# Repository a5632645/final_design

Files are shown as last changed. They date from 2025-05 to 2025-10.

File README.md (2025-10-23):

# final_design/毕业设计
This is my final design.  
这是我的本科毕业设计.  
> [!WARNING]
> don't try to rebuild hardware, it has too many incorrect design, that will just waste your time and money.  
> 请不要试着复刻硬件，有很多设计不合理的地方，复刻只会浪费你的时间和钱  

# digital waveguide synthesizer/数字波导合成器  
This is a MPE capability digital waveguide synthesizer.It has plucked, woodwind and bowed engine.Or you can use it as a MPE midi keyboard(only one octave).  
这是一个mpe兼容的数字波导合成器，有拨弦，木管和弓弦模型，也可以当成mpe键盘使用，尽管只有一个八度。  
# demo/演示
https://www.bilibili.com/video/BV1ghJGzJEi4/
# bug
硬件中含有较多问题  
the hardware has many bugs.

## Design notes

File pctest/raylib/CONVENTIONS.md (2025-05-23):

## C Coding Style Conventions

Here is a list with some of the code conventions used by raylib:

Code element | Convention | Example
--- | :---: | ---
Defines | ALL_CAPS | `#define PLATFORM_DESKTOP`
Macros | ALL_CAPS | `#define MIN(a,b) (((a)<(b))?(a):(b))`
Variables | lowerCase | `int screenWidth = 0;`, `float targetFrameTime = 0.016f;`
Local variables | lowerCase | `Vector2 playerPosition = { 0 };`
Global variables | lowerCase | `bool windowReady = false;`
Constants | lowerCase | `const int maxValue = 8;`
Pointers | MyType *pointer | `Texture2D *array = NULL;`
float values | always x.xf | `float gravity = 10.0f`
Operators | value1*value2 | `int product = value*6;`
Operators | value1/value2 | `int division = value/4;`
Operators | value1 + value2 | `int sum = value + 10;`
Operators | value1 - value2 | `int res = value - 5;`
Enum | TitleCase | `enum TextureFormat`
Enum members | ALL_CAPS | `PIXELFORMAT_UNCOMPRESSED_R8G8B8`
Struct | TitleCase | `struct Texture2D`, `struct Material`
Struct members | lowerCase | `texture.width`, `color.r`
Functions | TitleCase | `InitWindow()`, `LoadImageFromMemory()`
Functions params | lowerCase | `width`, `height`
Ternary Operator | (condition)? result1 : result2 | `printf("Value is 0: %s", (value == 0)? "yes" : "no");`

Some other conventions to follow:
 - **ALWAYS** initialize all defined variables.
 - **Do not use TABS**, use 4 spaces instead.
 - Avoid trailing spaces, please, avoid them
 - Control flow statements always are followed **by a space**:
```c
if (condition) value = 0;

while (!WindowShouldClose())
{

}

for (int i = 0; i < NUM_VALUES; i++) printf("%i", i);

// Be careful with the switch formatting!
switch (value)
{
    case 0:
    {

    } break;
    case 2: break;
    default: break;
}
```
 - All conditions checks are **always between parenthesis** but not boolean values:
```c
if ((value > 1) && (value < 50) && valueActive)
{

}
```
 - When dealing with braces or curly brackets, open-close them in aligned mode:
```c
void SomeFunction()
{
   // TODO: Do something here!
}
```

**If proposing new functions, please try to use a clear naming for function-name and functions-parameters, in case of doubt, open an issue for discussion.**

## Files and Directories Naming Conventions
 
  - Directories will be named using `snake_case`: `resources/models`, `resources/fonts`
  
  - Files will be named using `snake_case`: `main_title.png`, `cubicmap.png`, `sound.wav`
  
_NOTE: Avoid any space or special character in the files/dir naming!_
  
## Games/Examples Directories Organization Conventions
  
 - Data files should be organized by context and usage in the game, think about the loading requirements for data and put all the resources that need to be loaded at the same time together.
 - Use descriptive names for the files, it would be perfect if just reading the name of the file, it was possible to know what is that file and where fits in the game.
 - Here is an example, note that some resources require to be loaded all at once while other require to be loaded only at initialization (gui, font).
  
```
resources/audio/fx/long_jump.wav
resources/audio/music/main_theme.ogg
resources/screens/logo/logo.png
resources/screens/title/title.png
resources/screens/gameplay/background.png
resources/characters/player.png
resources/characters/enemy_slime.png
resources/common/font_arial.ttf
resources/common/gui.png
```

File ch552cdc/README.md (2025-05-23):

# 使用VsCode + SDCC +CMake 的51单片机项目模版

本仓库基于[sinojerk](https://github.com/sinojerk)/[mcs51-examples](https://github.com/sinojerk/mcs51-examples)做了符合个人习惯的些许修改

用做本人快速搭建SDCC-CMake-51单片机项目的模版

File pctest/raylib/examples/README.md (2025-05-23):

## Building the Examples

The examples assume you have already built the `raylib` library in `../src`.

### With GNU make

- `make` builds all examples
- `make [module]` builds all examples for a particular module (e.g `make core`)

### With Zig

The [Zig](https://ziglang.org/) toolchain can compile `C` and `C++` in addition to `Zig`.
You may find it easier to use than other toolchains, especially when it comes to cross-compiling.

- `zig build` to compile all examples
- `zig build [module]` to compile all examples for a module (e.g. `zig build core`)
- `zig build [example]` to compile _and run_ a particular example (e.g. `zig build core_basic_window`)

## EXAMPLES LIST

### category: core

Examples using raylib core platform functionality like window creation, inputs, drawing modes and system functionality.

| ## | example  | image  | difficulty<br>level | version<br>created | last version<br>updated | original<br>developer |
|----|---|---|:---:|:---:|:---:|:---|
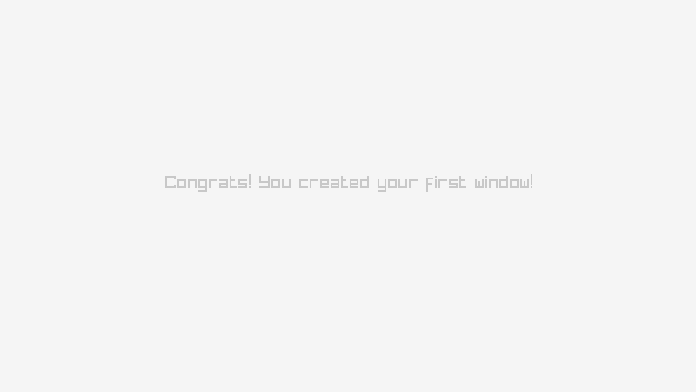
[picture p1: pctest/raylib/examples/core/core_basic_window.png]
core_basic_window
| 01 | [core_basic_window](core/core_basic_window.c) |  | ⭐️☆☆☆ | 1.0 | 1.0 | [Ray](https://github.com/raysan5) |
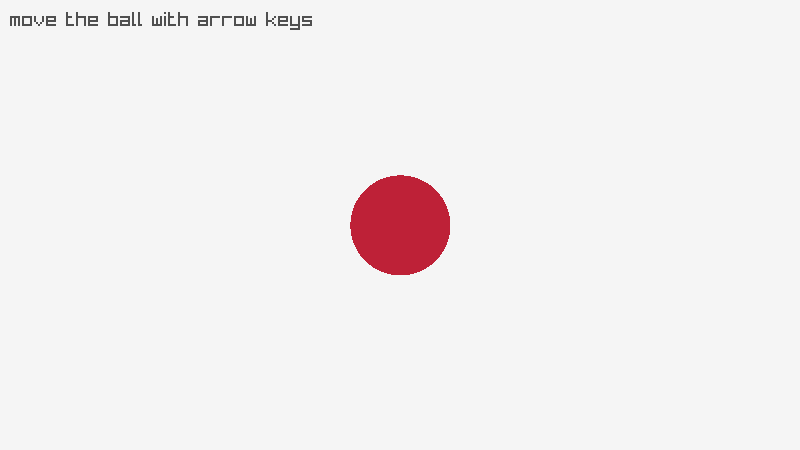
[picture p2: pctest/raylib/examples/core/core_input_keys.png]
core_input_keys
| 02 | [core_input_keys](core/core_input_keys.c) |  | ⭐️☆☆☆ | 1.0 | 1.0 | [Ray](https://github.com/raysan5) |
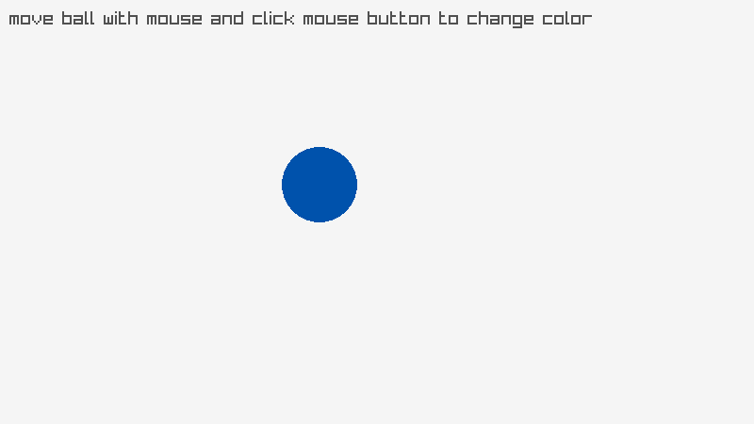
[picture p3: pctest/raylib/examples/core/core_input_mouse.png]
core_input_mouse
| 03 | [core_input_mouse](core/core_input_mouse.c) |  | ⭐️☆☆☆ | 1.0 | **4.0** | [Ray](https://github.com/raysan5) |
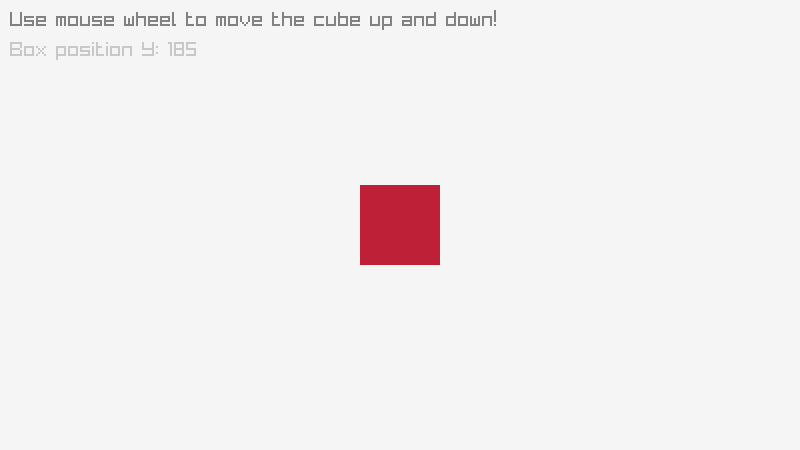
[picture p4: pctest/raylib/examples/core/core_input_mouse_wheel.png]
core_input_mouse_wheel
| 04 | [core_input_mouse_wheel](core/core_input_mouse_wheel.c) |  | ⭐️☆☆☆ | 1.1 | 1.3 | [Ray](https://github.com/raysan5) |
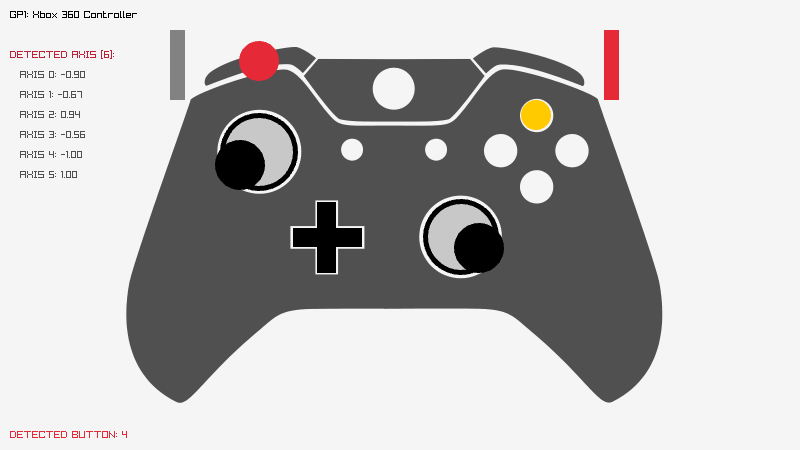
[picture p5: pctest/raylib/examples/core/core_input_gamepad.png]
core_input_gamepad
| 05 | [core_input_gamepad](core/core_input_gamepad.c) |  | ⭐️☆☆☆ | 1.1 | **4.2** | [Ray](https://github.com/raysan5) |
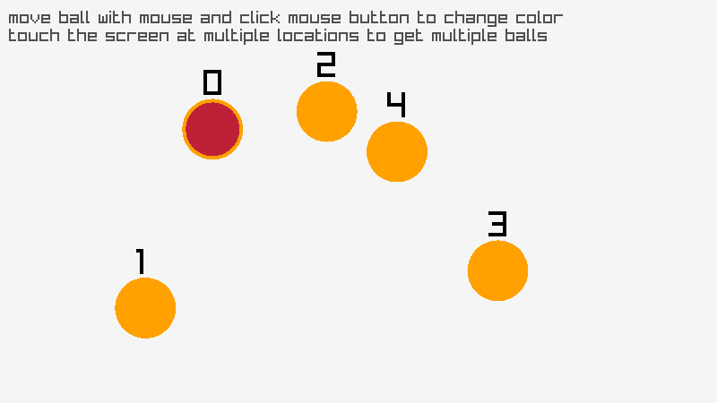
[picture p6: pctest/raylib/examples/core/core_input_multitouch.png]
core_input_multitouch
| 06 | [core_input_multitouch](core/core_input_multitouch.c) |  | ⭐️☆☆☆ | 2.1 | 2.5 | [Berni](https://github.com/Berni8k) |
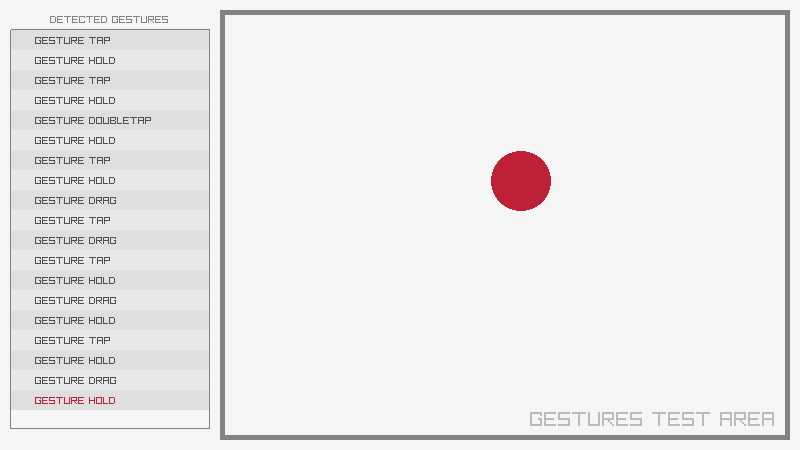
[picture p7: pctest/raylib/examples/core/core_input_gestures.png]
core_input_gestures
| 07 | [core_input_gestures](core/core_input_gestures.c) |  | ⭐️⭐️☆☆ | 1.4 | **4.2** | [Ray](https://github.com/raysan5) |
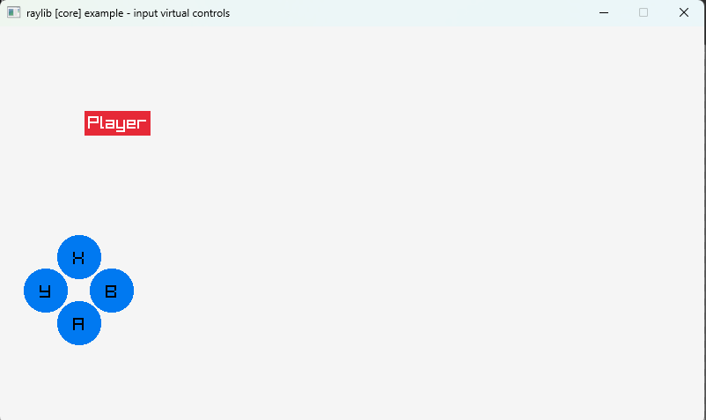
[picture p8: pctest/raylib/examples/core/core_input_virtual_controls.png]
core_input_virtual_controls
| 08 | [core_input_virtual_controls](core/core_input_virtual_controls.c) |  | ⭐️⭐️☆☆ | **5.0** | **5.0** | [oblerion](https://github.com/oblerion) |
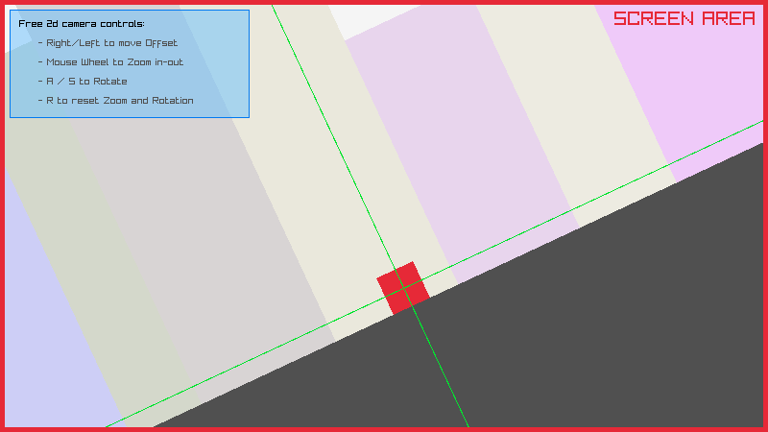
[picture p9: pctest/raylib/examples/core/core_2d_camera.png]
core_2d_camera
| 09 | [core_2d_camera](core/core_2d_camera.c) |  | ⭐️⭐️☆☆ | 1.5 | 3.0 | [Ray](https://github.com/raysan5) |
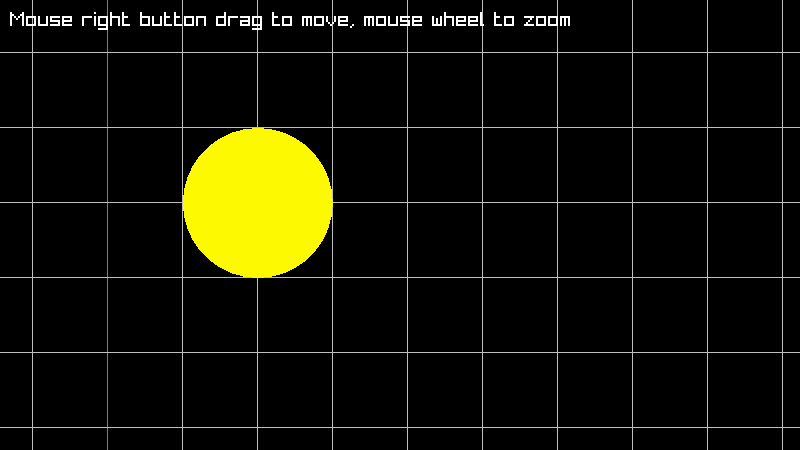
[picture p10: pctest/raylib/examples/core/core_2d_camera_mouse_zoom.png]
core_2d_camera_mouse_zoom
| 10 | [core_2d_camera_mouse_zoom](core/core_2d_camera_mouse_zoom.c) |  | ⭐️⭐️☆☆ | **4.2** | **4.2** | [Jeffery Myers](https://github.com/JeffM2501) |
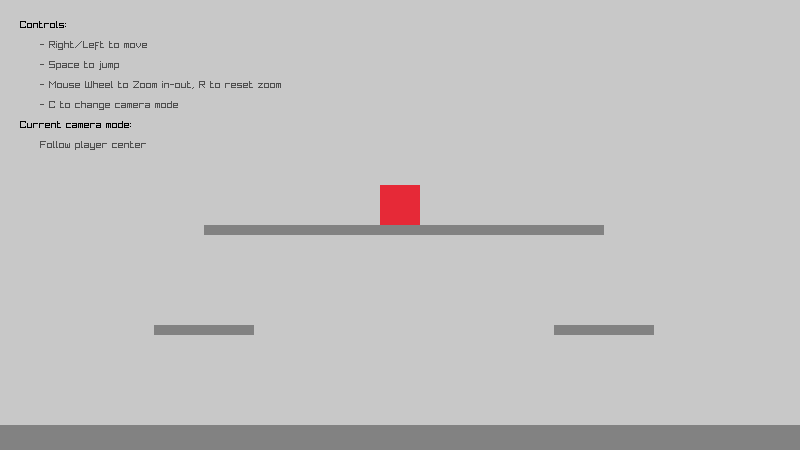
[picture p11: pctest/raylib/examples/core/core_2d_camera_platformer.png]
core_2d_camera_platformer
| 11 | [core_2d_camera_platformer](core/core_2d_camera_platformer.c) |  | ⭐️⭐️⭐️☆ | 2.5 | 3.0 | [avyy](https://github.com/avyy) |
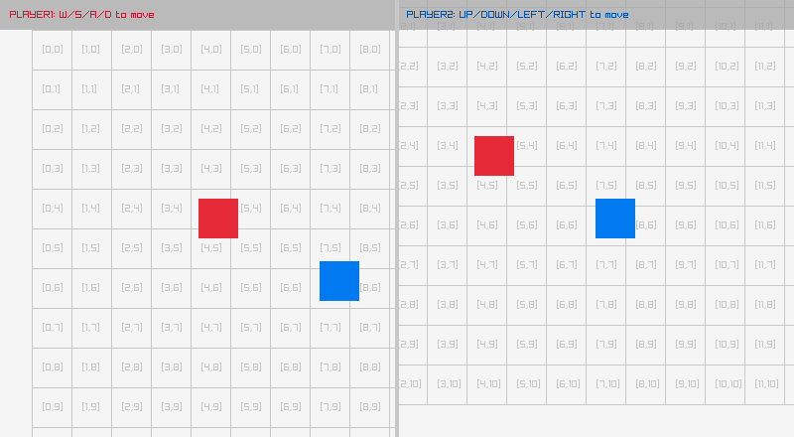
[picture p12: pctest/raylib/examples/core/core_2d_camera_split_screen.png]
core_2d_camera_split_screen
| 12 | [core_2d_camera_split_screen](core/core_2d_camera_split_screen.c) |  | ⭐️⭐️⭐️⭐️ | **4.5** | **4.5** | [Gabriel dos Santos Sanches](https://github.com/gabrielssanches) |
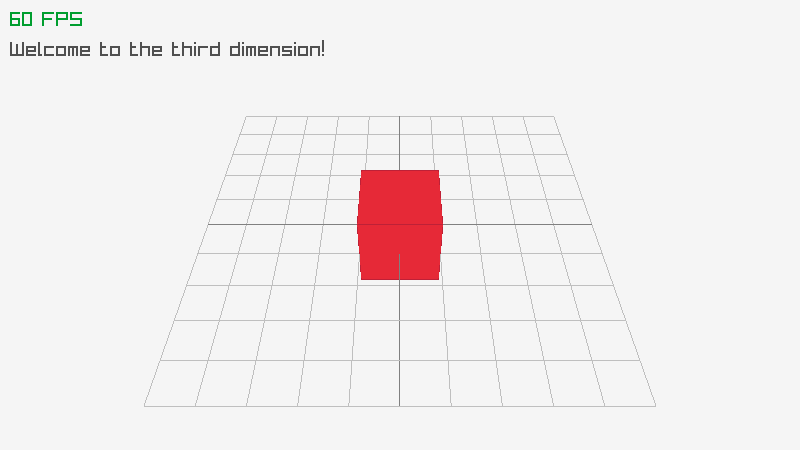
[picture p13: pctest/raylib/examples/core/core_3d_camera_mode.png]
core_3d_camera_mode
| 13 | [core_3d_camera_mode](core/core_3d_camera_mode.c) |  | ⭐️☆☆☆ | 1.0 | 1.0 | [Ray](https://github.com/raysan5) |
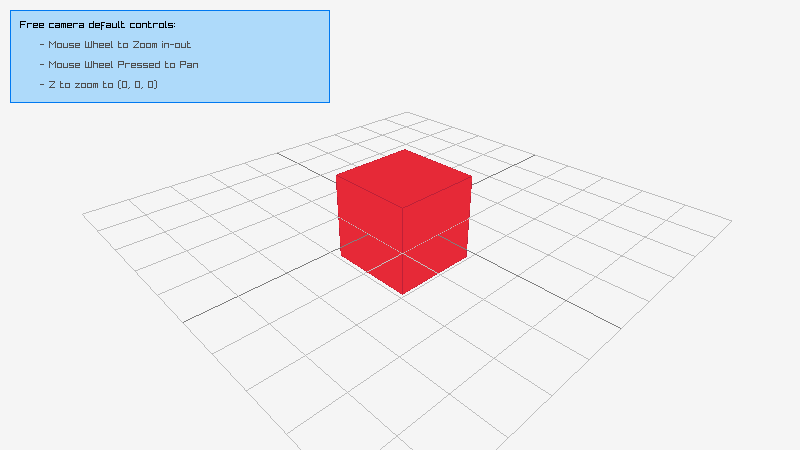
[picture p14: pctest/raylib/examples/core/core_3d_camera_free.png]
core_3d_camera_free
| 14 | [core_3d_camera_free](core/core_3d_camera_free.c) |  | ⭐️☆☆☆ | 1.3 | 1.3 | [Ray](https://github.com/raysan5) |
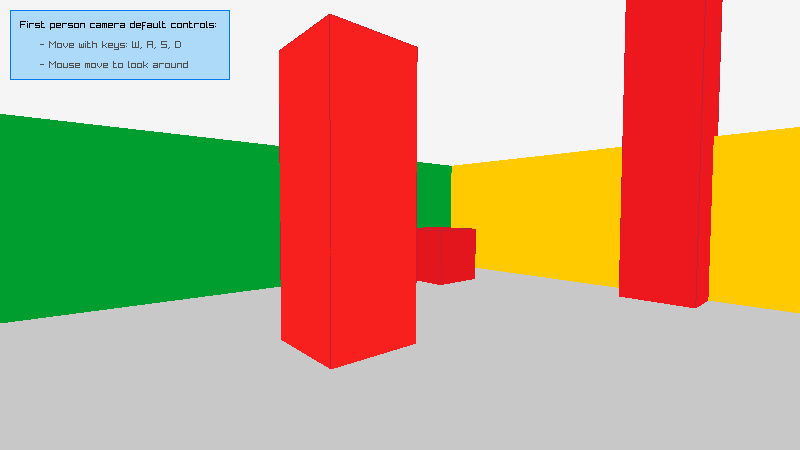
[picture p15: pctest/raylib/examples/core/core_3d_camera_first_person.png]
core_3d_camera_first_person
| 15 | [core_3d_camera_first_person](core/core_3d_camera_first_person.c) |  | ⭐️⭐️☆☆ | 1.3 | 1.3 | [Ray](https://github.com/raysan5) |
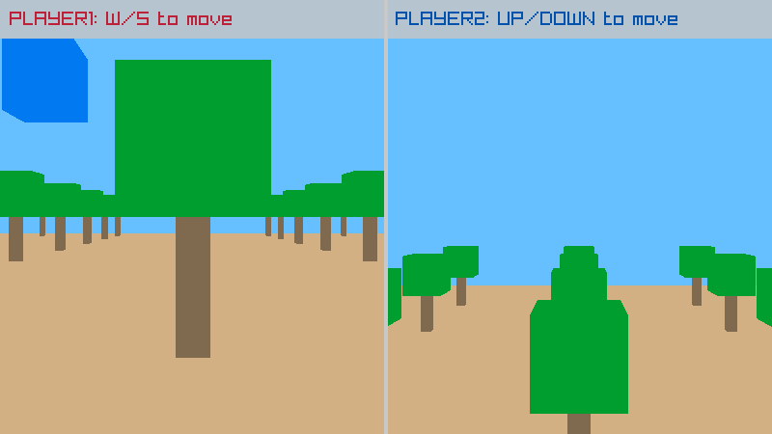
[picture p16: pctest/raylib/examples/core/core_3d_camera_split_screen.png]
core_3d_camera_split_screen
| 16 | [core_3d_camera:split_screen](core/core_3d_camera_split_screen.c) |  | ⭐️⭐️⭐️⭐️ | 3.7 | **4.0** | [Jeffery Myers](https://github.com/JeffM2501) |
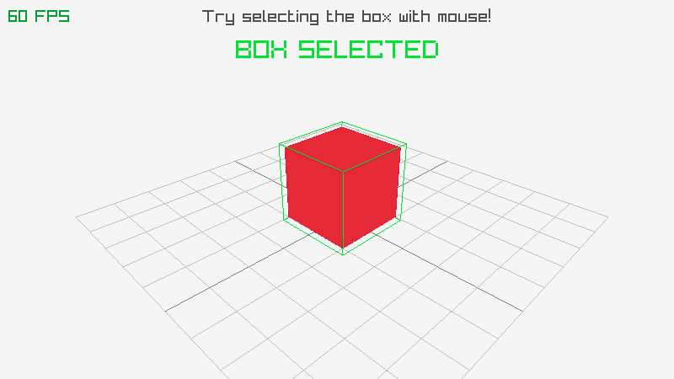
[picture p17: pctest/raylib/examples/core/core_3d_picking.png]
core_3d_picking
| 17 | [core_3d_picking](core/core_3d_picking.c) |  | ⭐️⭐️☆☆ | 1.3 | **4.0** | [Ray](https://github.com/raysan5) |
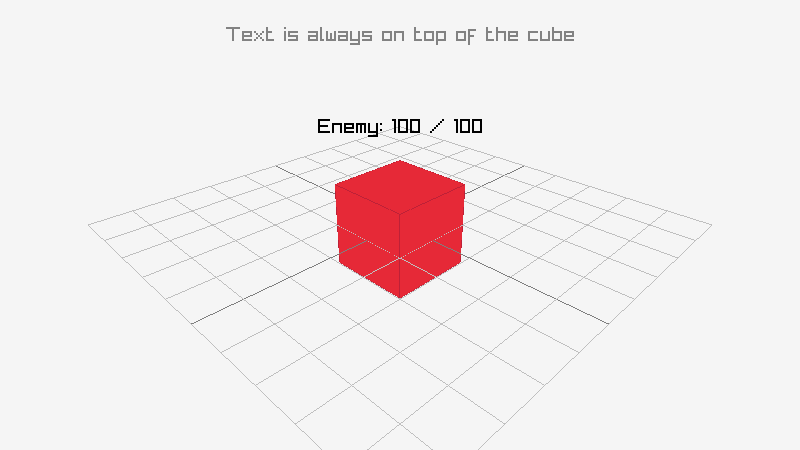
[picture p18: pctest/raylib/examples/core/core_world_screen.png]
core_world_screen
| 18 | [core_world_screen](core/core_world_screen.c) |  | ⭐️⭐️☆☆ | 1.3 | 1.4 | [Ray](https://github.com/raysan5) |
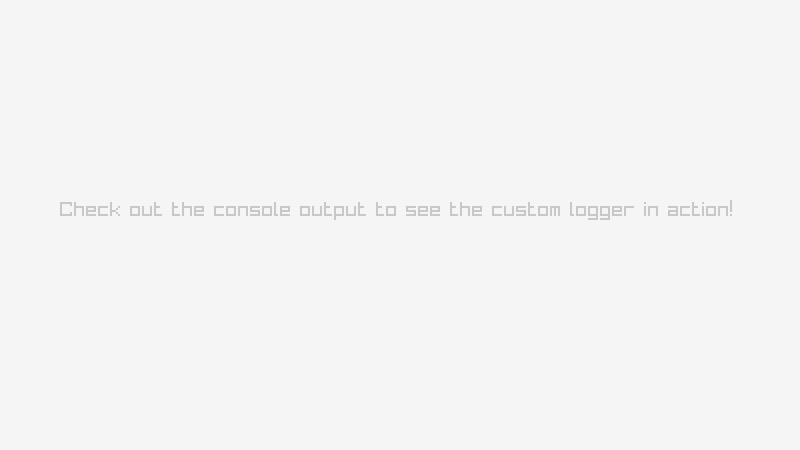
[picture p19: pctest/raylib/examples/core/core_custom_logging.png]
core_custom_logging
| 19 | [core_custom_logging](core/core_custom_logging.c) |  | ⭐️⭐️⭐️☆ | 2.5 | 2.5 | [Pablo Marcos Oltra](https://github.com/pamarcos) |
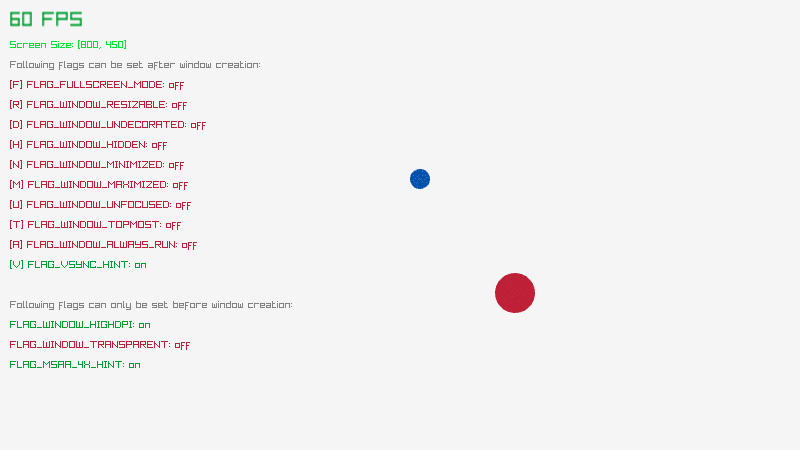
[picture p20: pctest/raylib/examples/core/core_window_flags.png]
core_window_flags
| 20 | [core_window_flags](core/core_window_flags.c) |  | ⭐️⭐️⭐️☆ | 3.5 | 3.5 | [Ray](https://github.com/raysan5) |
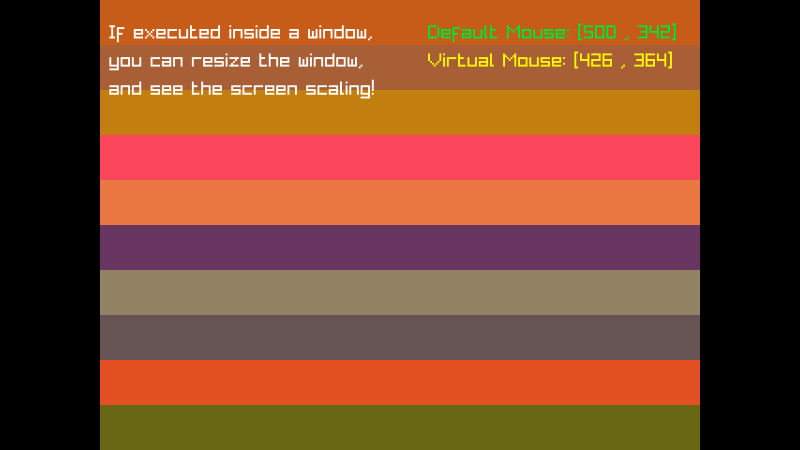
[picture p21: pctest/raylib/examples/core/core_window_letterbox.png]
core_window_letterbox
| 21 | [core_window_letterbox](core/core_window_letterbox.c) |  | ⭐️⭐️☆☆ | 2.5 | **4.0** | [Anata](https://github.com/anatagawa) |
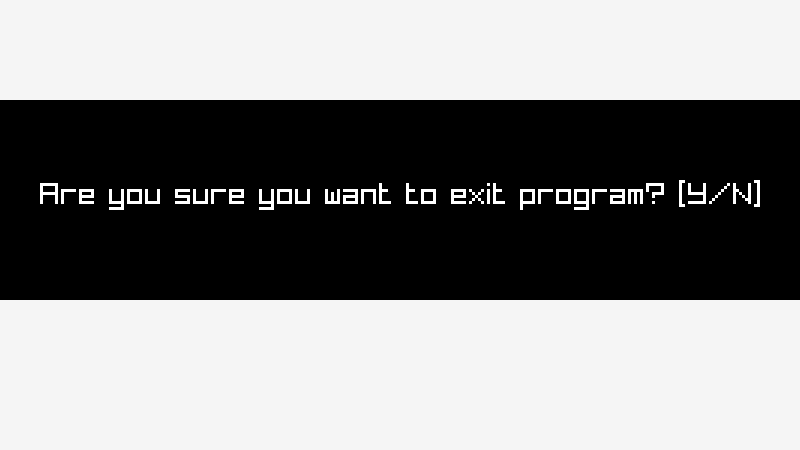
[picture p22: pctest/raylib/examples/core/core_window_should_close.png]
core_window_should_close
| 22 | [core_window_should_close](core/core_window_should_close.c) |  | ⭐️☆☆☆ | **4.2** | **4.2** | [Ray](https://github.com/raysan5) |
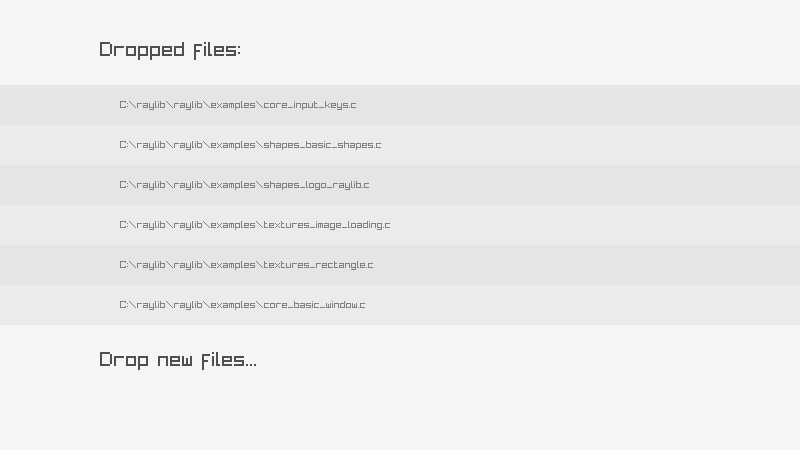
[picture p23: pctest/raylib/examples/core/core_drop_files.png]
core_drop_files
| 23 | [core_drop_files](core/core_drop_files.c) |  | ⭐️⭐️☆☆ | 1.3 | **4.2** | [Ray](https://github.com/raysan5) |
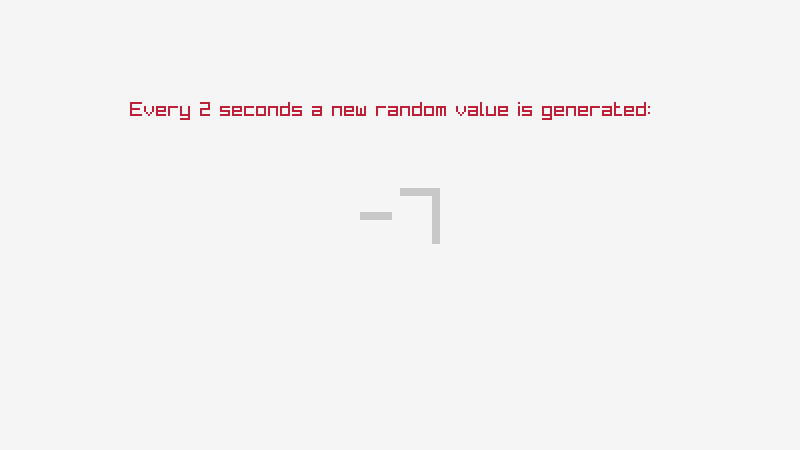
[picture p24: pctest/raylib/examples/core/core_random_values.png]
core_random_values
| 24 | [core_random_values](core/core_random_values.c) |  | ⭐️☆☆☆ | 1.1 | 1.1 | [Ray](https://github.com/raysan5) |
| 25 | [core_storage_values](core/core_storage_values.c) | core_storage_values | ⭐️⭐️☆☆ | 1.4 | **4.2** | [Ray](https://github.com/raysan5) |
| 26 | [core_vr_simulator](core/core_vr_simulator.c) | core_vr_simulator | ⭐️⭐️⭐️☆ | 2.5 | **4.0** | [Ray](https://github.com/raysan5) |
| 27 | [core_loading_thread](core/core_loading_thread.c) | core_loading_thread | ⭐️⭐️⭐️☆ | 2.5 | 3.0 | [Ray](https://github.com/raysan5) |
| 28 | [core_scissor_test](core/core_scissor_test.c) | core_scissor_test | ⭐️☆☆☆ | 2.5 | 3.0 | [Chris Dill](https://github.com/MysteriousSpace) |
| 29 | [core_basic_screen_manager](core/core_basic_screen_manager.c) | core_basic_screen_manager | ⭐️☆☆☆ | **4.0** | **4.0** | [Ray](https://github.com/raysan5) |
| 30 | [core_custom_frame_control](core/core_custom_frame_control.c) | core_custom_frame_control | ⭐️⭐️⭐️⭐️ | **4.0** | **4.0** | [Ray](https://github.com/raysan5) |
| 31 | [core_smooth_pixelperfect](core/core_smooth_pixelperfect.c) | core_smooth_pixelperfect | ⭐️⭐️⭐️☆ | 3.7 | **4.0** | [Giancamillo Alessandroni](https://github.com/NotManyIdeasDev) |
| 32 | [core_window_should_close](core/core_window_should_close.c) | core_window_should_close | ⭐️⭐️☆☆ | **4.2** | **4.2** | [Ray](https://github.com/raysan5) |
| 33 | [core_random_sequence](core/core_random_sequence.c) | core_random_sequence | ⭐️☆☆☆ | **5.0** | **5.0** | [REDl3east](https://github.com/REDl3east) |

### category: shapes

Examples using raylib shapes drawing functionality, provided by raylib [shapes](../src/shapes.c) module.

| ## | example  | image  | difficulty<br>level | version<br>created | last version<br>updated | original<br>developer |
|----|---|---|:---:|:---:|:---:|:---|
| 34 | [shapes_basic_shapes](shapes/shapes_basic_shapes.c) | shapes_basic_shapes | ⭐️☆☆☆ | 1.0 | **4.0** | [Ray](https://github.com/raysan5) |
| 35 | [shapes_bouncing_ball](shapes/shapes_bouncing_ball.c) | shapes_bouncing_ball | ⭐️☆☆☆ | 2.5 | 2.5 | [Ray](https://github.com/raysan5) |
| 36 | [shapes_colors_palette](shapes/shapes_colors_palette.c) | shapes_colors_palette | ⭐️⭐️☆☆ | 1.0 | 2.5 | [Ray](https://github.com/raysan5) |
| 37 | [shapes_logo_raylib](shapes/shapes_logo_raylib.c) | shapes_logo_raylib | ⭐️☆☆☆ | 1.0 | 1.0 | [Ray](https://github.com/raysan5) |
| 38 | [shapes_logo_raylib_anim](shapes/shapes_logo_raylib_anim.c) | shapes_logo_raylib_anim | ⭐️⭐️☆☆ | 2.5 | **4.0** | [Ray](https://github.com/raysan5) |
| 39 | [shapes_rectangle_scaling](shapes/shapes_rectangle_scaling.c) | shapes_rectangle_scaling | ⭐️⭐️☆☆ | 2.5 | 2.5 | [Vlad Adrian](https://github.com/demizdor) |
| 40 | [shapes_lines_bezier](shapes/shapes_lines_bezier.c) | shapes_lines_bezier | ⭐️☆☆☆ | 1.7 | 1.7 | [Ray](https://github.com/raysan5) |
| 41 | [shapes_collision_area](shapes/shapes_collision_area.c) | shapes_collision_area | ⭐️⭐️☆☆ | 2.5 | 2.5 | [Ray](https://github.com/raysan5) |
| 42 | [shapes_following_eyes](shapes/shapes_following_eyes.c) | shapes_following_eyes | ⭐️⭐️☆☆ | 2.5 | 2.5 | [Ray](https://github.com/raysan5) |
| 43 | [shapes_easings_ball_anim](shapes/shapes_easings_ball_anim.c) | shapes_easings_ball_anim | ⭐️⭐️☆☆ | 2.5 | 2.5 | [Ray](https://github.com/raysan5) |
| 44 | [shapes_easings_box_anim](shapes/shapes_easings_box_anim.c) | shapes_easings_box_anim | ⭐️⭐️☆☆ | 2.5 | 2.5 | [Ray](https://github.com/raysan5) |
| 45 | [shapes_easings_rectangle_array](shapes/shapes_easings_rectangle_array.c) | shapes_easings_rectangle_array | ⭐️⭐️⭐️☆ | 2.5 | 2.5 | [Ray](https://github.com/raysan5) |
| 46 | [shapes_draw_ring](shapes/shapes_draw_ring.c) | shapes_draw_ring | ⭐️⭐️⭐️☆ | 2.5 | 2.5 | [Vlad Adrian](https://github.com/demizdor) |
| 47 | [shapes_draw_circle_sector](shapes/shapes_draw_circle_sector.c) | shapes_draw_circle_sector | ⭐️⭐️⭐️☆ | 2.5 | 2.5 | [Vlad Adrian](https://github.com/demizdor) |
| 48 | [shapes_draw_rectangle_rounded](shapes/shapes_draw_rectangle_rounded.c) | shapes_draw_rectangle_rounded | ⭐️⭐️⭐️☆ | 2.5 | 2.5 | [Vlad Adrian](https://github.com/demizdor) |
| 49 | [shapes_top_down_lights](shapes/shapes_top_down_lights.c) | shapes_top_down_lights | ⭐️⭐️⭐️⭐️ | **4.2** | **4.2** | [Jeffery Myers](https://github.com/JeffM2501) |
| 50 | [shapes_rectangle_advanced](shapes/shapes_rectangle_advanced.c) | shapes_rectangle_advanced | ⭐️⭐️⭐️⭐️⭐️| **5.0** | **5.0** | [ExCyber](https://github.com/evertonse) |

### category: textures

Examples using raylib textures functionality, including image/textures loading/generation and drawing, provided by raylib [textures](../src/textures.c) module.

| ## | example  | image  | difficulty<br>level | version<br>created | last version<br>updated | original<br>developer |
|----|---|---|:---:|:---:|:---:|:---|
| 51 | [textures_logo_raylib](textures/textures_logo_raylib.c) | textures_logo_raylib | ⭐️☆☆☆ | 1.0 | 1.0 | [Ray](https://github.com/raysan5) |
| 52 | [textures_srcrec_dstrec](textures/textures_srcrec_dstrec.c) | textures_srcrec_dstrec | ⭐️⭐️⭐️☆ | 1.3 | 1.3 | [Ray](https://github.com/raysan5) |
| 53 | [textures_image_drawing](textures/textures_image_drawing.c) | textures_image_drawing | ⭐️⭐️☆☆ | 1.4 | 1.4 | [Ray](https://github.com/raysan5) |
| 54 | [textures_image_generation](textures/textures_image_generation.c) | textures_image_generation | ⭐️⭐️☆☆ | 1.8 | 1.8 | [Ray](https://github.com/raysan5) |
| 55 | [textures_image_loading](textures/textures_image_loading.c) | textures_image_loading | ⭐️☆☆☆ | 1.3 | 1.3 | [Ray](https://github.com/raysan5) |
| 56 | [textures_image_processing](textures/textures_image_processing.c) | textures_image_processing | ⭐️⭐️⭐️☆ | 1.4 | 3.5 | [Ray](https://github.com/raysan5) |
| 57 | [textures_image_text](textures/textures_image_text.c) | textures_image_text | ⭐️⭐️☆☆ | 1.8 | **4.0** | [Ray](https://github.com/raysan5) |
| 58 | [textures_to_image](textures/textures_to_image.c) | textures_to_image | ⭐️☆☆☆ | 1.3 | **4.0** | [Ray](https://github.com/raysan5) |
| 59 | [textures_raw_data](textures/textures_raw_data.c) | textures_raw_data | ⭐️⭐️⭐️☆ | 1.3 | 3.5 | [Ray](https://github.com/raysan5) |
| 60 | [textures_particles_blending](textures/textures_particles_blending.c) | textures_particles_blending | ⭐️☆☆☆ | 1.7 | 3.5 | [Ray](https://github.com/raysan5) |
| 61 | [textures_npatch_drawing](textures/textures_npatch_drawing.c) | textures_npatch_drawing | ⭐️⭐️⭐️☆ | 2.0 | 2.5 | [Jorge A. Gomes](https://github.com/overdev) |
| 62 | [textures_background_scrolling](textures/textures_background_scrolling.c) | textures_background_scrolling | ⭐️☆☆☆ | 2.0 | 2.5 | [Ray](https://github.com/raysan5) |
| 63 | [textures_sprite_anim](textures/textures_sprite_anim.c) | textures_sprite_anim | ⭐️⭐️☆☆ | 1.3 | 1.3 | [Ray](https://github.com/raysan5) |
| 64 | [textures_sprite_button](textures/textures_sprite_button.c) | textures_sprite_button | ⭐️⭐️☆☆ | 2.5 | 2.5 | [Ray](https://github.com/raysan5) |
| 65 | [textures_sprite_explosion](textures/textures_sprite_explosion.c) | textures_sprite_explosion | ⭐️⭐️☆☆ | 2.5 | 3.5 | [Ray](https://github.com/raysan5) |
| 66 | [textures_bunnymark](textures/textures_bunnymark.c) | textures_bunnymark | ⭐️⭐️⭐️☆ | 1.6 | 2.5 | [Ray](https://github.com/raysan5) |
| 67 | [textures_mouse_painting](textures/textures_mouse_painting.c) | textures_mouse_painting | ⭐️⭐️⭐️☆ | 3.0 | 3.0 | [Chris Dill](https://github.com/MysteriousSpace) |
| 68 | [textures_blend_modes](textures/textures_blend_modes.c) | textures_blend_modes | ⭐️☆☆☆ | 3.5 | 3.5 | [Karlo Licudine](https://github.com/accidentalrebel) |
| 69 | [textures_draw_tiled](textures/textures_draw_tiled.c) | textures_draw_tiled | ⭐️⭐️⭐️☆ | 3.0 | **4.2** | [Vlad Adrian](https://github.com/demizdor) |
| 70 | [textures_polygon](textures/textures_polygon.c) | textures_polygon | ⭐️☆☆☆ | 3.7 | 3.7 | [Chris Camacho](https://github.com/codifies) |
| 71 | [textures_fog_of_war](textures/textures_fog_of_war.c) | textures_fog_of_war | ⭐️⭐️⭐️☆ | **4.2** | **4.2** | [Ray](https://github.com/raysan5) |
| 72 | [textures_gif_player](textures/textures_gif_player.c) | textures_gif_player | ⭐️⭐️⭐️☆ | **4.2** | **4.2** | [Ray](https://github.com/raysan5) |

### category: text

Examples using raylib text functionality, including sprite fonts loading/generation and text drawing, provided by raylib [text](../src/text.c) module.

| ## | example  | image  | difficulty<br>level | version<br>created | last version<br>updated | original<br>developer |
|----|---|---|:---:|:---:|:---:|:---|
| 73 | [text_raylib_fonts](text/text_raylib_fonts.c) | text_raylib_fonts | ⭐️☆☆☆ | 1.7 | 3.7 | [Ray](https://github.com/raysan5) |
| 74 | [text_font_spritefont](text/text_font_spritefont.c) | text_font_spritefont | ⭐️☆☆☆ | 1.0 | 1.0 | [Ray](https://github.com/raysan5) |
| 75 | [text_font_filters](text/text_font_filters.c) | text_font_filters | ⭐️⭐️☆☆ | 1.3 | **4.2** | [Ray](https://github.com/raysan5) |
| 76 | [text_font_loading](text/text_font_loading.c) | text_font_loading | ⭐️☆☆☆ | 1.4 | 3.0 | [Ray](https://github.com/raysan5) |
| 77 | [text_font_sdf](text/text_font_sdf.c) | text_font_sdf | ⭐️⭐️⭐️☆ | 1.3 | **4.0** | [Ray](https://github.com/raysan5) |
| 78 | [text_format_text](text/text_format_text.c) | text_format_text | ⭐️☆☆☆ | 1.1 | 3.0 | [Ray](https://github.com/raysan5) |
| 79 | [text_input_box](text/text_input_box.c) | text_input_box | ⭐️⭐️☆☆ | 1.7 | 3.5 | [Ray](https://github.com/raysan5) |
| 80 | [text_writing_anim](text/text_writing_anim.c) | text_writing_anim | ⭐️⭐️☆☆ | 1.4 | 1.4 | [Ray](https://github.com/raysan5) |
| 81 | [text_rectangle_bounds](text/text_rectangle_bounds.c) | text_rectangle_bounds | ⭐️⭐️⭐️⭐️ | 2.5 | **4.0** | [Vlad Adrian](https://github.com/demizdor) |
| 82 | [text_unicode](text/text_unicode.c) | text_unicode | ⭐️⭐️⭐️⭐️ | 2.5 | **4.0** | [Vlad Adrian](https://github.com/demizdor) |
| 83 | [text_draw_3d](text/text_draw_3d.c) | text_draw_3d | ⭐️⭐️⭐️⭐️ | 3.5 | **4.0** | [Vlad Adrian](https://github.com/demizdor) |
| 84 | [text_codepoints_loading](text/text_codepoints_loading.c) | text_codepoints_loading | ⭐️⭐️⭐️☆ | **4.2** | **4.2** | [Ray](https://github.com/raysan5) |

### category: models

Examples using raylib models functionality, including models loading/generation and drawing, provided by raylib [models](../src/models.c) module.

| ## | example  | image  | difficulty<br>level | version<br>created | last version<br>updated | original<br>developer |
|----|---|---|:---:|:---:|:---:|:---|
| 85 | [models_animation](models/models_animation.c) | models_animation | ⭐️⭐️☆☆ | 2.5 | 3.5 | [culacant](https://github.com/culacant) |
| 86 | [models_billboard](models/models_billboard.c) | models_billboard | ⭐️⭐️⭐️☆ | 1.3 | 3.5 | [Ray](https://github.com/raysan5) |
| 87 | [models_box_collisions](models/models_box_collisions.c) | models_box_collisions | ⭐️☆☆☆ | 1.3 | 3.5 | [Ray](https://github.com/raysan5) |
| 88 | [models_cubicmap](models/models_cubicmap.c) | models_cubicmap | ⭐️⭐️☆☆ | 1.8 | 3.5 | [Ray](https://github.com/raysan5) |
| 89 | [models_first_person_maze](models/models_first_person_maze.c) | models_first_person_maze | ⭐️⭐️☆☆ | 2.5 | 3.5 | [Ray](https://github.com/raysan5) |
| 90 | [models_geometric_shapes](models/models_geometric_shapes.c) | models_geometric_shapes | ⭐️☆☆☆ | 1.0 | 3.5 | [Ray](https://github.com/raysan5) |
| 91 | [models_mesh_generation](models/models_mesh_generation.c) | models_mesh_generation | ⭐️⭐️☆☆ | 1.8 | **4.0** | [Ray](https://github.com/raysan5) |
| 92 | [models_mesh_picking](models/models_mesh_picking.c) | models_mesh_picking | ⭐️⭐️⭐️☆ | 1.7 | **4.0** | [Joel Davis](https://github.com/joeld42) |
| 93 | [models_loading](models/models_loading.c) | models_loading | ⭐️☆☆☆ | 2.5 | **4.0** | [Ray](https://github.com/raysan5) |
| 94 | [models_loading_gltf](models/models_loading_gltf.c) | models_loading_gltf | ⭐️☆☆☆ | 3.7 | **4.2** | [Ray](https://github.com/raysan5) |
| 95 | [models_loading_vox](models/models_loading_vox.c) | models_loading_vox | ⭐️☆☆☆ | **4.0** | **4.0** | [Johann Nadalutti](https://github.com/procfxgen) |
| 96 | [models_loading_m3d](models/models_loading_m3d.c) | models_loading_m3d | ⭐️☆☆☆ | **4.2** | **4.2** | [bzt](https://bztsrc.gitlab.io/model3d) |
| 97 | [models_orthographic_projection](models/models_orthographic_projection.c) | models_orthographic_projection | ⭐️☆☆☆ | 2.0 | 3.7 | [Max Danielsson](https://github.com/autious) |
| 98 | [models_point_rendering](models/models_point_rendering.c) | models_point_rendering | ⭐️⭐️☆☆ | 5.0 | 5.0 | [Reese Gallagher](https://github.com/satchelfrost) |
| 99 | [models_rlgl_solar_system](models/models_rlgl_solar_system.c) | models_rlgl_solar_system | ⭐️⭐️⭐️⭐️ | 2.5 | **4.0** | [Ray](https://github.com/raysan5) |
| 100 | [models_yaw_pitch_roll](models/models_yaw_pitch_roll.c) | models_yaw_pitch_roll | ⭐️⭐️☆☆ | 1.8 | **4.0** | [Berni](https://github.com/Berni8k) |
| 101 | [models_waving_cubes](models/models_waving_cubes.c) | models_waving_cubes | ⭐️⭐️⭐️☆ | 2.5 | 3.7 | [codecat](https://github.com/codecat) |
| 102 | [models_heightmap](models/models_heightmap.c) | models_heightmap | ⭐️☆☆☆ | 1.8 | 3.5 | [Ray](https://github.com/raysan5) |
| 103 | [models_skybox](models/models_skybox.c) | models_skybox | ⭐️⭐️☆☆ | 1.8 | **4.0** | [Ray](https://github.com/raysan5) |

### category: shaders

Examples using raylib shaders functionality, including shaders loading, parameters configuration and drawing using them (model shaders and postprocessing shaders). This functionality is directly provided by raylib [rlgl](../src/rlgl.c) module.

| ## | example  | image  | difficulty<br>level | version<br>created | last version<br>updated | original<br>developer |
|----|---|---|:---:|:---:|:---:|:---|
| 104 | [shaders_basic_lighting](shaders/shaders_basic_lighting.c) | shaders_basic_lighting | ⭐️⭐️⭐️⭐️ | 3.0 | **4.2** | [Chris Camacho](https://github.com/codifies) |
| 105 | [shaders_model_shader](shaders/shaders_model_shader.c) | shaders_model_shader | ⭐️⭐️☆☆ | 1.3 | 3.7 | [Ray](https://github.com/raysan5) |
| 106 | [shaders_shapes_textures](shaders/shaders_shapes_textures.c) | shaders_shapes_textures | ⭐️⭐️☆☆ | 1.7 | 3.7 | [Ray](https://github.com/raysan5) |
| 107 | [shaders_custom_uniform](shaders/shaders_custom_uniform.c) | shaders_custom_uniform | ⭐️⭐️☆☆ | 1.3 | **4.0** | [Ray](https://github.com/raysan5) |
| 108 | [shaders_postprocessing](shaders/shaders_postprocessing.c) | shaders_postprocessing | ⭐️⭐️⭐️☆ | 1.3 | **4.0** | [Ray](https://github.com/raysan5) |
| 109 | [shaders_palette_switch](shaders/shaders_palette_switch.c) | shaders_palette_switch | ⭐️⭐️⭐️☆ | 2.5 | 3.7 | [Marco Lizza](https://github.com/MarcoLizza) |
| 110 | [shaders_raymarching](shaders/shaders_raymarching.c) | shaders_raymarching | ⭐️⭐️⭐️⭐️ | 2.0 | **4.2** | [Ray](https://github.com/raysan5) |
| 111 | [shaders_texture_drawing](shaders/shaders_texture_drawing.c) | shaders_texture_drawing | ⭐️⭐️☆☆ | 2.0 | 3.7 | [Michał Ciesielski](https://github.com/) |
| 112 | [shaders_texture_outline](shaders/shaders_texture_outline.c) | shaders_texture_outline | ⭐️⭐️⭐️☆ | **4.0** | **4.0** | [Samuel Skiff](https://github.com/GoldenThumbs) |
| 113 | [shaders_texture_waves](shaders/shaders_texture_waves.c) | shaders_texture_waves | ⭐️⭐️☆☆ | 2.5 | 3.7 | [Anata](https://github.com/anatagawa) |
| 114 | [shaders_julia_set](shaders/shaders_julia_set.c) | shaders_julia_set | ⭐️⭐️⭐️☆ | 2.5 | **4.0** | [eggmund](https://github.com/eggmund) |
| 115 | [shaders_eratosthenes](shaders/shaders_eratosthenes.c) | shaders_eratosthenes | ⭐️⭐️⭐️☆ | 2.5 | **4.0** | [ProfJski](https://github.com/ProfJski) |
| 116 | [shaders_fog](shaders/shaders_fog.c) | shaders_fog | ⭐️⭐️⭐️☆ | 2.5 | 3.7 | [Chris Camacho](https://github.com/codifies) |
| 117 | [shaders_simple_mask](shaders/shaders_simple_mask.c) | shaders_simple_mask | ⭐️⭐️☆☆ | 2.5 | 3.7 | [Chris Camacho](https://github.com/codifies) |
| 118 | [shaders_hot_reloading](shaders/shaders_hot_reloading.c) | shaders_hot_reloading | ⭐️⭐️⭐️☆ | 3.0 | 3.5 | [Ray](https://github.com/raysan5) |
| 119 | [shaders_mesh_instancing](shaders/shaders_mesh_instancing.c) | shaders_mesh_instancing | ⭐️⭐️⭐️⭐️ | 3.7 | **4.2** | [seanpringle](https://github.com/seanpringle) |
| 120 | [shaders_multi_sample2d](shaders/shaders_multi_sample2d.c) | shaders_multi_sample2d | ⭐️⭐️☆☆ | 3.5 | 3.5 | [Ray](https://github.com/raysan5) |
| 121 | [shaders_spotlight](shaders/shaders_spotlight.c) | shaders_spotlight | ⭐️⭐️☆☆ | 2.5 | 3.7 | [Chris Camacho](https://github.com/codifies) |
| 122 | [shaders_deferred_render](shaders/shaders_deferred_render.c) | shaders_deferred_render | ⭐️⭐️⭐️⭐️ | 4.5 | 4.5 | [Justin Andreas Lacoste](https://github.com/27justin) |

### category: audio

Examples using raylib audio functionality, including sound/music loading and playing. This functionality is provided by raylib [raudio](../src/raudio.c) module. Note this module can be used standalone independently of raylib, check [raudio_standalone](others/raudio_standalone.c) example.

| ## | example  | image  | difficulty<br>level | version<br>created | last version<br>updated | original<br>developer |
|----|---|---|:---:|:---:|:---:|:---|
| 123 | [audio_module_playing](audio/audio_module_playing.c) | audio_module_playing | ⭐️☆☆☆ | 1.5 | 3.5 | [Ray](https://github.com/raysan5) |
| 124 | [audio_music_stream](audio/audio_music_stream.c) | audio_music_stream | ⭐️☆☆☆ | 1.3 | **4.2** | [Ray](https://github.com/raysan5) |
| 125 | [audio_raw_stream](audio/audio_raw_stream.c) | audio_raw_stream | ⭐️⭐️⭐️☆ | 1.6 | **4.2** | [Ray](https://github.com/raysan5) |
| 126 | [audio_sound_loading](audio/audio_sound_loading.c) | audio_sound_loading | ⭐️☆☆☆ | 1.1 | 3.5 | [Ray](https://github.com/raysan5) |

### category: others

Examples showing raylib misc functionality that does not fit in other categories, like standalone modules usage or examples integrating external libraries.

| ## | example  | image  | difficulty<br>level | version<br>created | last version<br>updated | original<br>developer |
|----|---|---|:---:|:---:|:---:|:---|
| 127 | [rlgl_standalone](others/rlgl_standalone.c) | rlgl_standalone | ⭐️⭐️⭐️⭐️ | 1.6 | **4.0** | [Ray](https://github.com/raysan5) |
| 128 | [rlgl_compute_shader](others/rlgl_compute_shader.c) | rlgl_compute_shader | ⭐️⭐️⭐️⭐️ | **4.0** | **4.0** | [Teddy Astie](https://github.com/tsnake41) |
| 129 | [easings_testbed](others/easings_testbed.c) | easings_testbed | ⭐️⭐️⭐️☆ | 3.0 | 3.0 | [Juan Miguel López](https://github.com/flashback-fx) |
| 130 | [raylib_opengl_interop](others/raylib_opengl_interop.c) | raylib_opengl_interop | ⭐️⭐️⭐️⭐️ | **4.0** | **4.0** | [Stephan Soller](https://github.com/arkanis) |
| 131 | [embedded_files_loading](others/embedded_files_loading.c) | embedded_files_loading | ⭐️⭐️☆☆ | 3.5 | 3.5 | [Kristian Holmgren](https://github.com/defutura) |

As always contributions are welcome, feel free to send new examples! Here is an [examples template](examples_template.c) to start with!

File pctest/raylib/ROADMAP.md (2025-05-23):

# raylib roadmap

Here is a wishlist with features and ideas to improve the library. Note that features listed here are usually long term improvements or just describe a route to follow for the library. There are also some additional places to look for raylib improvements and ideas:

 - [GitHub Issues](https://github.com/raysan5/raylib/issues) has several open issues for possible improvements or bugs to fix.
 - [raylib source code](https://github.com/raysan5/raylib/tree/master/src) has multiple *TODO* comments around code with pending things to review or improve.
 - raylib wishlists discussions are open to everyone to ask for improvements, feel free to check and comment:
    - [raylib wishlist 2021](https://github.com/raysan5/raylib/discussions/1502)
    - [raylib wishlist 2022](https://github.com/raysan5/raylib/discussions/2272)
    - [raylib 5.0 wishlist](https://github.com/raysan5/raylib/discussions/2952)

_Current version of raylib is complete and functional but there is always room for improvements._

**raylib 5.x**
 - [ ] `rcore`: Support additional platforms: iOS, Xbox Series S|X
 - [ ] `rcore_web`: Avoid GLFW dependency, functionality can be directly implemented using emscripten SDK
 - [ ] `rlgl`: Review GLSL shaders naming conventions for consistency
 - [ ] `textures`: Improve compressed textures support, loading and saving
 - [ ] `rmodels`: Improve 3d objects loading, specially animations (obj, gltf)
 - [ ] `raudio`: Implement miniaudio high-level provided features
 - [ ] `examples`: Review all examples, add more and better code explanations
 - [ ] Software renderer backend? Maybe using `Image` provided API

**raylib 4.x**
 - [x] Split core module into separate platforms?
 - [x] Redesign gestures system, improve touch inputs management
 - [x] Redesign camera module (more flexible) ([#1143](https://github.com/raysan5/raylib/issues/1143), https://github.com/raysan5/raylib/discussions/2507)
 - [x] Better documentation and improved examples, reviewed webpage with examples complexity level
 - [x] Focus on HTML5 ([raylib 5k gamejam](https://itch.io/jam/raylib-5k-gamejam)) and embedded platforms (RPI and similar SOCs)
 - [x] Additional support libraries: [raygui](https://github.com/raysan5/raygui), [rres](https://github.com/raysan5/rres)

**raylib 4.0**
 - [x] Improved consistency and coherency in raylib API
 - [x] Continuous Deployment using GitHub Actions
 - [x] rlgl improvements for standalone usage (avoid raylib coupling)
 - Basic CPU/GPU stats system (memory, draws, time...) ([#1295](https://github.com/raysan5/raylib/issues/1295)) - _DISCARDED_
 - Software rendering backend (avoiding OpenGL) ([#1370](https://github.com/raysan5/raylib/issues/1370)) - _DISCARDED_
 - Network module (UDP): `rnet` ([#753](https://github.com/raysan5/raylib/issues/753)) - _DISCARDED_ - Use [nbnet](https://github.com/nathhB/nbnet).

 **raylib 3.0**
 - [x] Custom memory allocators support
 - [x] Global variables moved to global context
 - [x] Optimize data structures for pass-by-value
 - [x] Trace log messages redesign ([#1065](https://github.com/raysan5/raylib/issues/1065))
 - [x] Continuous Integration using GitHub Actions

**raylib 2.5**
 - [x] Support Animated models
 - [x] Support glTF models file format
 - [x] Unicode support on text drawing

**raylib 2.0**
 - [x] Removed external dependencies (GLFW3 and OpenAL)
 - [x] Support TCC compiler (32bit and 64bit)

**raylib 1.8**
 - [x] Improved Materials system with PBR support
 - [x] Procedural image generation functions (spot, gradient, noise...)
 - [x] Procedural mesh generation functions (cube, sphere...)
 - [x] Custom Android APK build pipeline (default Makefile)

**raylib 1.7**
 - [x] Support configuration flags
 - [x] Improved build system for Android
 - [x] Gamepad support on HTML5

**raylib 1.6**
 - [x] Lua scripting support (raylib Lua wrapper)
 - [x] Redesigned audio module
 - [x] Support FLAC file format

**raylib 1.5**
 - [x] Support Oculus Rift CV1 and VR stereo rendering (simulator)
 - [x] Redesign Shaders/Textures system -> New Materials system
 - [x] Support lighting: Omni, Directional and Spotlights
 - [x] Redesign physics module (physac)
 - [x] Chiptunes audio modules support

**raylib 1.4**
 - [x] TTF fonts support (using stb_truetype)
 - [x] Raycast system for 3D picking (including collisions detection)
 - [x] Floyd-Steinberg dithering on 16bit image format conversion
 - [x] Basic image manipulation functions (crop, resize, draw...)
 - [x] Storage load/save data functionality
 - [x] Add Physics module (physac)
 - [x] Remove GLEW dependency -> Replaced by GLAD
 - [x] Redesign Raspberry PI inputs system
 - [x] Redesign gestures module to be multiplatform
 - [x] Module raymath as header-only and functions inline
 - [x] Add Easings module (easings.h)

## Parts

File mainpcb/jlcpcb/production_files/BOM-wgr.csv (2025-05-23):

Comment | Designator | Footprint | LCSC | Quantity
MountingHole_M3 | H2 | MountingHole_3.2mm_M3 |  | 1
6 | SW6 | KEY-SMD_2P-L6.0-W6.0-P6.00 |  | 1
PARAM | SW9 | SW-TH_EC11XXXXXXXX |  | 1
MountingHole_M3 | H4 | MountingHole_3.2mm_M3 |  | 1
1 | SW1 | KEY-SMD_2P-L6.0-W6.0-P6.00 |  | 1
2 | SW2 | KEY-SMD_2P-L6.0-W6.0-P6.00 |  | 1
3 | SW3 | KEY-SMD_2P-L6.0-W6.0-P6.00 |  | 1
VALUE | SW10 | SW-TH_EC11XXXXXXXX |  | 1
5 | SW5 | KEY-SMD_2P-L6.0-W6.0-P6.00 |  | 1
MountingHole_M3 | H3 | MountingHole_3.2mm_M3 |  | 1
4 | SW4 | KEY-SMD_2P-L6.0-W6.0-P6.00 |  | 1
MountingHole_M3 | H1 | MountingHole_3.2mm_M3 |  | 1
22K | R13 | R_0603_1608Metric |  | 1
MPR121 | J7 | SM04BSRSSTB |  | 1
100N | C17 | C_0805_2012Metric |  | 1
470 | R12 | R_0805_2012Metric |  | 1
4.7K | R20 | R_0805_2012Metric |  | 1
470 | R11 | R_0805_2012Metric |  | 1
2.2U | C18 | C_0805_2012Metric |  | 1
100N | C16 | C_0805_2012Metric |  | 1
470 | R2 | R_0805_2012Metric |  | 1
470 | R1 | R_0805_2012Metric |  | 1
4.7K | R21 | R_0805_2012Metric |  | 1
1U | C9 | C_0805_2012Metric |  | 1
2.7寸240*96 0.5MM*32P UC1638 三串背光 背面插座 | LCD1 | Hirose_FH12-32S-0.5SH_1x32-1MP_P0.50mm_Horizontal |  | 1
2.2N | C6 | C_0805_2012Metric |  | 1
22U | C19 | C_1206_3216Metric |  | 1
470 | RN1 | R_Array_Convex_4x0603 |  | 1
1U | C10 | C_0805_2012Metric |  | 1
Si2302CDS | Q1 | SOT-23 |  | 1
1U | C11 | C_0805_2012Metric |  | 1
100N | C15 | C_0805_2012Metric |  | 1
~ | PJ1 | AUDIO-IN-SMD_PJ-327A_C22355751 |  | 1
2.2N | C7 | C_0805_2012Metric |  | 1
4.7k | R23 | R_0805_2012Metric |  | 1
10K | RN2 | R_Array_Convex_4x0603 |  | 1
100N | C14 | C_0805_2012Metric |  | 1
6.8U | L1 | L_APV_APH0420 |  | 1
CH552G | J4 | SM07B-SRSS-TB |  | 1
1K | R15 | R_0805_2012Metric |  | 1
100N | C4 | C_0805_2012Metric |  | 1
22U | C20 | C_1206_3216Metric |  | 1
1U | C8 | C_0805_2012Metric |  | 1
4.7K | R18 | R_0805_2012Metric |  | 1
2.2U | C3 | C_0805_2012Metric |  | 1
SS34 | D1 | D_SMA |  | 1
1U | C12 | C_0805_2012Metric |  | 1
1U | C13 | C_0805_2012Metric |  | 1
2.2U | C2 | C_0805_2012Metric |  | 1
100N | C1 | C_0805_2012Metric |  | 1
PCM5102A | U1 | TSSOP-20_4.4x6.5mm_P0.65mm |  | 1
560K | R14 | R_0603_1608Metric |  | 1
100N | C5 | C_0805_2012Metric |  | 1
4.7K | R19 | R_0805_2012Metric |  | 1
SX1308 | U2 | SOT-23-6_L2.9-W1.6-P0.95-LS2.8-BL |  | 1
Conn_01x05 | J2 | Harwin_M20-89005xx_1x05_P2.54mm_Horizontal |  | 1
Conn_01x05 | J3 | Harwin_M20-89005xx_1x05_P2.54mm_Horizontal |  | 1
STM32H750VBT6 | IC1 | QFP50P1600X1600X160-100N |  | 1
USB_C_Receptacle_USB2.0_16P | J1 | USB_C_Receptacle_G-Switch_GT-USB-7010ASV |  | 1
100nF | C23 | C_0603_1608Metric |  | 1
100nF | C27 | C_0603_1608Metric |  | 1
octButton | J9 | SM04BSRSSTB |  | 1
ME6210A33M3G | U3 | SOT-23 |  | 1
100nF | C39 | C_0603_1608Metric |  | 1
1uF | C38 | C_0805_2012Metric |  | 1
10uF | C37 | C_0805_2012Metric |  | 1
10uF | C36 | C_0805_2012Metric |  | 1
SMD3225-4 | X1 | Crystal_SMD_3225-4Pin_3.2x2.5mm |  | 1
22pF | C34 | C_0603_1608Metric |  | 1
22pF | C33 | C_0603_1608Metric |  | 1
10k | R22 | R_0603_1608Metric_Pad0.98x0.95mm |  | 1
100nF | C30 | C_0603_1608Metric |  | 1
5.1k | R24 | R_0603_1608Metric_Pad0.98x0.95mm |  | 1
10uF | C31 | C_0603_1608Metric |  | 1
100nF | C24 | C_0603_1608Metric |  | 1
W25Q16JVSS | U5 | SOIC-8_5.3x5.3mm_P1.27mm |  | 1
100nF | C29 | C_0603_1608Metric |  | 1
100nF | C28 | C_0603_1608Metric |  | 1
100nF | C26 | C_0603_1608Metric |  | 1
SW_Push | SW7 | SW-SMD_4P-L4.5-W4.5-P3.00-LS7.0_TS-1009S-03826 |  | 1
100nF | C25 | C_0603_1608Metric |  | 1
100nF | C32 | C_0603_1608Metric |  | 1
SW_Push | SW8 | SW-SMD_4P-L4.5-W4.5-P3.00-LS7.0_TS-1009S-03826 |  | 1
100nF | C35 | C_0603_1608Metric |  | 1
100nF | C22 | C_0603_1608Metric |  | 1
MPR121-2 | J8 | SM04BSRSSTB |  | 1
5.1k | R25 | R_0603_1608Metric_Pad0.98x0.95mm |  | 1
100nF | C21 | C_0603_1608Metric |  | 1
600R | L2 | L_0603_1608Metric |  | 1
500mA | F1 | Fuse_0603_1608Metric |  | 1
470 | R3 | R_0805_2012Metric |  | 1
100N | C40 | C_0603_1608Metric |  | 1
100N | C41 | C_0603_1608Metric |  | 1
TXS0108EPW | U4 | TSSOP-20_4.4x6.5mm_P0.65mm |  | 1
4.7K | R29 | R_0805_2012Metric |  | 1
4.7K | R28 | R_0805_2012Metric |  | 1
4.7k | R27 | R_0805_2012Metric |  | 1
4.7K | R26 | R_0805_2012Metric |  | 1
10k | R16 | R_0603_1608Metric |  | 1
Si2302CDS | Q2 | SOT-23 |  | 1
Debug | LED2 | LED_0805_2012Metric |  | 1
Power | LED1 | LED_0805_2012Metric |  | 1
CH552G-2 | J5 | SM07B-SRSS-TB |  | 1

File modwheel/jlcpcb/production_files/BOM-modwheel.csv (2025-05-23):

Comment | Designator | Footprint | LCSC | Quantity
Conn_01x04 | J5 | SM04BSRSSTB |  | 1
MPR121QR2 | U1 | UQFN-20_3x3mm_P0.4mm |  | 1
MountingHole_M3 | H1 | MountingHole_3.2mm_M3 |  | 1
OCT+ | SW1 | KEY-SMD_2P-L6.0-W6.0-P6.00 |  | 1
MountingHole_M3 | H3 | MountingHole_3.2mm_M3 |  | 1
MountingHole_M3 | H4 | MountingHole_3.2mm_M3 |  | 1
PitchBend | J2 | TouchSlider-6_50x10mm |  | 1
ModWheel | J1 | TouchSlider-6_50x10mm |  | 1
OCT- | SW2 | KEY-SMD_2P-L6.0-W6.0-P6.00 |  | 1
MountingHole_M3 | H2 | MountingHole_3.2mm_M3 |  | 1
R_Small | R2 | R_0603_1608Metric |  | 1
Conn_01x04 | J3 | SM04BSRSSTB |  | 1
R_Small | R1 | R_0603_1608Metric |  | 1
100nF | C1 | C_0603_1608Metric |  | 1
Conn_01x04 | J4 | SM04BSRSSTB |  | 1
100nF | C2 | C_0603_1608Metric |  | 1
10k | R4 | R_0603_1608Metric |  | 1
10k | R3 | R_0603_1608Metric |  | 1
10k | R6 | R_0603_1608Metric |  | 1
10k | R5 | R_0603_1608Metric |  | 1

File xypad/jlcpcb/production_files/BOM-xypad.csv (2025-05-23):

Comment | Designator | Footprint | LCSC | Quantity
~ | U2 | touchpad6x6 |  | 1
MountingHole_M3 | H4 | MountingHole_3.2mm_M3 |  | 1
MountingHole_M3 | H3 | MountingHole_3.2mm_M3 |  | 1
MountingHole_M3 | H2 | MountingHole_3.2mm_M3 |  | 1
MountingHole_M3 | H1 | MountingHole_3.2mm_M3 |  | 1
75K | R3 | R_0805_2012Metric |  | 1
SM04B-SRSS-TB | J2 | SM04BSRSSTB |  | 1
MPR121QR2 | U1 | UQFN-20_3x3mm_P0.4mm |  | 1
100N | C2 | C_0805_2012Metric |  | 1
100N | C1 | C_0805_2012Metric |  | 1

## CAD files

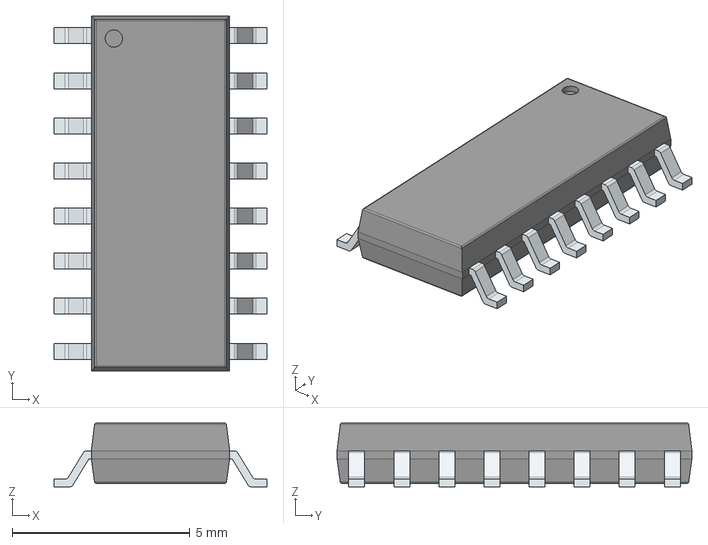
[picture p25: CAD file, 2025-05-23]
keyboard/3D/CH552G.stp
6.00 x 10.0 x 1.80 mm
PinsArrayLR

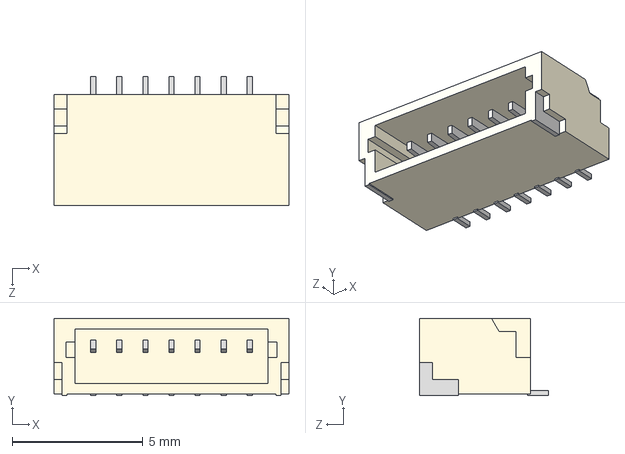
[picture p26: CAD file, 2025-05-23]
mainpcb/3d/SM07B-SRSS-TB_LF__SN_.stp
9.00 x 2.96 x 4.95 mm

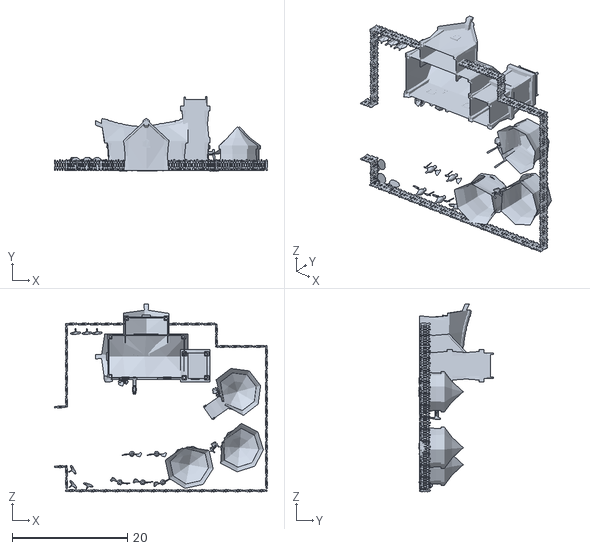
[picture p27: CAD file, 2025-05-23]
pctest/raylib/examples/shaders/resources/models/barracks.obj
36.9 x 12.9 x 32.5

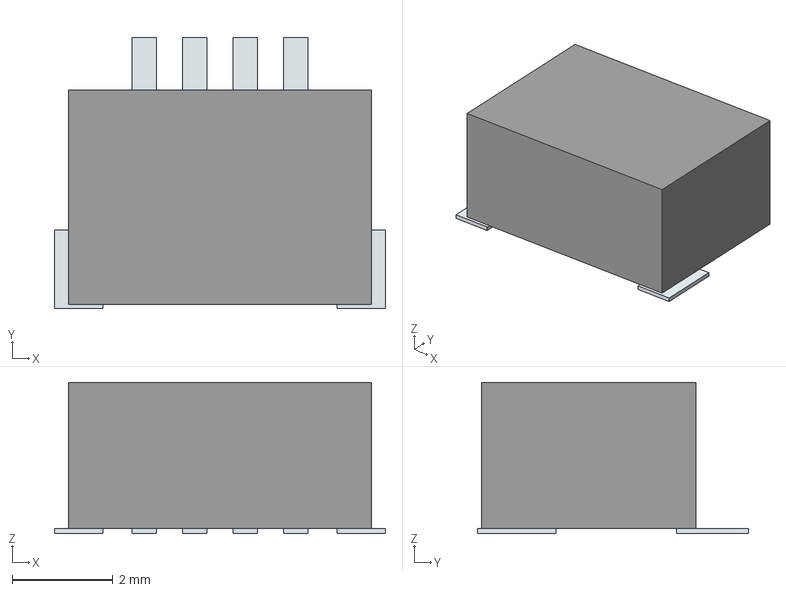
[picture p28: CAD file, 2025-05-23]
xypad/3d/SM04B-SRSS-TB.stp
6.56 x 5.37 x 3.00 mm
Pins

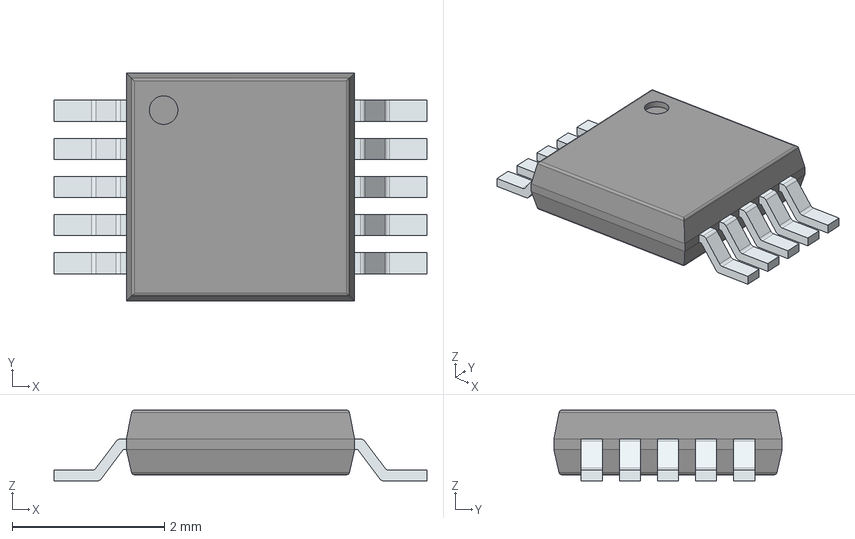
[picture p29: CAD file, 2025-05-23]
keyboard/3D/IC-RC1000MSOP10.stp
4.90 x 3.00 x 0.93 mm
PinsArrayLR

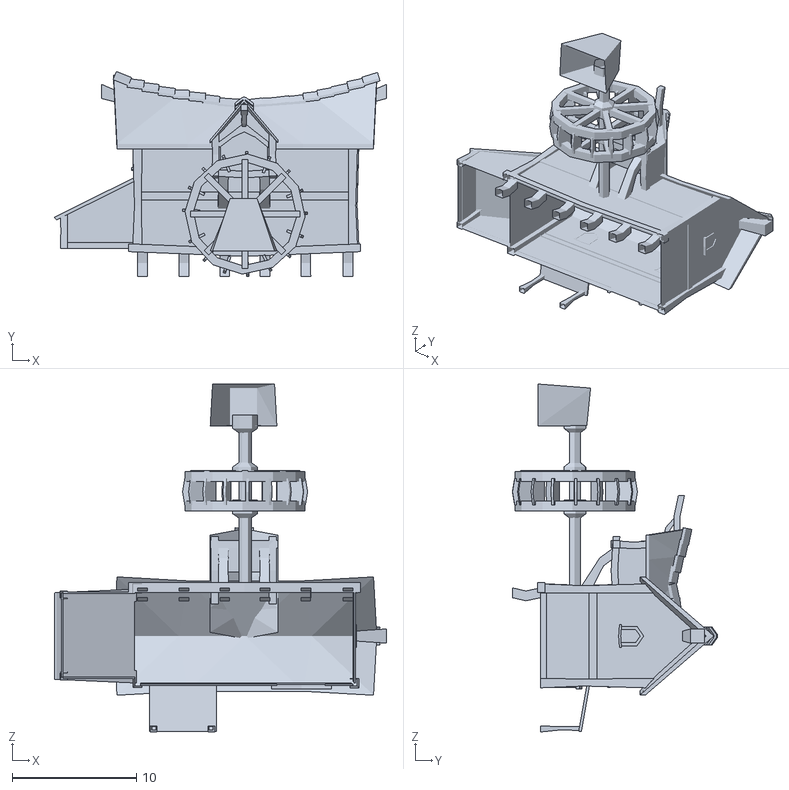
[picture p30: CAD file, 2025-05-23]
pctest/raylib/examples/shaders/resources/models/watermill.obj
26.7 x 16.5 x 28.0

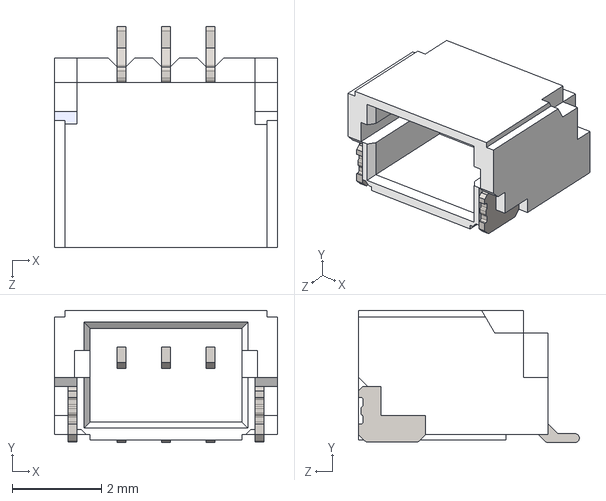
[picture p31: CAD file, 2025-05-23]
keyboard/3D/SM03B-SRSS-TB_LF__SN_.stp
5.00 x 2.96 x 4.95 mm

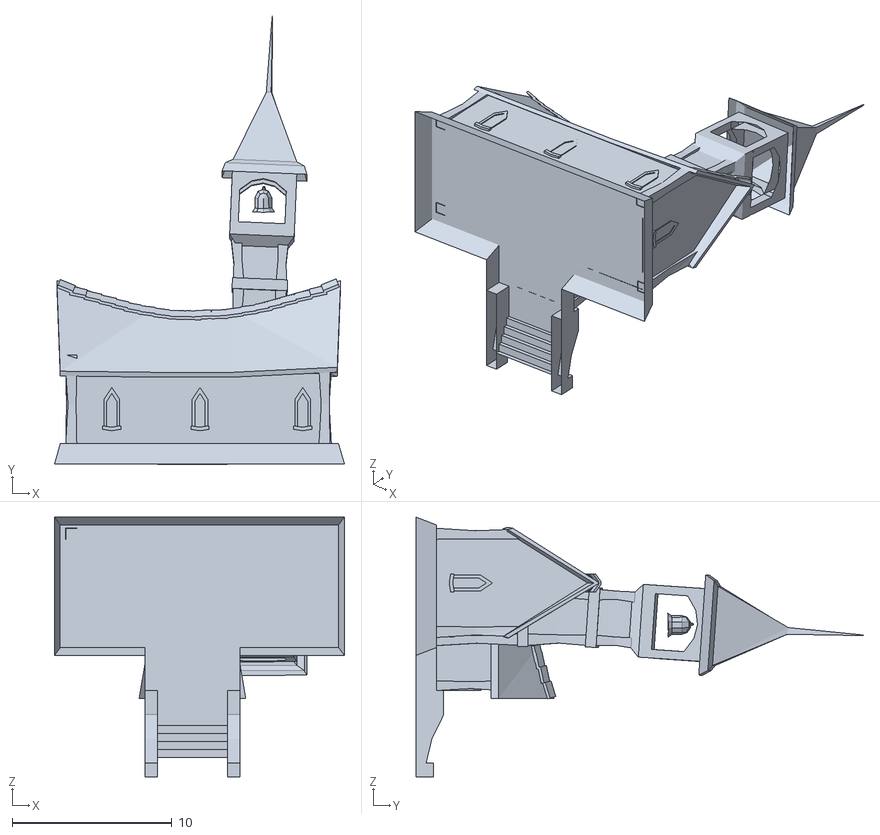
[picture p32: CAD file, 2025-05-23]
pctest/raylib/examples/shaders/resources/models/church.obj
18.1 x 28.0 x 16.3

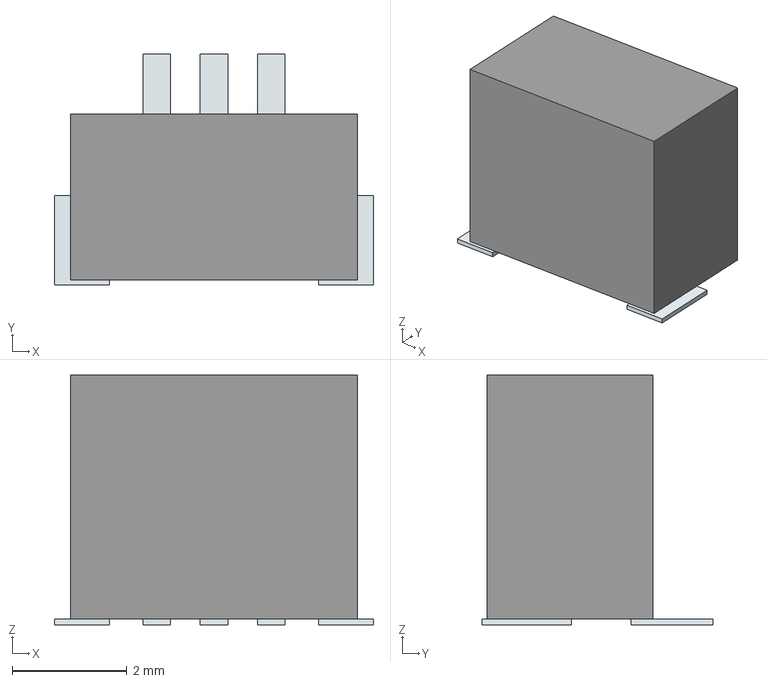
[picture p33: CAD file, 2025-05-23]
keyboard/3D/BM03B-SRSS-TB.stp
5.56 x 4.02 x 4.35 mm
Pins

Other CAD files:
pctest/raylib/examples/models/resources/models/gltf/robot.blend
pctest/raylib/examples/models/resources/models/iqm/guy.blend

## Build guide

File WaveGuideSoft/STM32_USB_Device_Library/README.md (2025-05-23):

# Middleware USB Device MCU Component



## Overview

**STM32Cube** is an STMicroelectronics original initiative to ease developers' life by reducing efforts, time and cost.

**STM32Cube** covers the overall STM32 products portfolio. It includes a comprehensive embedded software platform delivered for each STM32 series.
   * The CMSIS modules (core and device) corresponding to the ARM(tm) core implemented in this STM32 product.
   * The STM32 HAL-LL drivers, an abstraction layer offering a set of APIs ensuring maximized portability across the STM32 portfolio.
   * The BSP drivers of each evaluation, demonstration or nucleo board provided for this STM32 series.
   * A consistent set of middleware libraries such as RTOS, USB, FatFS, graphics, touch sensing library...
   * A full set of software projects (basic examples, applications, and demonstrations) for each board provided for this STM32 series.

Two models of publication are proposed for the STM32Cube embedded software:
   * The monolithic **MCU Package**: all STM32Cube software modules of one STM32 series are present (Drivers, Middleware, Projects, Utilities) in the repository (usual name **STM32Cubexx**, xx corresponding to the STM32 series).
   * The **MCU component**: each STM32Cube software module being part of the STM32Cube MCU Package, is delivered as an individual repository, allowing the user to select and get only the required software functions.

## Description

This **stm32_mw_usb_device** MCU component repository is one element **common to all** STM32Cube MCU embedded software packages, providing the **USB Device MCU Middleware** part.

It represents ST offer to ensure the support of USB Devices on STM32 MCUs.
It includes two main modules:
 * **Core** module for the USB device standard peripheral control APIs. It includes the files ensuring USB 2.0 standard code implementation for an USB device.
These files’ APIs will be called within every USB device application regardless of the desired functionality.
 * **Class** module for the commonly supported classes APIs. it includes the files including different USB device classes. All STM32 USB classes are implemented according to the USB 2.0 and every class’s specifications. These files’ APIs will be called within USB device applications according to the desired functionality.

## Release note

Details about the content of this release are available in the release note [here](https://htmlpreview.github.io/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).

## Troubleshooting

Please refer to the [CONTRIBUTING.md](CONTRIBUTING.md) guide.

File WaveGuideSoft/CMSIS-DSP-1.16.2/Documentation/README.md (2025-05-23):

# CMSIS-DSP Documentation

CMSIS-DSP Documentation in HTML format is published online at [https://arm-software.github.io/CMSIS-DSP](https://arm-software.github.io/CMSIS-DSP).

The version drop-down menu there allows to switch between the documentation provided with offical releases and the latest draft documentation for the main branch.

The documentation source is maintained in `Documentation/Doxygen/` folder as a mixture of markdown and doxygen formats. Component source files, templates and examples may also contribute information that gets integrated into the final documentation.

Generating the HTML-formatted documentation from the source is done with `gen_doc.sh` script:

```sh
CMSIS-DSP $ ./Documentation/Doxygen/gen_doc.sh
```

The script expects specific version of [doxygen](https://www.doxygen.nl/) to be installed locally. After successful execution the resulting documentation package is then available in `./Documentation/html/`.

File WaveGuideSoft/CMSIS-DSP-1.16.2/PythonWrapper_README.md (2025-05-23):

# README

This is a Python wrapper for the Arm open source [CMSIS-DSP](https://github.com/ARM-software/CMSIS-DSP) and it is compatible with `NumPy`.

The CMSIS-DSP is available on our [GitHub](https://github.com/ARM-software/CMSIS-DSP) or as a [CMSIS Pack](https://github.com/ARM-software/CMSIS-DSP/releases).

The idea is to follow as closely as possible the C [CMSIS-DSP](https://github.com/ARM-software/CMSIS-DSP) API to ease the migration to the final implementation on a board.

The signal processing chain can thus be tested and developed in a Python environment and then easily converted to a C implementation running on a Cortex-M or Cortex-A board.

A tutorial is also available but with less details than this README:
https://developer.arm.com/documentation/102463/latest/

An history of the changes to this wrapper is available at the end of the README.

# How to build and install

## Tested configurations

The building of this package has been tested on Windows with the Python install from python.org and Microsoft Visual Studio 2022 and on Ubuntu 22.04.

It has also been tested with `cygwin`. In that case, `python-devel` must be installed too. On Mac, it was tested with standard XCode installation.

To run the examples, `scipy` and `matplotlib` must also be installed.

Other configurations should work but the `setup.py` file would have to be improved. 

Python 3 must be used.

## Installing and Building

### Installing

It is advised to do it in a Python virtual environment. Then, in the virtual environment you can just do:

    pip install cmsisdsp

You must have a recent `pip` (to automatically install the dependencies like `NumPy`) and you should have a compiler which can be found by Python when building the package.

DSP examples are available in the [CMSIS-DSP PythonWrapper examples](https://github.com/ARM-software/CMSIS-DSP/tree/main/PythonWrapper/examples) folder.

You can also install and run it from [Google colab](https://colab.research.google.com/):

This [link](https://colab.research.google.com/github/ARM-software/CMSIS-DSP/blob/main/PythonWrapper/examples/cmsisdsp_tests.ipynb) will open a Jupyter notebook in [Google colab](https://colab.research.google.com/) for testing. This notebook is from the [examples](https://github.com/ARM-software/CMSIS-DSP/tree/main/PythonWrapper/examples) in the CMSIS-DSP GitHub repository.

### Building

It it is not working (because it is not possible for us to test all configurations), you can then try to build and install the wrapper manually.

It is advised to do this it into a virtualenv

Since the [CMSIS-DSP](https://github.com/ARM-software/CMSIS-DSP) wrapper is using `NumPy`, you must first install it in the virtual environment. 

    > pip install numpy

Once `NumPy` is installed, you can build the [CMSIS-DSP](https://github.com/ARM-software/CMSIS-DSP) python wrapper. Go to folder `CMSIS/DSP`.

Now, you can install the cmsisdsp package in editable mode:

    > pip install -e .

Before using this command, you need to rebuild the CMSIS-DSP library which is no more built by the `setup.py` script.

There is a `CMakeLists.txt` in the `PythonWrapper` folder for this. The `build` folders in `PythonWrapper` are giving some examples of the options to use with the `cmake` command to generate the `Makefile` and build the library.

This library is then used by the `setup.py` script to build the Python extension.

## Running the examples

Install some packages to be able to run the examples

    > pip install numpy
    > pip install scipy
    > pip install matplotlib

Depending on the example, you may have to install more packages.

The examples are in the  [CMSIS-DSP PythonWrapper examples](https://github.com/ARM-software/CMSIS-DSP/tree/main/PythonWrapper/examples) folder.

You can test the scripts `testdsp.py` and `example.py` and try to run them from this virtual environment. `example.py` is requiring a data file to be downloaded from the web. See below in this document for the link.

Note that due to the great number of possible configurations (OS, Compiler, Python), we can't give any support if you have problems compiling the `PythonWrapper` on your specific configuration. But, generally people manage to do it and solve all the problems.

# Usage

The idea is to follow as closely as possible the [CMSIS-DSP](https://github.com/ARM-software/CMSIS-DSP) API to ease the migration to the final implementation on a board.

First you need to import the module

    > import cmsisdsp as dsp

If you use numpy:

    > import numpy as np

If you use scipy signal processing functions:

    > from scipy import signal

## Functions with no instance arguments

You can use a [CMSIS-DSP](https://github.com/ARM-software/CMSIS-DSP) function with numpy arrays:

    > r = dsp.arm_add_f32(np.array([1.,2,3]),np.array([4.,5,7]))

The function can also be called more simply with

    > r = dsp.arm_add_f32([1.,2,3],[4.,5,7])

The result of a [CMSIS-DSP](https://github.com/ARM-software/CMSIS-DSP) function will always be a numpy array whatever the arguments were (numpy array or list).

## Functions with instance arguments 

When the [CMSIS-DSP](https://github.com/ARM-software/CMSIS-DSP) function is requiring an instance data structure, it is just a bit more complex to use it:

First you need to create this instance:

    > firf32 = dsp.arm_fir_instance_f32()

Then, you need to call an init function:

    > dsp.arm_fir_init_f32(firf32,3,[1.,2,3],[0,0,0,0,0,0,0])

The third argument in this function is the state. Since all arguments (except the instance ones) are read-only in this Python API, this state will never be changed ! It is just used to communicate the length of the state array which must be allocated by the init function. This argument is required because it is present in the [CMSIS-DSP](https://github.com/ARM-software/CMSIS-DSP) API and in the final C implementation you'll need to allocate a state array with the right dimension.

Since the goal is to be as close as possible to the C API, the API is forcing the use of this argument.

The only change compared to the C API is that the size variables (like blockSize for filter) are computed automatically from the other arguments. This choice was made to make it a bit easier the use of numpy array with the API.

Now, you can check that the instance was initialized correctly.

    > print(firf32.numTaps())

Then, you can filter with CMSIS-DSP:

    > print(dsp.arm_fir_f32(firf32,[1,2,3,4,5]))

The size of this signal should be `blockSize`. `blockSize` was inferred from the size of the state array : `numTaps + blockSize - 1` according to [CMSIS-DSP.](https://github.com/ARM-software/CMSIS-DSP) So here the signal must have 5 samples.

If you want to filter more than 5 samples, then you can just call the function again. The state variable inside firf32 will ensure that it works like in the [CMSIS-DSP](https://github.com/ARM-software/CMSIS-DSP) C code. 

    > print(dsp.arm_fir_f32(firf32,[6,7,8,9,10]))

If you want to compare with scipy it is easy but warning : coefficients for the filter are in opposite order in scipy :

    > filtered_x = signal.lfilter([3,2,1.], 1.0, [1,2,3,4,5,6,7,8,9,10])
    > print(filtered_x)

The principles are the same for all other APIs.

## FFT 

Here is an example for using FFT from the Python interface:

Let's define a signal you will use for the FFT.

    > nb = 16
    > signal = np.cos(2 * np.pi * np.arange(nb) / nb)

The [CMSIS-DSP](https://github.com/ARM-software/CMSIS-DSP) cfft is requiring complex signals with a specific layout in memory.

To remain as close as possible to the C API, we are not using complex numbers in the wrapper. So a complex signal must be converted into a real one. The function imToReal1D is defined in testdsp.py 

    > signalR = imToReal1D(signal)

Then, you create the FFT instance with:

    > cfftf32=dsp.arm_cfft_instance_f32()

You initialize the instance with the init function provided by the wrapper:

    > status=dsp.arm_cfft_init_f32(cfftf32, nb)
    > print(status)

You compute the FFT of the signal with:

    > resultR = dsp.arm_cfft_f32(cfftf32,signalR,0,1)

You convert back to a complex format to compare with scipy:

    > resultI = realToIm1D(resultR)
    > print(resultI)

## Matrix 

For matrix, the instance variables are masked by the Python API. We decided that for matrix only there was no use for having the [CMSIS-DSP](https://github.com/ARM-software/CMSIS-DSP) instance visibles since they contain the same information as the numpy array (samples and dimension).

So to use a [CMSIS-DSP](https://github.com/ARM-software/CMSIS-DSP) matrix function, it is very simple:

    > a=np.array([[1.,2,3,4],[5,6,7,8],[9,10,11,12]])
    > b=np.array([[1.,2,3],[5.1,6,7],[9.1,10,11],[5,8,4]])

`NumPy` result as reference:

    > print(np.dot(a , b))

[CMSIS-DSP](https://github.com/ARM-software/CMSIS-DSP) result:

    > v=dsp.arm_mat_mult_f32(a,b)
    > print(v)

In a real C code, a pointer to a data structure for the result `v` would have to be passed as argument of the function.

## example.py

This example depends on a data file which can be downloaded here:

https://archive.physionet.org/pn3/ecgiddb/Person_87/rec_2.dat

This signal was created for a master thesis:

Lugovaya T.S. Biometric human identification based on electrocardiogram. [Master's thesis] Faculty of Computing Technologies and Informatics, Electrotechnical University "LETI", Saint-Petersburg, Russian Federation; June 2005. 

and it is part of the PhysioNet database

Goldberger AL, Amaral LAN, Glass L, Hausdorff JM, Ivanov PCh, Mark RG, Mietus JE, Moody GB, Peng C-K, Stanley HE. PhysioBank, PhysioToolkit, and PhysioNet: Components of a New Research Resource for Complex Physiologic Signals. Circulation 101(23):e215-e220 [Circulation Electronic Pages; http://circ.ahajournals.org/cgi/content/full/101/23/e215]; 2000 (June 13). 

## Submodules

The Python wrapper is containing three submodules : `fixedpoint` , `mfcc` and `datatype`

`fixedpoint` is proving some tools to help generating the fixedpoint values expected
by [CMSIS-DSP](https://github.com/ARM-software/CMSIS-DSP).

`mfcc` is generating some tools to generate the MEL filters, DCT and window coefficients
expected by the [CMSIS-DSP](https://github.com/ARM-software/CMSIS-DSP) MFCC implementation.

MEL filters are represented as 3 arrays to encode a sparse array.

`datatype` is an API on top of `fixedpoint` to provide more reuse when converting between data formats.

# Change history

## Version 1.9.9:
* Supports Python 3.12
* Works with Numpy 2.0
* Corrections on Cholesky

## Version 1.9.8:
* Compute graph API has been removed
* Dependency on numpy 1.22 has been lifted, tested through numpy 1.26
* Inconsistencies in distance and window modules have been fixed.

## Version 1.9.7:

* Upgrade for compatibility with google colab 
* Change to compute graph API for structured datatype
* Corrected distance issues when using wrapper on aarch64

## Version 1.9.6:

* Corrections to the RFFTs APIs
* More flexibility in the compute graph to specify the additional arguments of the scheduler and nodes
* Possibility to set the FIFO scaling factor at FIFO level (in asynchronous mode)

## Version 1.9.5:

Same as 1.9.4 but will work in Google Colab.

## Version 1.9.4:

* Dynamic Time Warping API
* Window functions for FFT
* New asynchronous mode for the compute graph
(see [compute graph documentation](https://github.com/ARM-software/CMSIS-DSP/tree/main/ComputeGraph) for more details.

## Version 1.9.3:

* Corrected real FFTs in the wrapper
* Corrected arm_fir_decimate and arm_fir_interpolate
* Possibility to customize the FIFO class on a connection for the Python wrapper

## Version 1.9.2:

* New customization options for the compute graph:
  * CAPI
  * CMSISDSP
  * postCustomCName

## Version 1.9.1:

* Small fix to the compute graph generator. The `#ifdef` at beginning of the custom header should be different for different scheduler names
* Improve `addLiteralArg` and `addVariableArg` in compute graph to use variable number of arguments

## Version 1.9.0:

* New scheduling mode, in the compute graph generator, giving priority to sinks in the scheduling. The idea is to try to decrease the latency between sinks and sources.
* More customization options (Macros to be defined) in the C++ code generated by the compute graph generator

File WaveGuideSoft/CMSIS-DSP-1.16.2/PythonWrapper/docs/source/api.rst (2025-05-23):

API
===

.. highlight:: python

The idea is to follow as closely as possible the CMSIS-DSP API to ease the migration to the final implementation on a board.

First you need to import the module::

    import cmsisdsp as dsp

If you use numpy::

    import numpy as np

If you use scipy signal processing functions::

    from scipy import signal

Standard APIs
*************

.. code-block:: C
    
     void arm_add_f32(
            const float32_t * pSrcA,
            const float32_t * pSrcB,
            float32_t * pDst,
            uint32_t blockSize);

.. py:function:: dsp.arm_add_f32(pSrcA,pSrcB)

   Return a list of random ingredients as strings.

   :param pSrcA: array.
   :type pSrcA: NumPy array
   :param pSrcB: array.
   :type pSrcB: NumPy array
   :return: array.
   :rtype: NumPy array

Example::

      import cmsisdsp as dsp

      r = dsp.arm_add_f32([1.,2,3],[4.,5,7])

You can use a CMSIS-DSP function with numpy arrays: ::

   r = dsp.arm_add_f32(np.array([1.,2,3]),np.array([4.,5,7]))

The result of a CMSIS-DSP function will always be a numpy array whatever the arguments were (numpy array or list).

Functions with instance arguments 
*********************************

When the CMSIS-DSP function is requiring an instance data structure, it is just a bit more complex to use it:

First you need to create this instance::

      import cmsisdsp as dsp

      firf32 = dsp.arm_fir_instance_f32()

.. code-block:: C

   void arm_fir_init_f32(
               arm_fir_instance_f32 * S,
               uint16_t numTaps,
         const float32_t * pCoeffs,
               float32_t * pState,
               uint32_t blockSize);

.. py:function:: dsp.arm_fir_init_f32(S,numTaps,pCoeffs,pState)

   Return a list of random ingredients as strings.

   :param S: f32 instance.
   :type S: int
   :param pCoeffs: array.
   :type pCoeffs: NumPy array
   :param pState: array.
   :type pState: NumPy array
   :return: array.
   :rtype: NumPy array

Example of use::

   dsp.arm_fir_init_f32(firf32,3,[1.,2,3],[0,0,0,0,0,0,0])

The third argument in this function is the state. Since all arguments (except the instance ones) are read-only in this Python API, this state will never be changed ! It is just used to communicate the length of the state array which must be allocated by the init function. This argument is required because it is present in the CMSIS-DSP API and in the final C implementation you'll need to allocate a state array with the right dimension.

Since the goal is to be as close as possible to the C API, the API is forcing the use of this argument.

The only change compared to the C API is that the size variables (like blockSize for filter) are computed automatically from the other arguments. This choice was made to make it a bit easier the use of numpy array with the API.

Now, you can check that the instance was initialized correctly::

.. code-block:: python

   print(firf32.numTaps())

The filter can then be called:

.. code-block:: C

   void arm_fir_f32(
               const arm_fir_instance_f32 * S,
               const float32_t * pSrc,
                     float32_t * pDst,
                     uint32_t blockSize);

.. py:function:: dsp.arm_fir_f32(S,pSrc)

   Return a list of random ingredients as strings.

   :param S: f32 instance.
   :type S: int
   :param pSrc: array of input samples.
   :type pSrc: NumPy array
   :return: array.
   :rtype: NumPy array

Then, you can filter with CMSIS-DSP::

   print(dsp.arm_fir_f32(firf32,[1,2,3,4,5]))

The size of this signal should be blockSize. blockSize was inferred from the size of the state array : numTaps + blockSize - 1 according to CMSIS-DSP. So here the signal must have 5 samples.

If you want to filter more than 5 samples, then you can just call the function again. The state variable inside firf32 will ensure that it works like in the CMSIS-DSP C code::

    print(dsp.arm_fir_f32(firf32,[6,7,8,9,10]))

If you want to compare with scipy it is easy but warning : coefficients for the filter are in opposite order in scipy ::

    filtered_x = signal.lfilter([3,2,1.], 1.0, [1,2,3,4,5,6,7,8,9,10])
    print(filtered_x)

FFT
***

The CMSIS-DSP cfft is requiring complex signals with a specific layout in memory.

To remain as close as possible to the C API, we are not using complex numbers in the wrapper. So a complex signal must be converted into a real one. A function like the bewlo one can be used::

   def imToReal1D(a):
       ar=np.zeros(np.array(a.shape) * 2)
       ar[0::2]=a.real
       ar[1::2]=a.imag
       return(ar)

In the same way, the return array from the CMSIS-DSP FFT will not be containing complex Python scalars. It must be converted back with a function like::

   def realToIm1D(ar):
       return(ar[0::2] + 1j * ar[1::2])

Then, the utilisation of the API si very similar to what was done for the FIR example:

Then, you create the FFT instance with::

    cfftf32=dsp.arm_cfft_instance_f32()

You initialize the instance with the init function ::

    status=dsp.arm_cfft_init_f32(cfftf32, nb)
    print(status)

You convert the complex signal to the format expected by the wrapper::

    signalR = imToReal1D(signal)

You compute the FFT of the signal with::

    resultR = dsp.arm_cfft_f32(cfftf32,signalR,0,1)

You convert back to a complex format to compare with scipy::

    resultI = realToIm1D(resultR)
    print(resultI)

Matrix
******

For matrix, the instance variables are masked by the Python API. We decided that for matrix only there was no use for having the CMSIS-DSP instance visibles since they contain the same information as the numpy array (samples and dimension).

So to use a CMSIS-DSP matrix function, it is very simple::

    a=np.array([[1.,2,3,4],[5,6,7,8],[9,10,11,12]])
    b=np.array([[1.,2,3],[5.1,6,7],[9.1,10,11],[5,8,4]])

Numpy result as reference::

    print(np.dot(a , b))

CMSIS-DSP result::

    v=dsp.arm_mat_mult_f32(a,b)
    print(v)

In a real C code, a pointer to a data structure for the result v would have to be passed as argument of the function.

The C API is:

.. code-block:: C

   arm_status arm_mat_mult_f32(
                const arm_matrix_instance_f32 * pSrcA,
                const arm_matrix_instance_f32 * pSrcB,
                      arm_matrix_instance_f32 * pDst);

The Python API is:

.. py:function:: dsp.arm_mat_mult_f32(pSrcA,pSrcB)

   Return the matrix product pSrcA * pSrcB

   :param pSrcA: array of input samples.
   :type pSrcA: NumPy array
   :param pSrcB: array of input samples.
   :type pSrcB: NumPy array
   :return: the matrix product.
   :rtype: NumPy array

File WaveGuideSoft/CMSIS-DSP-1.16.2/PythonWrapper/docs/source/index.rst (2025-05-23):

.. cmsisdsp documentation master file, created by
   sphinx-quickstart on Mon Feb 14 11:09:26 2022.
   You can adapt this file completely to your liking, but it should at least
   contain the root `toctree` directive.

Welcome to CMSIS-DSP PythonWrapper's documentation!
===================================================

**cmsisdsp** is a Python wrapper for the Arm `CMSIS-DSP API <https://github.com/ARM-software/CMSIS_5/tree/develop/CMSIS/DSP>`_. With **cmsisdsp** you can run the `CMSIS-DSP API <https://github.com/ARM-software/CMSIS_5/tree/develop/CMSIS/DSP>`_ functions in Python. The functions are compatible with NumPy.

The APIs of the functions in package **cmsisdsp** are as close as possible to the C versions to make it easier to migrate the Python implementation of your code to an equivalent C one running on the embedded target.

In addition to the Python interface to the C functions, there are additional submodules.

* :doc:`fixedpoint.py <fixedpoint>` is providing some tools to help generating the fixedpoint values expected
  by CMSIS-DSP.
* :doc:`mfcc.py <mfcc>` is generating some tools to generate the MEL filters, DCT and window coefficients
  expected by the CMSIS-DSP MFCC implementation.

Table of contents
*****************
.. toctree::

   Python API to C functions <api>
   datatype.py <datatype>
   fixedpoint.py <fixedpoint>
   mfcc.py <mfcc>

.. note::

   This project is under development.

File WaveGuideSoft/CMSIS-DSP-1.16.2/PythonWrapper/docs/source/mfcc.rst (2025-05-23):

MFCC
====

.. highlight:: python

.. autofunction:: cmsisdsp.mfcc.frequencyToMelSpace
.. autofunction:: cmsisdsp.mfcc.melSpaceToFrequency

MEL filters are represented as 3 arrays to encode a sparse matrix.

.. autofunction:: cmsisdsp.mfcc.melFilterMatrix

The API is returning a tuple::
  
  (filterLength,filterPos,PackedCoefficients)

The first argument is the list of MEL filter lengths.

The second argument is the position of the first coefficient of the filter in the list of coefficients,

The last argument is the concatenated list of all filter coefficients.

.. autofunction:: cmsisdsp.mfcc.dctMatrix

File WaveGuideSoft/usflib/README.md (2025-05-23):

# μSF - Micro String Format






μSF is a lean C++ string format library (mainly) for embedded platforms.
Its main purpose is to be a small, safe and fast alternative to (s)(n)printf functions adding some additional features.
The library is in its very early stages of development and its interface can (inevitably will) change at any time based on my own usage experience and any feedback / comments I get.

## Motivation
Damn... yet another formatting library???
Well, basically I have no sympathy for the (s)(n)printf functions, even less for the cumbersome IOStream's interface.
I really love the [**\{fmt\}**](http://fmtlib.net) library but it has an hefty price tag when working with targets with only a few kB of flash and RAM available.
This happens mostly because {fmt} has a lot of features (rarely needed in an embedded target) and also because it falls back to printf in some cases (hopefully this is still true in the latest version).

So, based on my love for the {fmt}'s format string syntax (itself similar to the one of [str.format](https://docs.python.org/3.8/library/string.html) in Python), I decided to roll my own version with a nice balance in mind between code size, execution speed and available features that made sense to my main target platforms, small embedded micro-controllers, mostly ARM Cortex-M0/3/4.

I also did it for the challenge of making it and it turned out to be more demanding than I has expecting at first...

## Features
- Safe alternative to (s)(n)printf and IOStream functions.
- Doesn't allocate any dynamic memory.
- Ease of use: single header file library [usf.hpp](https://raw.githubusercontent.com/hparracho/usflib/master/include/usf/usf.hpp) without any external dependencies.
- Small code size: both in terms of source code (around 2500 loc) and produced binary size.
- Reliable: it has an extensive set of [unit tests](https://github.com/hparracho/usflib/tree/master/unit_tests) (*work in progress*).
- Support for positional arguments.
- Support for user-defined custom types.
- Portable and consistent across platforms and compilers.
- Clean warning-free codebase even with [aggressive](https://github.com/hparracho/usflib/blob/master/unit_tests/CMakeLists.txt#L10) warning levels.
- Support for  C\+\+11/14/17 standards:
  - GCC 4.8.1 or greater
  - Clang 3.4.0 or greater
  - Should work with MSVC\+\+ 14.0 or greater (*untested yet*)

#### Roadmap - upcoming features
- Complete unit tests.
- IAR and Arm Compiler 5/6 support.
- Dynamic width and precision support.
- Add a std::string replacement with inplace storage.
- Add more functions to usf::StringSpan and usf::StringView classes. 
- Besides formatting, also printing capability with custom output handler, e.g.: Console, UARTs, LCDs, etc...
- Wide character strings support (the foundations are done but it was never used or tested).
- Better floating point conversion routines (the current ones suck!). Looking at the possibility of adapting [ryu](https://github.com/ulfjack/ryu)'s algorithm.

## Benchmarks
(*wip*)

## Usage
To get started with **usflib** all you need to do is download the [**latest version**](https://raw.githubusercontent.com/hparracho/usflib/master/include/usf/usf.hpp) which is just a single header file and add it to your source files (or add this repository as a git submodule).

Assuming you can use the single header file directly: ```#include "usf.hpp"``` - place it either in the same folder of your source files or add its location to the include paths of your build system. 

#### A minimal example
```c++
#include "usf.hpp"
/*...*/
char str[64]{};
usf::format_to(str, 64, "Hello, {}!", "world");      // str == "Hello, world!"
usf::format_to(str, 64, "dec:{0} hex:{0:x}", 16);    // str == "dec:16 hex:10"
usf::format_to(str, 64, "{0}{1}{0}", "abra", "cad"); // str == "abracadabra"
```

## API Reference
All functions and types provided by the μSF library reside in namespace ```usf``` and macros have prefix ```USF_```.
The library API provides a few simple format functions and a minimal string view / string span like classes that offer an alternative to the standard ones.

The string view / string span types are template classes that accepts the type of character via a template parameter, having (for now) a *char* type specialization.
```c++
template <typename CharT>
class BasicStringView{ /*...*/ };
using StringView = BasicStringView<char>;

template <typename CharT>
class BasicStringSpan{ /*...*/ };
using StringSpan = BasicStringSpan<char>;
```
Similarly, the format functions are template functions, allowing the use of different character types. Two sets are defined, a ```basic_format_to``` being the template version and another called ```format_to``` being the *char* type specialization.

The following format functions use the same [format string syntax](#syntax) of {fmt}, which is itself similar to that of Pythons's [str.format](https://docs.python.org/3.8/library/string.html) (although not every option is implemented).

The output format is specified in the *str_fmt* string/string view. It can contain literal text and replacement fields surrounded by braces ```{}```. The fields are replaced with formatted arguments in the resulting string.

The objects to be formated are represented by the *args* argument list.

1. Formats the *args* arguments, writes the result to the iterator (pointer) *str* and returns an iterator (pointer) past the end of the output range.
The function fails if the resulting output string size is greater than *str_count* size.
```c++
template <typename CharT, typename... Args>
CharT* usf::basic_format_to(CharT* str, const std::ptrdiff_t str_count,
                            usf::BasicStringView<CharT> str_fmt, Args&&... args);

template <typename... Args>
char* usf::format_to(char* str, const std::ptrdiff_t str_count,
                     usf::StringView str_fmt, Args&&... args);
```
2. Formats the *args* arguments, writes the result to the string holded by the string span *str* (don't change the span range) and returns a new string span with the range adjusted to the output string size.
The function fails if the resulting output string size is greater than *str*'s span range.
```c++
template <typename CharT, typename... Args>
usf::BasicStringSpan<CharT> usf::basic_format_to(usf::BasicStringSpan<CharT> str,
                                                 usf::BasicStringView<CharT> str_fmt, Args&&... args);

template <typename... Args>
usf::StringSpan usf::format_to(usf::StringSpan str, usf::StringView str_fmt, Args&&... args);
```
## Syntax
(*wip*)

## License
(*wip*)

## Acknowledgments
(*wip*)

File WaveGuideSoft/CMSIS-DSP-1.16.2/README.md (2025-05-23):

# CMSIS-DSP

 

## About

CMSIS-DSP is an optimized compute library for embedded systems (DSP is in the name for legacy reasons).

It provides optimized compute kernels for Cortex-M and for Cortex-A.

Different variants are available according to the core and most of the functions are using a vectorized version when the Helium or Neon extension is available.

This repository contains the CMSIS-DSP library and several other projects:

* Test framework for bare metal Cortex-M or Cortex-A
* Examples for bare metal Cortex-M
* ComputeGraph
* PythonWrapper

You don't need any of the other projects to build and use CMSIS-DSP library. Building the other projects may require installation of other libraries (CMSIS), other tools (Arm Virtual Hardware) or CMSIS build tools.

### License Terms

CMSIS-DSP is licensed under [Apache License 2.0](LICENSE).

### CMSIS-DSP Kernels

Kernels provided by CMSIS-DSP (list not exhaustive):

* Basic mathematics (real, complex, quaternion, linear algebra, fast math functions)
* DSP (filtering)
* Transforms (FFT, MFCC, DCT)
* Statistics 
* Classical ML (Support Vector Machine, Distance functions for clustering ...)

Kernels are provided with several datatypes : f64, f32, f16, q31, q15, q7.

### Python wrapper

A [PythonWrapper](https://pypi.org/project/cmsisdsp/) is also available and can be installed with:

`pip install cmsisdsp`

With this wrapper you can design your algorithm in Python using an API as close as possible to the C API. The wrapper is compatible with NumPy. The wrapper is supporting fixed point arithmetic. This wrapper works in google colab.

The goal is to make it easier to move from a design to a final implementation in C.

## Support / Contact

For any questions or to reach the CMSIS-DSP  team, please create a new issue in https://github.com/ARM-software/CMSIS-DSP/issues

## Table of  content

* [Building for speed](#building-for-speed)
  * [Options to use](#options-to-use)
  * [Options to avoid](#options-to-avoid)
* [Half float support](#half-float-support)
* [How to build](#how-to-build)
  * [How to build with MDK or Open CMSIS-Pack](#how-to-build-with-mdk-or-open-cmsis-pack)
  * [How to build with Make](#how-to-build-with-make)
  * [How to build with cmake](#how-to-build-with-cmake)
  * [How to build with any other build system](#how-to-build-with-any-other-build-system)
  * [How to build for aarch64](#how-to-build-for-aarch64)
* [Code size](#code-size)
* [Folders and files](#folders-and-files)
  * [Folders](#folders)
  * [Files](#files)

## Building for speed

CMSIS-DSP is used when you need performance. As consequence CMSIS-DSP should be compiled with the options giving the best performance:

### Options to use

* `-Ofast` must be used for best performances.
* When using Helium it is strongly advised to use `-Ofast`
* `GCC` is currently not giving good performances when targeting Helium. You should use the Arm compiler

When float are used, then the fpu should be selected to ensure that the compiler is not using a software float emulation.

When building with Helium support, it will be automatically detected by CMSIS-DSP. For Neon, it is not the case and you must enable the option `-DARM_MATH_NEON` for the C compilation. With `cmake` this option is controlled with `-DNEON=ON`.

* `-DLOOPUNROLL=ON` can also be used when compiling with cmake
* It corresponds to the C options `-DARM_MATH_LOOPUNROLL`

Compilers are doing unrolling. So this option may not be needed but it is highly dependent on the compiler. With some compilers, this option is needed to get better performances.

Speed of memory is important. If you can map the data and the constant tables used by CMSIS-DSP in `DTCM` memory then it is better. If you have a cache, enable it.

### Options to avoid

* `-fno-builtin`
* `-ffreestanding` because it enables previous options

The library is doing some type [punning](https://en.wikipedia.org/wiki/Type_punning) to process word 32 from memory as a pair of `q15` or a quadruple of `q7`.  Those type manipulations are done through `memcpy` functions. Most compilers should be able to optimize out those function calls when the length to copy is small (4 bytes).

This optimization will **not** occur when `-fno-builtin` is used and it will have a **very bad** impact on the performances.

Some compiler may also require the use of option `-munaligned-access` to specify that unaligned accesses are used.

## Half float support

`f16` data type (half float) has been added to the library. It is useful only if your Cortex has some half float hardware acceleration (for instance with Helium extension). If you don't need `f16`, you should disable it since it may cause compilation problems. Just define `-DDISABLEFLOAT16` when building.

## How to build

You can build CMSIS-DSP with the open CMSIS-Pack, or cmake, or Makefile and it is also easy to build if you use any other build tool.

### How to build with MDK or Open CMSIS-Pack

The standard way to build is by using the CMSIS pack technology. CMSIS-DSP is available as a pack.

This pack technology is supported by some IDE like [Keil MDK](https://www.keil.com/download/product/) or [Keil studio](https://www.keil.arm.com/).

You can also use those packs using the [Open CMSIS-Pack](https://www.open-cmsis-pack.org/) technology and from command line on any platform.

You should first install the tools from https://github.com/Open-CMSIS-Pack/devtools/tree/main/tools

You can get the CMSIS-Toolbox which is containing the package installer, cmsis build and cmsis project manager. Here is some documentation:

* Documentation about [CMSIS Build](https://open-cmsis-pack.github.io/devtools/buildmgr/latest/index.html)
* Documentation about [CMSIS Pack](https://open-cmsis-pack.github.io/Open-CMSIS-Pack-Spec/main/html/index.html)
* Documentation about [CMSIS Project manager](https://github.com/Open-CMSIS-Pack/devtools/blob/main/tools/projmgr/docs/Manual/Overview.md)

Once you have installed the tools, you'll need to download the pack index using the `cpackget` tool.

Then, you'll need to convert a solution file into `.cprj`. For instance, for the CMSIS-DSP Examples, you can go to: 

`Examples/cmsis_build` 

and then type 

`csolution convert -s examples.csolution_ac6.yml`

This command processes the `examples.csolution_ac6.yml` describing how to build the examples for several platforms. It will generate lots of `.cprj` files that can be built with `cbuild`.

If you want to build the `FFT` example for the `Corstone-300` virtual hardware platform, you could just do:

`cbuild "fftbin.Release+VHT-Corstone-300.cprj"`

### How to build with Make

There is an example `Makefile` in `Source`.

In each source folder (like `BasicMathFunctions`), you'll see files with no `_datatype` suffix (like `BasicMathFunctions.c` and `BasicMathFunctionsF16.c`).

Those files are all you need in your makefile. They are including all other C files from the source folders.

Then, for the includes you'll need to add the paths: `Include`, `PrivateInclude` and, since there is a dependency to CMSIS Core, `Core/Include` from `CMSIS_5/CMSIS`.

If you are building for `Cortex-A` and want to use Neon, you'll also need to include `ComputeLibrary/Include` and the source file in `ComputeLibrary/Source`.

### How to build with cmake

Create a `CMakeLists.txt` and inside add a project.

Add CMSIS-DSP as a subdirectory. The variable `CMSISDSP` is the path to the CMSIS-DSP repository in below example.

```cmake
cmake_minimum_required (VERSION 3.14)

# Define the project
project (testcmsisdsp VERSION 0.1)

add_subdirectory(${CMSISDSP}/Source bin_dsp)
```

CMSIS-DSP is dependent on the CMSIS Core includes. So, you should define `CMSISCORE` on the cmake command line. The path used by CMSIS-DSP will be `${CMSISCORE}/Include`.

You should also set the compilation options to use to build the library.

If you build for Helium, you should use any of the option `MVEF`, `MVEI` or `HELIUM`.

If you build for Neon, use `NEON` and/or `NEONEXPERIMENTAL`.

#### Launching the build

Once cmake has generated the makefiles, you can use a GNU Make to build.

    make VERBOSE=1

### How to build with any other build system

You need the following folders:

* Source
* Include
* PrivateInclude
* ComputeLibrary (only if you target Neon)

In `Source` subfolders, you may either build all of the source file with a datatype suffix (like `_f32.c`), or just compile the files without a datatype suffix. For instance for `BasicMathFunctions`, you can build all the C files except `BasicMathFunctions.c` and `BasicMathFunctionsF16.c`, or you can just build those two files (they are including all of the other C files of the folder).

`f16` files are not mandatory. You can build with `-DDISABLEFLOAT16`

### How to build for aarch64

The intrinsics defined in `Core_A/Include` are not available on recent Cortex-A processors.

But you can still build for those Cortex-A cores and benefit from the Neon intrinsics.

You need to build with `-D__GNUC_PYTHON__` on the compiler command line. This flag was introduced for building the Python wrapper and is disabling the use of CMSIS Core includes.

When this flag is enabled, CMSIS-DSP is defining a few macros used in the library for compiler portability:

```C
#define  __ALIGNED(x) __attribute__((aligned(x)))
#define __STATIC_FORCEINLINE static inline __attribute__((always_inline)) 
#define __STATIC_INLINE static inline
```

If the compiler you are using is requiring different definitions, you can add them to `arm_math_types.h` in the `Include` folder of the library. MSVC and XCode are already supported and in those case, you don't need to define `-D__GNUC_PYTHON__`

Then, you need to define `-DARM_MATH_NEON`

For cmake the equivalent options are:

* `-DHOST=ON`
* `-DNEON=ON`

cmake is automatically including the `ComputeLibrary` folder. If you are using a different build, you need to include this folder too to build with Neon support.

## Code size

Previous versions of the library were using compilation directives to control the code size. It was too complex and not available in case CMSIS-DSP is only delivered as a static library.

Now, the library relies again on the linker to do the code size optimization. But, this implies some constraints on the code you write and new functions had to be introduced.

If you know the size of your FFT in advance, use initializations functions like `arm_cfft_init_64_f32` instead of using the generic initialization functions `arm_cfft_init_f32`. Using the generic function will prevent the linker from being able to deduce which functions and tables must be kept for the FFT and everything will be included.

There are similar functions for RFFT, MFCC ...

If the flag `ARM_DSP_CONFIG_TABLES` is still set, you'll now get a compilation error to remind you that this flag no more have any effect on code size and that you may have to rework the initializations.

## Folders and files

The only folders required to build and use CMSIS-DSP Library are:

* Source
* Include
* PrivateInclude
* ComputeLibrary (only when using Neon)

Other folders are part of different projects, tests or examples.

### Folders

* cmsisdsp
  * Required to build the CMSIS-DSP PythonWrapper for the Python repository
  * It contains all Python packages
* ComputeLibrary:
  * Some kernels required when building CMSIS-DSP with Neon acceleration
* Examples:
  * Examples of use of CMSIS-DSP on bare metal Cortex-M
  * Require the use of CMSIS Build tools
* Include:
  * Include files for CMSIS-DSP
* PrivateInclude:
  * Some include needed to build CMSIS-DSP
* PythonWrapper:
  * C code for the CMSIS-DSP PythonWrapper
  * Examples for the PythonWrapper
* Scripts:
  * Debugging scripts
  * Script to generate some coefficient tables used by CMSIS-DSP
* Source:
  * CMSIS-DSP source
* Testing:
  * CMSIS-DSP Test framework for bare metal Cortex-M and Cortex-A
  * Require the use of CMSIS build tools

### Files

Some files are needed to generate the PythonWrapper:

* PythonWrapper_README.md
* LICENSE
* MANIFEST.in
* pyproject.toml
* setup.py

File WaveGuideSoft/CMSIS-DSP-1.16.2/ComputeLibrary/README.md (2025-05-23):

README
======

This folder is containing two files imported from the ComputeLibrary:

    NEMath.h and arm_cl_tables.c 

In the original compute library, there are instead two other files:

    NEMath.h and NEMath.inl

NEMath.inl is included from NEMath.h whereas in this CMSIS DSP implementation, there is no NEMath.inl and its content is copied into NEMath.h

The tables contained in NEMath.inl have been moved to arm_cl_tables.c and finally the files are in C for the CMSIS DSP library and in C++ in the original Compute Library.

Otherwise, the features and implementations are the same : a few optimized Neon functions.

New aarch64 code have been contributed by the community.

The license covering those files is different : It is a MIT license.
Other parts of the CMSIS-DSP are covered with an Apache-2.0 license.

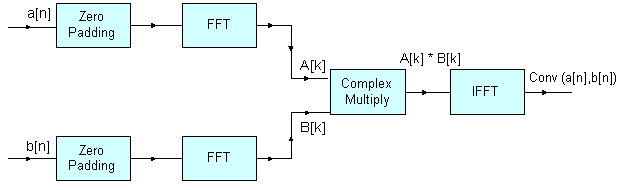
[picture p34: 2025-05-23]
WaveGuideSoft/CMSIS-DSP-1.16.2/Documentation/Doxygen/src/images/Convolution.gif

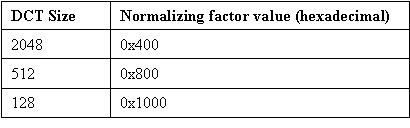
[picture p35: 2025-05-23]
WaveGuideSoft/CMSIS-DSP-1.16.2/Documentation/Doxygen/src/images/dct4NormalizingQ15Table.gif

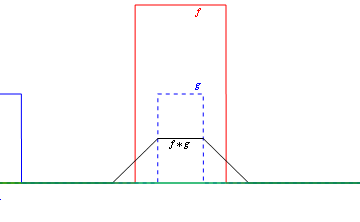
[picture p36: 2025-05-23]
WaveGuideSoft/CMSIS-DSP-1.16.2/Documentation/Doxygen/src/images/Convolution_Animation.gif

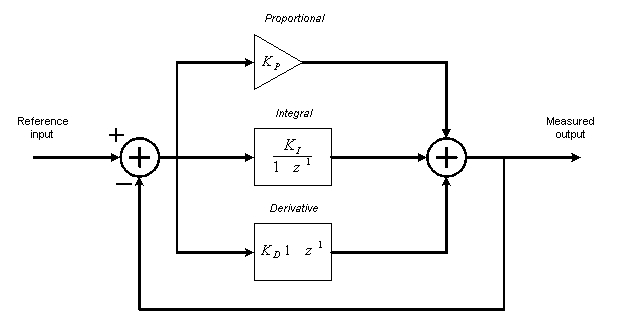
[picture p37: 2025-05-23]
WaveGuideSoft/CMSIS-DSP-1.16.2/Documentation/Doxygen/src/images/PID.gif

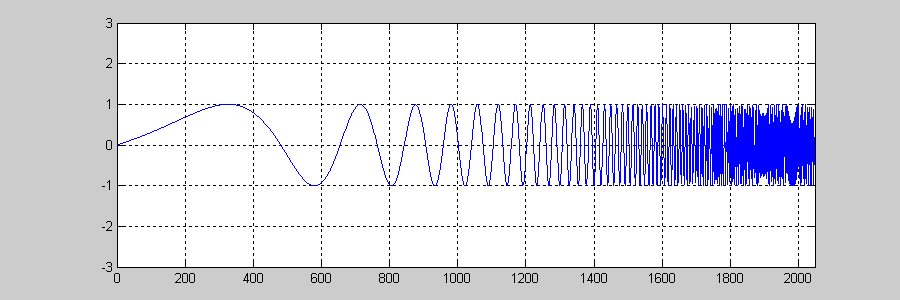
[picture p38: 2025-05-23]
WaveGuideSoft/CMSIS-DSP-1.16.2/Documentation/Doxygen/src/images/GEQ_inputchirp.gif

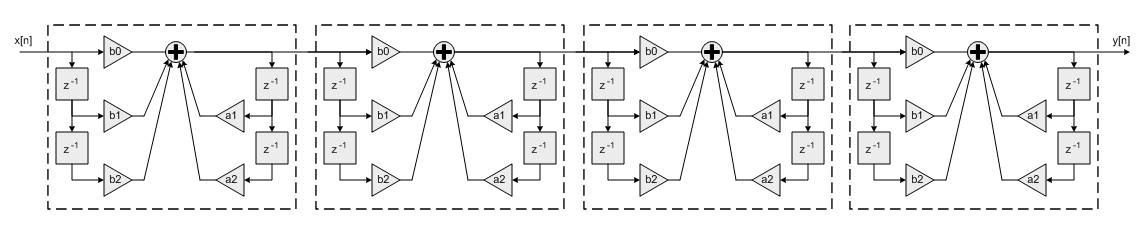
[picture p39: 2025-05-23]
WaveGuideSoft/CMSIS-DSP-1.16.2/Documentation/Doxygen/src/images/BiquadCascade.gif

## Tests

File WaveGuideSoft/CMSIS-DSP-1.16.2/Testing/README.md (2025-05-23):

# TEST FRAMEWORK

This framework is for our own internal use. We decided to release it but, at least in short term, we won't give any help or support about it.

## Summary

Here is a quick summary of how to get started with the framework the first time the repository is cloned. 

First, you must use the same tag than the one for your CMSIS Pack. Otherwise, the cloned source may contain tests for functions which are not yet available in the official pack.

You can also look at the artifact for the commit : it is containing a CMSIS Pack for this commit.

You need `Python 3` and the following Python packages:

```
pip install pyparsing
pip install Colorama
```

Once you have cloned the right version and installed the Python packages, you need to generate some files.

**Generation of all C files needed to build the tests.** 

The commands must be run from Testing folder:

`createDefaultFolder.sh`

`python preprocess.py -f desc.txt`

`python preprocess.py -f desc_f16.txt -o Output_f16.pickle`

`python processTests.py -e`

`python processTests.py -e -f Output_f16.pickle`

**Now the test suite you want to run can be selected:**

`python processTests.py -e BasicTestsF32`

Each time you want to change the test suite to run, you need to execute this function. No need to redo all the previous steps to generate all the missing files.

Note that if the test suite is part of the half float tests, then you'll need to do instead:

`python processTests.py -f Output_f16.pickle -e BasicTestsF16`

**Building the test framework:**

In `Testing\cmsis_build` you can find some scripts:

* `buildsolution.sh` is converting the solution file, using `csolution`,  to generate the `.cprj` files for each target
* `build.sh` is building all the targets using `cbuild` tool

The CMSIS build tools must be installed and configured. You may need to run the CMSIS build tools setup script before the previous steps:

`source /cmsistools/etc/setup`

and you may need to add the path to the `csolution` tool:

`export PATH=$PATH:/cmsistools/bin/linux64`

(If you are on Windows, use the `bin/windows64` folder)

You may need to initialize the pack repository and install the needed packs:

`cpackget init`

`cpackget add -f test_packlist.txt`

The `test_packlist.txt` is in the `Testing\cmsis_build` folder.

**You can then run the executable on Virtual Hardware.** 

For instance, to run the test on the virtual hardware for Corstone 300, if you have the Arm MDK installed on Windows :

`C:\Keil_v5\ARM\VHT\VHT_Corstone_SSE-300_Ethos-U55.exe -f configs\ARM_VHT_Corstone_300_config.txt Objects\test.Release+VHT-Corstone-300.axf > results.txt`

**Parsing the results:**

If you are still in the `cmsis_build` folder:

`python ../processResult.py -f ../Output.pickle -e -r results.txt`

## REQUIREMENTS

Requirements for the test framework. 

### Test descriptions

#### R1 : The tests shall be described in a file
We need a source of truth which is describing all the tests and can be used
to generate code, format output etc ...

#### R2 : The test description should support a hierarchy
We have lots of tests. We need to be able to organize them in a
hierarchical way

#### R3 : A test shall be uniquely identified
We need a way to identify in an unique way each test to ensure traceability and enable to create
history of test results and benchmark.

#### R4 : The unique identifier shall not change when tests are added or removed.
It is important to keep traceability.

#### R5 : The test description shall list the test patterns and input patterns required by the tests

#### R6 : It shall be possible to parametrize the tests

For benchmarking, we may need to vary some dimensions of the tests (like input length).
The tests may depend on several parameters (width, height etc ...)
We need to be able to specify how those parameters are varied.

#### R7 : It shall be possible to specify a subset of parameters (which could be empty) to compute regression.
For instance, if our test is dependent on a vector size, we may want to compute a linear regression
to know how the performances are dependent on the vector size.

But, our test may also depend on another parameter B which is not interesting us in the regression. In that case, the regression formula should not take into account B. And we would have several regression formula for each value of the parameter B.

The parameters of the tests would be Vector Size and B but the Summary parameter only Vector Size.

#### R8 : The concept of a test suite shall be supported.
A test suite is a set of tests packaged with some data.

### Test execution

For following requirements, we define a device under tests (DUT) as the place where the function to test is executed. But the test itself (to check that the execution has been successful could be running on the DUT or on a host like a PC).

#### R9 : The memory should be cleaned between 2 tests
A test should start (as far as possible) in a clean state. There should not be interferences between the tests.

#### R10 : The test may be run on the DUT or on the host

#### R11 : Output of tested functions could be dumped or not

#### R12 : The tested function should not know where are the patterns and how to get them 

#### R13 : Control of the tests could run on the DUT but could also be run on a host

#### R14 : Summary of test execution shall support several formats
(CSV, HTML, Text etc ...)

#### R15 : One should not assume the test environment on the DUT has access to IOs.

## DESIGN PRINCIPLES

The design is a consequence of all the requirements.

### Test description

A test description file is defined with a specific syntax to support R1 to R8.

#### Hierachical structure

    group Root {
        class = Root
        group DSP Test {
            class = DSPTest
            folder = DSP
            suite Basic Tests {
               class = BasicTests
               folder = BasicMaths

The tests are organized in a hierarchy. For each node of the hierarchy, a C++ class is specified.
The script processTest.py is generating C++ codee for the group.
For the test suite, the script is generating a partial implementation since a test suite is containing tests and you need to add the test themselves.

The patterns, output of tests, parameters are also following a hierarchical structure. But they do not need
to be organized in exactly the same way. So, the folder property of a node is optional.

A folder can be reused for different nodes. For instance, you may have a suite for testing and one for benchmarking and both may use the same pattern folder.

A test suite is more complex than a group since it contains the description of the tests and related information.

#### Test suite

The simplest suite is just containing functions:

    suite Basic Tests {
           class = BasicTests
           folder = BasicMaths
     
           Functions {
             Test arm_add_f32:test_add_f32
           }
    }

A function is described with some text and followed by the name of the function in the C++ class.
The text is used when reporting the results of the tests.

The same function can be used for different tests in the suite. The tests will be different due to different input data or parameters.

A test is requiring input patterns, reference patterns and outputs (to be compared to the reference).
Since the test must not know where is the data and how to get it, this information is provided in the test description file.

So, the test suite would be:

    suite Basic Tests {
           class = BasicTests
           folder = BasicMaths
     
           Pattern INPUT1_F32_ID : Input1_f32.txt 
           Pattern INPUT2_F32_ID : Input2_f32.txt 
           Pattern REF_ADD_F32_ID : Reference1_f32.txt
           Output  OUT_SAMPLES_F32_ID : Output
     
           Functions {
             Test arm_add_f32:test_add_f32
           }
    }

A pattern or output description is an ID (to be used in the code) followed by a filename.

The file is in the folder defined with the folder properties of the group / suites.

The root folder for pattern files and output files is different.

#### Benchmarks

A benchmark will often have to be run with different lengths for the input.
So we need a way to communicate arguments to a function.

We make the assumption that those arguments are integers.
In the benchmark results, we may want to generate a CSV (or any other format) with different columns for those arguments.

And we may want to compute a regression formula using only a subset of those arguments.

So, we have the possibility in the suite section to add a parameter section to describe all of this.

    suite Complex Tests {
            class = ComplexTests
            folder = ComplexMaths
     
            ParamList {
                A,B,C
                Summary A,B
                Names "Param A", "Param B"
                Formula "A*B"
            }
     
            Pattern INPUT1_F32_ID : Input1_f32.txt 

In above example we declare that the functions of the suite are using 3 parameters named A,B and C.
We declare that a regression formula will use only A and B. So for each C value, we will get a different
regression formula.

We list the names to use when formatting the output of benchmarks.
We define a regression formula using R syntax. (We do not write "cycles ~ A*B" but only "A*B")

Once parameters have been described, we need a way to feed parameter values to a test.

There are 2 ways. First way is a parameter file. Problem of a parameter file when it has to be included in the test (C array) is that it may be big. So, we also have a parameter generator. It is less flexible but enough for lot of cases.

Those parameters values, when specified with a file, are described with:

            Output  OUT_SAMPLES_F32_ID : Output
            Params PARAM1_ID : Params1.txt

They follow the outputs section and use similar syntax.

When the parameter is specified with a generator then the syntax is :

    Params PARAM3_ID = {
                A = [1,3,5]
                B = [1,3,5]
                C = [1,3,5]
            }

This generator will compute the cartesian product of the 3 lists.

To use parameters with a function the syntax is:

    Functions {
               Test A:testA -> PARAM3_ID
            } -> PARAM1_ID

PARAM1_ID is the default applied to all functions.
In this example we decide to use PARAM3_ID for the testA function.

#### File formats
Pattern files have the following format:

    W
    128
    // 1.150898
    0x3f93509c
    ...

First line if the word size (W,H or B)
Second line is the number of samples
Then for each samples we have an human representation of the value:
// 1.150898

and an hexadecimal representation
0x3f93509c

Output files are only containing the hexadecimal values.

Parameters files have the following format:

    81
    1
    1
    1
    1
    1
    3
    ...

First line is the number of samples. Then the samples.

First line must be a multiple of the number of parameters. In our above example we have 3 parameters A,B,C.
So, the number of possible run must be a multiple of 3 since we need to specify values for all parameters.

#### disabled

Any node (Group, Suite or Function) can be disabled by using disabled { ...}.

A disabled group/suite/test is not executed (and its code not generated for group/suite).
Using disabled for tests is allowing to disable a test without changing the test ID of following tests.

### Memory manager
Memory manager is coming from requirement R9
Its API is defined by virtual class Memory. An implementation ArrayMemory is provided which is using a buffer.
The details of the APIs are in Test.h

A memory manager can provide new buffer, free all the already allocated buffers and give a generation number which is incremented each time all buffer are released.

#### Runner 
According to R13 , the test may be controlled on the DUT or from an external host.
It is implemented with a Runner class. The only implementation provided is IORunner,

A Runner is just an implementation of the visitor pattern. A runner is applied to the tree of tests.
In case of the IO runner, an IO mechanism and a memory manager must be provided.

The runner is running a test and for benchmark measuring the cycles.
Cycles measurement can be based on internal counter or external trace.
Generally, there is a calibration at beginning of the Runner to estimate the overhead of
cycle measurements. This overhead is then removed when doing the measurement.

#### IO
According to R12 and R15, tests do not know how to access patterns. It is a responsiblity implemented with the IO, Pattern and PatternMgr.

IO is about loading patterns and dumping output. It is not about IO in general.
We provide 2 IO implementations : Semihosting and FPGA.

FPGA is when you need to run the tests in a constrained environment where you only have stdout. The inputs of tests are in C array. The script processTest.py will generate those C arrays.

Patterns is the interface to patterns and output from the test point of view.
They will return NULL when a pattern is still referencing a generation of memory older than the current one.

PatternMgr is the link between IO and Memory and knows how to load a pattern and save it into memory.

#### Dump feature
According to R10 and R11, one must be able to disable tests done on the DUT and dump the output so that the test itself can be done on the host.
When instantiating a runner, you can specify the running mode with an enum. For instance Testing::kTestAndDump.
There are 3 modes, Test only, Dump only, Test and dump. 

In dump only mode, tests using pattern will fail but the tests will be considered as passed (because we are only interested in the output).

But it means that no test using patterns shoudl be used in the middle of the test or some part of it may not be executed. Those tests must be kept at the end.

#### processResult
For R14, we have a python script which will process the result of tests and format it into several possible formats like text, CSV, Mathematica dataset. 

## HOW TO RUN IT

### Needed packages

    pip install pyparsing 
    pip install Colorama

If you want to compute summary statistics with regression:

    pip install statsmodels
    pip install numpy
    pip install panda

If you want to run the script which is launching all the tests on all possible configurations then
you'll need yaml:

    pip install pyyaml

### Generate the test patterns in Patterns folder

We have archived lot of test patterns on github. So this step is needed only if you write new test patterns.

    cd Testing
    python PatternGeneration\BasicMaths.py

### Generate the cpp,h and txt files from the desc.txt file

First time the project is cloned from github, you'll need to create some missing folders as done
in the script `createDefaultFolder.sh`

Those folders are used to contain the files generated by the scripts.

Once those folders have been created. You can use following commands to create the generated C files.

    cd ..
    
    python preprocess.py -f desc.txt 

This will create a file `Output.pickle` which is containing a Python object representing
the parsed data structure. It is done because parsing a big test description file is quite slow.

So, it is needed to be done only once or if you modify the test description file.

Then, the tests can be processed to configure the test environment with

    python processTests.py -f Output.pickle

or just

    python processTests.py

You can also use the -e option (for embedded). It will include all the patterns (for the selected tests) into a C array. It is the **preferred** method if you want to run on a board. In below examples, we will
always use -e option.

    python processTests.py -e

You can pass a C++ class to specifiy that you want to generate tests only for a specific group or suite.

    python processTests.py -e BasicTests

You can add a test ID to specify that you wan to run only a specific test in the suite:

    python processTests.py -e BasicTests 4

#### Important:

The very first time you configure the test framework, you'll need to generate C files for all the tests

The reason is that the build is not aware of the filtering and will include some source files even if they are not needed for a given test suite. So those files should at least be present to allow the compilation to proceed. They need to be generated at least once.

To generate all of them the first time, you can do (from `Testing` folder):

`python preprocess.py -f desc.txt`

`python preprocess.py -f desc_f16.txt -o Output_f16.pickle`

`python processTests.py -e`

`python processTests.py -e -f Output_f16.pickle`

### Building and Running

You can use the [CMSIS build tools](https://github.com/Open-CMSIS-Pack/devtools) to build.

In `Testing\cmsis_build` you can find some scripts:

* `buildsolution.sh` is converting the solution file, using `csolution`,  to generate the `.cprj` files for each target
* `build.sh` is building all the targets using `cbuild` tool

You can then run the executable on Virtual Hardware. For instance, to run the test on the virtual hardware for Corstone 300, if you have the Arm MDK installed on Windows :

`C:\Keil_v5\ARM\FVP\MPS2_Cortex-M\FVP_MPS2_Cortex-M55_MDK.exe ^
   -f configs/ARM_VHT_MPS2_M55_config.txt ^
   Objects\test.Release+FVP_M55.axf > results.txt`

### Parse the results

The results generated in previous step can be processed with a Python script.

The `-f` option should be used to tell the script where to find the `Output.pickle` file if the script is not run from the `Testing` folder.

    python processResult.py -f Output.pickle -e -r result.txt

-e option is needed if the mode -e was used with processTests because the output has a different
format with or without -e option.

Some cycles are displayed with the test status (passed or failed). **Don't trust** those cycles for a benchmark.

At this point they are only an indication. The timing code will have to be tested and validated.

### Generate summary statistics

The parsing of the results may have generated some statistics in FullBenchmark folder.

The script summaryBench can parse those results and compute regression formula.

    python summaryBench.py -r build\result.txt

The file result.txt must be placed inside the build folder for this script to work.
Indeed, this script is using the path to result.txt to also find the file currentConfig.csv which has
been created by the cmake command.

The Output.pickle file is used by default. It can be changed with -f option.

The output of this script may look like:

    "ID","CATEGORY","Param C","Regression","MAX"
    1,"DSP:ComplexMaths",1,"225.3749999999999 + A * 0.7083333333333606 + B * 0.7083333333333641 + A*B * 1.3749999999999876",260

Each test is uniquely identified with the CATEGORY and test ID (ID in the suite).
The MAX column is the max of cycles computed for all values of A and B which were used for this benchmark.

### Other tools

To convert some benchmark to an older format.
The PARAMS must be compatible between all suites which are children of AGroup

    python convertToOld.py -e AGroup

Output.pickle is used by default. It can be changed with -f option.

To add a to sqlite3 databse:

    python addToDB.py -e AGroup

Output.pickle is used by default. It can be changed with -f option.

The database must be created with createDb.sql before this script can be used.

### Semihosting or FPGA mode
The script processTests and processResult must be used with additional option -e for the FPGA (embedded mode)

`testmain.cpp`, in semihosting mode, must contain:

```cpp
Client::Semihosting io("../TestDesc.txt","../Patterns","../Output");
```

In FPGA (embedded mode), this lne must be replaced with:

```cpp
Client::FPGA io(testDesc,patterns);
```

testDesc and patterns are char* generated by the script processTests and containing the description
of the tests to run and the test pattern samples to be used.

### Dumping outputs 

To dump the output of the tests, the line

```cpp
Client::IORunner runner(&io,&mgr,Testing::kTestOnly);
```

Must be replaced by

```cpp
Client::IORunner runner(&io,&mgr,Testing::DumpOnly);
```

or

```cpp
Client::IORunner runner(&io,&mgr,Testing::kTestAndDump);
```

and of course, the test must contain a line to dump the outputs.

In DumpOnly mode, reference patterns are not loaded and the test assertions are "failing" but reporting passed.

So, if a test is in the middle of useful code, some part of the code will not execute.

As consequence, if you intend to use the DumpOnly mode, you must ensure that all test assertions are at the
end of your test.

## testmain.cpp

To start the tests you need to:

* Allocate a memory manager
* Choose IO (Semihosting or FPGA)
* Instantiate a pattern manager (linking IO and memory)
* Choose a test Runner (IORunner)
* Instantiate the root object which is containing all tests
* Apply the runner to the root object

This is done in testmain.cpp.
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

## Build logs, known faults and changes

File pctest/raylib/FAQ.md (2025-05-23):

# Frequently Asked Questions

- [What is raylib?](#what-is-raylib)
- [What can I do with raylib?](#what-can-i-do-with-raylib)
- [Which kinds of games can I make with raylib?](#which-kinds-of-games-can-i-make-with-raylib)
- [Can I create non-game applications with raylib?](#can-i-create-non-game-applications-with-raylib)
- [How can I learn to use raylib? Is there some official documentation or tutorials?](#how-can-i-learn-to-use-raylib-is-there-some-official-documentation-or-tutorials)
- [How much does it cost?](#how-much-does-it-cost)
- [What is the raylib license?](#what-is-the-raylib-license)
- [What platforms are supported by raylib?](#what-platforms-are-supported-by-raylib)
- [What programming languages can I use with raylib?](#what-programming-languages-can-i-use-with-raylib)
- [Why is it coded in C?](#why-is-it-coded-in-c)
- [Is raylib a videogames engine?](#is-raylib-a-videogames-engine)
- [What does raylib provide that other engines or libraries don't?](#what-does-raylib-provide-that-other-engines-or-libraries-dont)
- [How does raylib compare to Unity/Unreal/Godot?](#how-does-raylib-compare-to-unityunrealgodot)
- [What development tools are required for raylib?](#what-development-tools-are-required-for-raylib)
- [What are raylib's external dependencies?](#what-are-raylibs-external-dependencies)
- [Can I use raylib with other technologies or libraries?](#can-i-use-raylib-with-other-technologies-or-libraries)
- [What file formats are supported by raylib?](#what-file-formats-are-supported-by-raylib)
- [Does raylib support the Vulkan API?](#does-raylib-support-the-vulkan-api)
- [What could I expect to see in raylib in the future?](#what-could-i-expect-to-see-in-raylib-in-the-future)
- [Who are the raylib developers?](#who-are-the-raylib-developers)
- [MORE QUESTIONS...](https://github.com/raysan5/raylib/wiki/Frequently-Asked-Questions)

### What is raylib?

raylib is a C programming library, designed to be simple and easy-to-use. It provides a set of functions intended for graphics/multimedia applications programming.

### What can I do with raylib?

raylib can be used to create any kind of graphics/multimedia applications: videogames, tools, mobile apps, web applications... Actually it can be used to create any application that requires something to be shown in a display with graphic hardware acceleration (OpenGL); including [IoT](https://en.wikipedia.org/wiki/Internet_of_things) devices with a graphics display.

### Which kinds of games can I make with raylib?

With enough time and effort any kind of game/application can be created but small-mid sized 2d videogames are the best fit. The raylib [examples](https://www.raylib.com/examples.html)/[games](https://www.raylib.com/games.html) and [raylibtech](https://raylibtech.itch.io/) tools are an example of what can be accomplished with raylib.

### Can I create non-game applications with raylib?

Yes, raylib can be used to create any kind of application, not just videogames. For example, it can be used to create [desktop/web tools](https://raylibtech.itch.io/) or also applications for an IoT devices like [Raspberry Pi](https://www.raspberrypi.org/).

### How can I learn to use raylib? Is there some official documentation or tutorials?

raylib does not provide a "standard" API reference documentation like other libraries, all of the raylib functionality is exposed in a simple [cheatsheet](https://www.raylib.com/cheatsheet/cheatsheet.html). Most of the functions are self-explanatory and the required parameters are very intuitive. It's also highly recommended to take a look at [`raylib.h`](https://github.com/raysan5/raylib/blob/master/src/raylib.h) header file or even the source code, that is very clean and organized, intended for teaching.

raylib also provides a big [collection of examples](https://www.raylib.com/examples.html), to showcase the multiple functionality usage (+120 examples). Examples are categorized by the internal module functionality and also define an estimated level of difficulty to guide the users checking them.

There is also a [FAQ on the raylib Wiki](https://github.com/raysan5/raylib/wiki/Frequently-Asked-Questions) with common technical questions.

There are also many tutorials on the internet and YouTube created by the growing raylib community over the years.

[raylib Discord Community](https://discord.gg/raylib) is also a great place to join and ask questions, the community is very friendly and always ready to help.

### How much does it cost?

raylib is [free and open source](https://github.com/raysan5/raylib). Anyone can use raylib library for free to create games/tools/apps but also the source code of raylib is open for anyone to check it, modify it, adapt it as required or just learn how it works internally.

### What is the raylib license?

raylib source code is licensed under an unmodified zlib/libpng license, which is an OSI-certified, BSD-like license that allows static linking with closed-source software. Check [LICENSE](https://github.com/raysan5/raylib/blob/master/LICENSE) for further details.

### What platforms are supported by raylib?

raylib source code can be compiled for the following platforms:

 - Windows (7, 8.1, 10, 11)
 - Linux - Desktop (multiple distributions, X11 and Wayland based)
 - Linux - Native (no windowing system, [DRM](https://en.wikipedia.org/wiki/Direct_Rendering_Manager))
 - macOS (multiple versions, including ARM64)
 - FreeBSD, OpenBSD, NetBSD, DragonFly
 - Raspberry Pi (desktop and native)
 - Android (multiple API versions and architectures)
 - HTML5 (WebAssembly)
 - Haiku

raylib code has also been ported to several [homebrew](https://en.wikipedia.org/wiki/Homebrew_(video_games)) platforms: N3DS, Switch, PS4, PSVita.

Also note that raylib is a low-level library that can be easily ported to any platform with OpenGL support (or similar API).

### What programming languages can I use with raylib?

raylib original version is coded in C language (using some C99 features) but it has bindings to +60 programming languages. Check [BINDINGS.md](https://github.com/raysan5/raylib/blob/master/BINDINGS.md) for details.

### Why is it coded in C?

It's a simple language, no high-level code abstractions like [OOP](https://en.wikipedia.org/wiki/Object-oriented_programming), just data types and functions. It's a very enjoyable language to code.

### Is raylib a videogames engine?

I personally consider raylib a graphics library with some high-level features rather than an engine. The line that separates a library/framework from an engine could be very confusing; raylib provides all the required functionality to create simple games or small applications but it does not provide 3 elements that I personally consider any "engine" should provide: Screen manager, GameObject/Entity manager and Resource Manager. Still, most users do not need those elements or just code simple approaches on their own.

### What does raylib provide that other engines or libraries don't?

I would say "simplicity" and "enjoyment" at a really low level of coding but actually is up to the user to discover it, to try it and to see if it fits their needs. raylib is not good for everyone but it's worth a try.

### How does raylib compare to Unity/Unreal/Godot?

Those engines are usually big and complex to use, providing lot of functionality. They require some time to learn and test, they usually abstract many parts of the game development process and they usually provide a set of tools to assist users on their creations (like a GUI editor).

raylib is a simple programming library, with no integrated tools or editors. It gives full control to users at a very low level to create graphics applications in a more handmade way.

### What development tools are required for raylib?

To develop raylib programs you only need a text editor (with recommended code syntax highlighting) and a compiler.

A [raylib Windows Installer](https://raysan5.itch.io/raylib) package is distributed including the Notepad++ editor and MinGW (GCC) compiler pre-configured for Windows for new users as an starter-pack but for more advanced configurations with other editors/compilers, [raylib Wiki](https://github.com/raysan5/raylib/wiki) provides plenty of configuration tutorials.

### What are raylib's external dependencies?

raylib is self-contained, it has no external dependencies to build it. But internally raylib uses several libraries from other developers, mostly used to load specific file formats.

A detailed list of raylib dependencies can be found on the [raylib Wiki](https://github.com/raysan5/raylib/wiki/raylib-dependencies).

### Can I use raylib with other technologies or libraries?

Yes, raylib can be used with other libraries that provide specific functionality. There are multiple examples of raylib integrations with libraries like Spine, Tiled, Dear Imgui and several physics engines.

### What file formats are supported by raylib?

raylib can load data from multiple standard file formats:

 - Image/Textures: PNG, BMP, TGA, JPG, GIF, QOI, PSD, DDS, HDR, KTX, ASTC, PKM, PVR
 - Fonts: FNT (sprite font), TTF, OTF
 - Models/Meshes: OBJ, IQM, GLTF, VOX, M3D
 - Audio: WAV, OGG, MP3, FLAC, XM, MOD, QOA
 
### Does raylib support the Vulkan API?

No, raylib is built on top of OpenGL API, and there are currently no plans to support any other graphics APIs. In any case, raylib uses rlgl as an abstraction layer to support different OpenGL versions. If really required, a Vulkan backend equivalent could be added but creating that abstraction layer would imply a considerable amount of work.

### What could I expect to see in raylib in the future?

The main focus of the library is simplicity. Most of the efforts are invested in maintainability and bug-fixing. Despite new small features being regularly added, it's not the objective for raylib to become a full-featured engine. Personally I prefer to keep it small and enjoyable.

### Who are the raylib developers?

The main raylib developer and maintainer is [Ramon Santamaria](https://www.linkedin.com/in/raysan/) but there are 360+ contributors that have helped by adding new features, testing the library and solving issues in the 9+ years life of raylib.

The full list of raylib contributors can be seen [on GitHub](https://github.com/raysan5/raylib/graphs/contributors).

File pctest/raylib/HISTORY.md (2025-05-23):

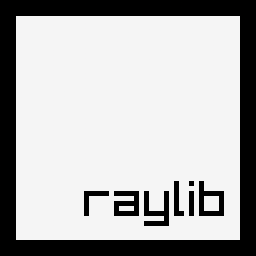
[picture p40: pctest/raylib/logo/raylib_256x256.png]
raylib logo


introduction
------------

I started developing videogames in 2006 and some years later I started teaching videogames development to young people with artistic profiles, most of students had never written a single line of code.

I decided to start with C language basis and, after searching for the most simple and easy-to-use library to teach videogames programming, I found [WinBGI](https://winbgim.codecutter.org/); it was great and it worked very well with students, in just a couple of weeks, those students that had never written a single line of code were able to program (and understand) a simple PONG game, some of them even a BREAKOUT!

But WinBGI was not the clearest and most organized library for my taste. There were lots of things I found confusing and some function names were not clear enough for most of the students; not to mention the lack of transparencies support and no hardware acceleration.

So, I decided to create my own library, hardware accelerated, clear function names, quite organized, well structured, plain C coding and, most importantly, primarily intended to learn videogames programming.

My previous videogames development experience was mostly in C# and [XNA](https://en.wikipedia.org/wiki/Microsoft_XNA) and I really loved it, so, I decided to use C# language style notation and XNA naming conventions. That way, students were able to move from raylib to XNA, MonoGame or similar libs extremely easily.

raylib started as a weekend project and after three months of hard work, **raylib 1.0 was published on November 2013**.

Enjoy it.

notes on raylib 1.1
-------------------

On April 2014, after 6 months of first raylib release, raylib 1.1 was released. This new version presents a complete internal redesign of the library to support OpenGL 1.1, OpenGL 3.3+ and OpenGL ES 2.0.

 - A new module named [rlgl](https://github.com/raysan5/raylib/blob/master/src/rlgl.h) has been added to the library. This new module translates raylib-OpenGL-style immediate mode functions (i.e. rlVertex3f(), rlBegin(), ...) to different versions of OpenGL (1.1, 3.3+, ES2), selectable by one define.

 - [rlgl](https://github.com/raysan5/raylib/blob/master/src/rlgl.h) also comes with a second new module named [raymath](https://github.com/raysan5/raylib/blob/master/src/raymath.h), which includes a bunch of useful functions for 3d-math with vectors, matrices and quaternions.

Some other big changes of this new version have been the support for OGG file loading and stream playing, and the support of DDS texture files (compressed and uncompressed) along with mipmaps support.

Lots of code changes and a lot of testing have concluded in this amazing new raylib 1.1.

notes on raylib 1.2
-------------------

On September 2014, after 5 months of raylib 1.1 release, it comes raylib 1.2. Again, this version presents a complete internal redesign of [core](https://github.com/raysan5/raylib/blob/master/src/rcore.c) module to support two new platforms: [Android](http://www.android.com/) and [Raspberry Pi](http://www.raspberrypi.org/).

It's been some months of really hard work to accommodate raylib to those new platforms while keeping it easy for the users. On Android, raylib manages internally the activity cycle, as well as the inputs; on Raspberry Pi, a complete raw input system has been written from scratch.

 - A new display initialization system has been created to support multiple resolutions, adding black bars if required; the user only defines the desired screen size and it gets properly displayed.

 - Now raylib can easily deploy games to Android devices and Raspberry Pi (console mode).

Lots of code changes and a lot of testing have concluded in this amazing new raylib 1.2.

In December 2014, new raylib 1.2.2 was published with support to compile directly for web (html5) using [emscripten](http://kripken.github.io/emscripten-site/) and [asm.js](http://asmjs.org/).

notes on raylib 1.3
-------------------

On September 2015, after 1 year of raylib 1.2 release, arrives raylib 1.3. This version adds shaders functionality, improves tremendously textures module and also provides some new modules (camera system, gestures system, immediate-mode gui).

 - Shaders support is the biggest addition to raylib 1.3, with support for easy shaders loading and use. Loaded shaders can be attached to 3d models or used as fullscreen post-processing effects. A bunch of postprocessing shaders are also included in this release, check raylib/shaders folder.

 - Textures module has grown to support most of the internal texture formats available in OpenGL (RGB565, RGB888, RGBA5551, RGBA4444, etc.), including compressed texture formats (DXT, ETC1, ETC2, ASTC, PVRT); raylib 1.3 can load .dds, .pkm, .ktx, .astc and .pvr files.

 - A brand new [camera](https://github.com/raysan5/raylib/blob/master/src/rcamera.h) module offers to the user multiple preconfigured ready-to-use camera systems (free camera, 1st person, 3rd person). Camera modes are very easy to use, just check examples: [core_3d_camera_free.c](https://github.com/raysan5/raylib/blob/master/examples/core/core_3d_camera_free.c) and [core_3d_camera_first_person.c](https://github.com/raysan5/raylib/blob/master/examples/core/core_3d_camera_first_person.c).

 - New [gestures](https://github.com/raysan5/raylib/blob/master/src/rgestures.h) module simplifies gestures detection on Android and HTML5 programs.

 - [raygui](https://github.com/raysan5/raylib/blob/master/examples/shapes/raygui.h), the new immediate-mode GUI module offers a set of functions to create simple user interfaces, primarily intended for tools development. It's still in an experimental state but already fully functional.

Most of the examples have been completely rewritten and +10 new examples have been added to show the new raylib features.

Lots of code changes and a lot of testing have concluded in this amazing new raylib 1.3.

notes on raylib 1.4
-------------------

On February 2016, after 4 months of raylib 1.3 release, it comes raylib 1.4. For this new version, lots of parts of the library have been reviewed, lots of bugs have been solved and some interesting features have been added.

 - First big addition is a set of [Image manipulation functions](https://github.com/raysan5/raylib/blob/master/src/raylib.h#L1331) that have been added to crop, resize, colorize, flip, dither and even draw image-to-image or text-to-image. Now basic image processing can be done before converting the image to texture for usage.

 - SpriteFonts system has been improved, adding support for AngelCode fonts (.fnt) and TrueType Fonts (using [stb_truetype](https://github.com/nothings/stb/blob/master/stb_truetype.h) helper library). Now raylib can read standard .fnt font data and also generate at loading a SpriteFont from a TTF file.

 - New [physac](https://github.com/raysan5/raylib/blob/master/src/physac.h) physics module for basic 2D physics support. Still in development but already functional. Module comes with some usage examples for basic jump and level interaction and also force-based physic movements.

 - [raymath](https://github.com/raysan5/raylib/blob/master/src/raymath.h) module has been reviewed; some bugs have been solved and the module has been converted to a header-only file for easier portability, optionally, functions can also be used as inline.

 - [gestures](https://github.com/raysan5/raylib/blob/master/src/rgestures.h) module has been redesigned and simplified, now it can process touch events from any source, including the mouse. This way, gestures system can be used on any platform providing a unified way to work with inputs and allowing the user to create multiplatform games with only one source code.

 - Raspberry Pi input system has been redesigned to better read raw inputs using generic Linux event handlers (keyboard:`stdin`, mouse:`/dev/input/mouse0`, gamepad:`/dev/input/js0`). Gamepad support has also been added (experimental).

Other important improvements are the functional raycast system for 3D picking, including some ray collision-detection functions,
and the addition of two simple functions for persistent data storage. Now raylib users can save and load game data in a file (only some platforms are supported). A simple [easings](https://github.com/raysan5/raylib/blob/master/examples/shapes/reasings.h) module has also been added for values animation.

Up to 8 new code examples have been added to show the new raylib features and +10 complete game samples have been provided to learn
how to create some classic games like Arkanoid, Asteroids, Missile Commander, Snake or Tetris.

Lots of code changes and lots of hours of hard work have concluded in this amazing new raylib 1.4.

notes on raylib 1.5
-------------------

On July 2016, after 5 months of raylib 1.4 release, arrives raylib 1.5. This new version is the biggest boost of the library until now, lots of parts of the library have been redesigned, lots of bugs have been solved and some **AMAZING** new features have been added.

 - VR support: raylib supports **Oculus Rift CV1**, one of the most anticipated VR devices in the market. Additionally, raylib supports simulated VR stereo rendering, independent of the VR device; it means, raylib can generate stereo renders with custom head-mounted-display device parameters, that way, any VR device in the market can be **simulated in any platform** just configuring device parameters (and consequently, lens distortion). To enable VR is [extremely easy](https://github.com/raysan5/raylib/blob/master/examples/core_oculus_rift.c).

 - New materials system: now raylib supports standard material properties for 3D models, including diffuse-ambient-specular colors and diffuse-normal-specular textures. Just assign values to standard material and everything is processed internally.

 - New lighting system: added support for up to 8 configurable lights and 3 light types: **point**, **directional** and **spot** lights. Just create a light, configure its parameters and raylib manages to render internally for every 3d object using standard material.

 - Complete gamepad support on Raspberry Pi: Gamepad system has been completely redesigned. Now multiple gamepads can be easily configured and used; gamepad data is read and processed in raw mode in a second thread.

 - Redesigned physics module: [physac](https://github.com/raysan5/raylib/blob/master/src/physac.h) module has been converted to header only and usage [has been simplified](https://github.com/raysan5/raylib/blob/master/examples/physics_basic_rigidbody.c). Performance has also been significantly improved, now physic objects are managed internally in a second thread.

 - Audio chiptunes support and mixing channels: Added support for module audio music (.xm, .mod) loading and playing. Multiple mixing channels are now also supported. All these features thanks to the amazing work of @kd7tck.

Other additions include a [2D camera system](https://github.com/raysan5/raylib/blob/master/examples/core/core_2d_rcamera.c), render textures for offline render (and most comprehensive [postprocessing](https://github.com/raysan5/raylib/blob/master/examples/shaders/shaders_postprocessing.c)) or support for legacy OpenGL 2.1 on desktop platforms.

This new version is so massive that is difficult to list all the improvements, most of the raylib modules have been reviewed and [rlgl](https://github.com/raysan5/raylib/blob/master/src/rlgl.h) module has been completely redesigned to accommodate to new material-lighting systems and stereo rendering. You can check [CHANGELOG](https://github.com/raysan5/raylib/blob/master/CHANGELOG) file for a more detailed list of changes.

Up to 8 new code examples have been added to show the new raylib features and also some samples to show the usage of [rlgl](https://github.com/raysan5/raylib/blob/master/examples/others/rlgl_standalone.c) and [audio](https://github.com/raysan5/raylib/blob/master/examples/audio_standalone.c) raylib modules as standalone libraries.

Lots of code changes (+400 commits) and lots of hours of hard work have concluded in this amazing new raylib 1.5.

notes on raylib 1.6
-------------------

On November 2016, only 4 months after raylib 1.5, arrives raylib 1.6. This new version represents another big review of the library and includes some interesting additions. This version commemorates raylib 3rd anniversary (raylib 1.0 was published on November 2013) and it is a stepping stone for raylib future. raylib roadmap has been reviewed and redefined to focus on its primary objective: create a simple and easy-to-use library to learn videogames programming. Some of the new features:

 - Complete [raylib Lua binding](https://github.com/raysan5/raylib-lua). All raylib functions plus the +60 code examples have been ported to Lua, now Lua users can enjoy coding videogames in Lua while using all the internal power of raylib. This addition also open the doors to Lua scripting support for a future raylib-based engine, being able to move game logic (Init, Update, Draw, De-Init) to Lua scripts while keep using raylib functionality.

 - Completely redesigned [audio module](https://github.com/raysan5/raylib/blob/master/src/raudio.c). Based on the new direction taken in raylib 1.5, it has been further improved and more functionality added (+20 new functions) to allow raw audio processing and streaming. [FLAC file format support](https://github.com/raysan5/raylib/blob/master/src/external/dr_flac.h) has also been added. In the same line, [OpenAL Soft](https://github.com/kcat/openal-soft) backend is now provided as a static library in Windows to allow static linking and get ride of OpenAL32.dll. Now raylib Windows games are completely self-contained, no external libraries are required anymore!

 - [Physac](https://github.com/victorfisac/Physac) module has been moved to its own repository and it has been improved A LOT, actually, the library has been completely rewritten from scratch by [@victorfisac](https://github.com/victorfisac), multiple samples have been added together with countless new features to match current standard 2D physic libraries. Results are amazing!

 - Camera and gestures modules have been reviewed, highly simplified and ported to single-file header-only libraries for easier portability and usage flexibility. Consequently, camera system usage has been simplified in all examples.

 - Improved Gamepad support on Windows and Raspberry Pi with the addition of new functions for custom gamepad configurations but supporting by default PS3 and Xbox-based gamepads.

 - Improved textures and text functionality, adding new functions for texture filtering control and better TTF/AngelCode fonts loading and generation support.

Build system improvement. Added support for raylib dynamic library generation (raylib.dll) for users that prefer dynamic library linking. Also thinking on advanced users, it has been added pre-configured [Visual Studio C++ 2015 solution](https://github.com/raysan5/raylib/tree/master/projects/vs2015) with raylib project and C/C++ examples for users that prefer that professional IDE and compiler.

New examples, new functions, complete code-base review, multiple bugs corrected... this is raylib 1.6. Enjoy making games.

notes on raylib 1.7
-------------------

On May 2017, around 6 months after raylib 1.6, comes another raylib installment, raylib 1.7. This time library has been improved a lot in terms of consistency and cleanness. As stated in [this patreon article](https://www.patreon.com/posts/raylib-future-7501034), this new raylib version has focused efforts in becoming more simple and easy-to-use to learn videogames programming. Some highlights of this new version are:

 - More than 30 new functions added to the library, functions to control Window, utils to work with filenames and extensions, functions to draw lines with custom thick, mesh loading, functions for 3d ray collisions detailed detection, functions for VR simulation and much more... Just check [CHANGELOG](CHANGELOG) for a detailed list of additions!

 - Support of [configuration flags](https://github.com/raysan5/raylib/issues/200) on every raylib module. Advanced users can customize raylib just by choosing desired features, and defining some configuration flags on modules compilation. That way users can control library size and available functionality.

 - Improved [build system](https://github.com/raysan5/raylib/blob/master/src/Makefile) for all supported platforms (Windows, Linux, OSX, RPI, Android, HTML5) with a unique Makefile to compile sources. Added support for Android compilation with a custom standalone toolchain and also multiple build compilation flags.

 - New [examples](http://www.raylib.com/examples.html) and [sample games](http://www.raylib.com/games.html) added. All sample material has been reviewed, removing useless examples and adding more comprehensive ones; all material has been ported to the latest raylib version and tested on multiple platforms. Examples folder structure has been improved and also build systems.

 - Improved library consistency and organization in general. Functions and parameters have been renamed, some parts of the library have been cleaned and simplified, some functions have been moved to examples (lighting, Oculus Rift CV1 support) towards a more generic library implementation. Lots of hours have been invested in this process...

Some other features: Gamepad support on HTML5, RPI touch screen support, 32bit audio support, frames timing improvements, public log system, rres file format support, automatic GIF recording...

And here is another version of **raylib, a simple and easy-to-use library to enjoy videogames programming**. Enjoy it.

notes on raylib 1.8
-------------------

October 2017, around 5 months after latest raylib version, another release is published: raylib 1.8. Again, several modules of the library have been reviewed and some new functionality added. Main changes of this new release are:

 - [Procedural image generation](https://github.com/raysan5/raylib/blob/master/examples/textures/textures_image_generation.c) function, a set of new functions have been added to generate gradients, checked, noise and cellular images from scratch. Image generation could be useful for certain textures or learning purposes.

 - [Parametric mesh generation](https://github.com/raysan5/raylib/blob/master/examples/models/models_mesh_generation.c) functions, create 3d meshes from scratch just defining a set of parameters, meshes like cube, sphere, cylinder, torus, knot and more can be very useful for prototyping or for lighting and texture testing.

 - PBR Materials support, a completely redesigned shaders and material system allows advanced materials definition and usage, with fully customizable shaders. Some new functions have been added to generate the environment textures required for PBR shading and a a new complete [PBR material example](https://github.com/raysan5/raylib/blob/master/examples/models/models_material_pbr.c) is also provided for reference.

 - Custom Android APK build pipeline with [simple Makefile](https://github.com/raysan5/raylib/blob/master/templates/simple_game/Makefile). Actually, full code building mechanism based on plain Makefile has been completely reviewed and Android building has been added for sources and also for examples and templates building into the final APK package. This way, raylib Android building has been greatly simplified and integrated seamlessly into standard build scripts.

 - [rlgl](https://github.com/raysan5/raylib/blob/master/src/rlgl.h) module has been completely reviewed and most of the functions renamed for consistency. This way, standalone usage of rlgl is promoted, with a [complete example provided](https://github.com/raysan5/raylib/blob/master/examples/others/rlgl_standalone.c). rlgl offers a pseudo-OpenGL 1.1 immediate-mode programming-style layer, with backends to multiple OpenGL versions.

 - [raymath](https://github.com/raysan5/raylib/blob/master/src/raymath.h) library has been also reviewed to align with other advance math libraries like [GLM](https://github.com/g-truc/glm). Matrix math has been improved and simplified, some new Quaternion functions have been added and Vector3 functions have been renamed all around the library for consistency with new Vector2 functionality.

Additionally, as always, examples and templates have been reviewed to work with new version (some new examples have been added), all external libraries have been updated to latest stable version and latest Notepad++ and MinGW have been configured to work with new raylib. For a full list of changes, just check [CHANGELOG](CHANGELOG).

New installer provided, web updated, examples re-builded, documentation reviewed... **new raylib 1.8 published**. Enjoy coding games.

notes on raylib 2.0
-------------------

It's been 9 months since last raylib version was published, a lot of things have changed since then... This new raylib version represents an inflection point in the development of the library and so, we jump to a new major version... Here is the result of almost **5 years and thousands of hours of hard work**... here is... **raylib 2.0**

In **raylib 2.0** the full API has been carefully reviewed for better consistency, some new functionality has been added and the overall raylib experience has been greatly improved... The key features of new version are:

 - **Complete removal of external dependencies.** Finally, raylib does not require external libraries to be installed and linked along with raylib, all required libraries are contained and compiled within raylib. Obviously some external libraries are required but only the strictly platform-dependent ones, the ones that come installed with the OS. So, raylib becomes a self-contained platform-independent games development library.

 - **Full redesign of audio module to use the amazing miniaudio library**, along with external dependencies removal, OpenAL library has been replaced by [miniaudio](https://github.com/dr-soft/miniaudio), this brand new library offers automatic dynamic linking with default OS audio systems. Undoubtedly, the perfect low-level companion for raylib audio module!

 - **Support for continuous integration building*** through AppVeyor and Travis CI. Consequently, raylib GitHub develop branch has been removed, simplifying the code-base to a single master branch, always stable. Every time a new commit is deployed, library is compiled for **up-to 12 different configurations**, including multiple platforms, 32bit/64bit and multiple compiler options! All those binaries are automatically attached to any new release!

 - **More platforms supported and tested**, including BSD family (FreeBSD, openBSD, NetBSD, DragonFly) and Linux-based family platforms (openSUSE, Debian, Ubuntu, Arch, NixOS...). raylib has already been added to some package managers! Oh, and last but not less important, **Android 64bit** is already supported by raylib!

 - **Support for TCC compiler!** Thanks to the lack of external dependencies, raylib can now be easily compiled with a **minimal toolchain**, like the one provided by Tiny C Compiler. It opens the door to an amazing future, allowing, for example, static linkage of libtcc for **runtime compilation of raylib-based code**... and the library itself if required! Moreover, TCC is blazing fast, it can compile all raylib in a couple of seconds!

 - Refactored all raylib configuration #defines into a **centralized `config.h` header**, with more than **40 possible configuration options** to compile a totally customizable raylib version including only desired options like supported file formats or specific functionality support. It allows generating a trully ligth-weight version of the library if desired!

A part of that, lots of new features, like a brand **new font rendering and packaging system** for TTF fonts with **SDF support** (thanks to the amazing STB headers), new functions for **CPU image data manipulation**, new orthographic 3d camera mode, a complete review of `raymath.h` single-file header-only library for better consistency and performance, new examples and way, [way more](https://github.com/raysan5/raylib/blob/master/CHANGELOG).

Probably by now, **raylib 2.0 is the simplest and easiest-to-use library to enjoy (and learn) videogames programming**... but, undoubtedly its development has exceeded any initial objective; raylib has become a simple and easy-to-use truly multiplatform portable standalone media library with thousands of possibilities... and that's just the beginning!

notes on raylib 2.5
-------------------

After almost one years since latest raylib installment, here is **raylib 2.5**. A lot of work has been put on this new version and consequently I decided to bump versioning several digits. The complete list of changes and additions is humungous, details can be found in the [CHANGELOG](CHANGELOG), and here is a short recap with the highlight improvements.

 - New **window management and file system functions** to query monitor information, deal with clipboard, check directory files info and even launch a URL with default system web browser. Experimental **High-DPI monitor support** has also been added through a compile flag.

 - **Redesigned Gamepad mechanism**, now generic for all platforms and gamepads, no more specific gamepad configurations.
**Redesigned UWP input system**, now raylib supports UWP seamlessly, previous implementation required a custom input system implemented in user code.

 - `rlgl` module has been redesigned to **support a unique buffer for shapes drawing batching**, including LINES, TRIANGLES, QUADS in the same indexed buffer, also added support for multi-buffering if required. Additionally, `rlPushMatrix()`/`rlPopMatrix()` functionality has been reviewed to behave exactly like OpenGL 1.1, `models_rlgl_solar_system` example has been added to illustrate this behavior.

 - **VR simulator** has been reviewed to **allow custom configuration of Head-Mounted-Device parameters and distortion shader**, `core_vr_simulator` has been properly adapted to showcase this new functionality, now the VR simulator is a generic configurable stereo rendering system that allows any VR device simulation with just a few lines of code or even dynamic tweaking of HMD parameters.

 - Support for **Unicode text drawing**; now raylib processes UTF8 strings on drawing, supporting Unicode codepoints, allowing rendering mostly any existent language (as long as the font with the glyphs is provided). An amazing example showing this feature has also been added: `text_unicode`.

 - Brand **new text management API**, with the addition of multiple functions to deal with string data, including functionality like replace, insert, join, split, append, to uppercase, to lower... Note that most of those functions are intended for text management on rendering, using pre-loaded internal buffers, avoiding new memory allocation that user should free manually.

 - Multiple **new shapes and textures drawing functions** to support rings (`DrawRing()`, `DrawRingLines()`), circle sectors (`DrawCircleSector()`, `DrawCircleSectorLines()`), rounded rectangles (`DrawRectangleRounded()`, `DrawRectangleRoundedLines()`) and also n-patch textures (`DrawTextureNPatch()`), detailed examples have been added to illustrate all this new functionality.

 - Experimental **cubemap support**, to automatically load multiple cubemap layouts (`LoadTextureCubemap()`). It required some internal `rlgl` redesign to allow cubemap textures.

 - **Skeletal animation support for 3d models**, this addition implied a redesign of `Model` data structure to accommodate multiple mesh/multiple materials support and bones information. Multiple models functions have been reviewed and added on this process, also **glTF models loading support** has been added.

This is just a brief list with some of the changes of the new **raylib 2.5** but there is way more, about **70 new functions** have been added and several subsystems have been redesigned. More than **30 new examples** have been created to show the new functionalities and better illustrate already available ones.

It has been a long year of hard work to make raylib a solid technology to develop new products over it.

notes on raylib 3.0
-------------------

After **10 months of intense development**, new raylib version is ready. Despite primary intended as a minor release, the [CHANGELIST](CHANGELOG) has grown so big and the library has changed so much internally that it finally became a major release. Library **internal ABI** has received a big redesign and review, targeting portability, integration with other platforms and making it a perfect option for other programming [language bindings](BINDINGS.md).

 - All **global variables** from the multiple raylib modules have been moved to a **global context state**, it has several benefits, first, better code readability with more comprehensive variable naming and categorization (organized by types, i.e. `CORE.Window.display.width`, `CORE.Input.Keyboard.currentKeyState` or `RLGL.State.modelview`). Second, it allows better memory management to load global context state dynamically when required (not at the moment), making it easy to implement a **hot-reloading mechanism** if desired.

 - All **memory allocations** on raylib and its dependencies now use `RL_MALLOC`, `RL_FREE` and similar macros. Now users can easily hook their own memory allocation mechanism if desired, having more control over memory allocated internally by the library. Additionally, it makes it easier to port the library to embedded devices where memory control is critical. For more info check raylib issue #1074.

 - All **I/O file accesses** from raylib are being moved to **memory data access**, now all I/O file access is centralized into just four functions: `LoadFileData()`, `SaveFileData()`, `LoadFileText()`, `SaveFileText()`. Users can just update those functions to any I/O file system. This change makes it easier to integrate raylib with **Virtual File Systems** or custom I/O file implementations.

 - All **raylib data structures** have been reviewed and optimized for pass-by-value usage. One of raylib distinctive design decisions is that most of its functions receive and return data by value. This design makes raylib really simple for newcomers, avoiding pointers and allowing complete access to all structures data in a simple way. The downside is that data is copied on stack every function call and that copy could be costly so, all raylib data structures have been optimized to **stay under 64 bytes** for fast copy and retrieve.

 - All **raylib tracelog messages** have been reviewed and categorized for a more comprehensive output information when developing raylib applications, now all display, input, timer, platform, auxiliar libraries, file-accesses, data loading/unloading issues are properly reported with more detailed and visual messages.

 - `raudio` module has been internally reviewed to accommodate the new `Music` structure (converted from previous pointer format) and the module has been adapted to the **highly improved** [`miniaudio v0.10`](https://github.com/dr-soft/miniaudio).

 - `text` module reviewed to **improve fonts generation** and text management functions, `Font` structure has been redesigned to better accommodate characters data, decoupling individual characters as `Image` glyphs from the font atlas parameters. Several improvements have been made to better support Unicode strings with UTF-8 encoding.

 - **Multiple new examples added** (most of them contributed by raylib users) and all examples reviewed for correct execution on most of the supported platforms, specially Web and Raspberry Pi. A detailed categorized table has been created on github for easy examples navigation and code access.

 - New **GitHub Actions CI** system has been implemented for Windows, Linux and macOS code and examples compilation on every new commit or PR to make sure library keeps stable and usable with no breaking bugs.

Note that only key changes are listed here but there is way more! About **30 new functions**, multiple functions reviewed, bindings to [+40 programming languages](https://github.com/raysan5/raylib/blob/master/BINDINGS.md) and great samples/demos/tutorials [created by the community](https://discord.gg/raylib), including raylib integration with [Spine](https://github.com/WEREMSOFT/spine-raylib-runtimes), [Unity](https://unitycoder.com/blog/2019/12/09/using-raylib-dll-in-unity/), [Tiled](https://github.com/OnACoffeeBreak/raylib_tiled_import_with_tmx), [Nuklear](http://bedroomcoders.co.uk/implementing-a-3d-gui-with-raylib/), [enet](https://github.com/nxrighthere/NetDynamics) and [more](https://github.com/raysan5/raylib/issues/1079)!

It has been **10 months of improvements** to create the best raylib ever.

Welcome to **raylib 3.0**.

notes on raylib 3.5 - 7th Anniversary Edition
---------------------------------------------

It's December 25th... this crazy 2020 is about to finish and finally the holidays gave me some time to put a new version of raylib. It's been **9 months since last release** and last November raylib become 7 years old... I was not able to release this new version back then but here it is. Many changes and improvements have happened in those months and, even, last August, raylib was awarded with an [Epic Megagrant](https://www.unrealengine.com/en-US/blog/epic-megagrants-fall-2020-update)! Bindings list kept growing to [+50 programming languages](BINDINGS.md) and some new platforms have been supported. Let's see this new version details:

First, some general numbers of this new update:

 - **+650** commits since previous RELEASE
 - **+30** functions ADDED (for a TOTAL of **475**!)
 - **+90** functions REVIEWED/REDESIGNED
 - **+30** contributors (for a TOTAL of **170**!)
 - **+8** new examples (for a TOTAL of **+120**!)

Here the list with some highlights for `raylib 3.5`.

 - NEW **Platform** supported: **Raspberry Pi 4 native mode** (no X11 windows) through [DRM](https://en.wikipedia.org/wiki/Direct_Rendering_Manager) subsystem and GBM API. Actually this is a really interesting improvement because it opens the door to raylib to support other embedded platforms (Odroid, GameShell, NanoPi...). Also worth mentioning the un-official homebrew ports of raylib for [PS4](https://github.com/orbisdev/orbisdev-orbisGl2) and [PSVita](https://github.com/psp2dev/raylib4Vita).

 - NEW **configuration options** exposed: For custom raylib builds, `config.h` now exposes **more than 150 flags and defines** to build raylib with only the desired features, for example, it allows to build a minimal raylib library in just some KB removing all external data filetypes supported, very useful to generate **small executables or embedded devices**.

 - NEW **automatic GIF recording** feature: Actually, automatic GIF recording (**CTRL+F12**) for any raylib application has been available for some versions but this feature was really slow and low-performant using an old gif library with many file accesses. It has been replaced by a **high-performant alternative** (`msf_gif.h`) that operates directly on memory... and actually works very well! Try it out!

 - NEW **RenderBatch** system: `rlgl` module has been redesigned to support custom **render batches** to allow grouping draw calls as desired, previous implementation just had one default render batch. This feature has not been exposed to raylib API yet but it can be used by advanced users dealing with `rlgl` directly. For example, multiple `RenderBatch` can be created for 2D sprites and 3D geometry independently.

 - NEW **Framebuffer** system: `rlgl` module now exposes an API for custom **Framebuffer attachments** (including cubemaps!). raylib `RenderTexture` is a basic use-case, just allowing color and depth textures, but this new API allows the creation of more advanced Framebuffers with multiple attachments, like the **G-Buffers**. `GenTexture*()` functions have been redesigned to use this new API.

 - Improved **software rendering**: raylib `Image*()` API is intended for software rendering, for those cases when **no GPU or no Window is available**. Those functions operate directly with **multi-format** pixel data on RAM and they have been completely redesigned to be way faster, specially for small resolutions and retro-gaming. Low-end embedded devices like **microcontrollers with custom displays** could benefit of this raylib functionality!

 - File **loading from memory**: Multiple functions have been redesigned to load data from memory buffers **instead of directly accessing the files**, now all raylib file loading/saving goes through a couple of functions that load data into memory. This feature allows **custom virtual-file-systems** and it gives more control to the user to access data already loaded in memory (i.e. images, fonts, sounds...).

 - NEW **Window states** management system: raylib `core` module has been redesigned to support Window **state check and setup more easily** and also **before/after Window initialization**, `SetConfigFlags()` has been reviewed and `SetWindowState()` has been added to control Window minification, maximization, hiding, focusing, topmost and more.

 - NEW **GitHub Actions** CI/CD system: Previous CI implementation has been reviewed and improved a lot to support **multiple build configurations** (platforms, compilers, static/shared build) and also an **automatic deploy system** has been implemented to automatically attach the different generated artifacts to every new release. As the system seems to work very good, previous CI platforms (AppVeyor/TravisCI) have been removed.

A part of those changes, many new functions have been added, some redundant functions removed and many functions have been reviewed for consistency with the full API (function name, parameters name and order, code formatting...). Again, this release represents is a **great improvement for raylib and marks the way forward** for the library. Make sure to check [CHANGELOG](CHANGELOG) for details! Hope you enjoy it!

Happy holidays! :)

notes on raylib 3.7
-------------------

April 2021, it's been about 4 months since the last raylib release and here is already a new one, this time with a bunch of internal redesigns and improvements. Surprisingly, on April 8th I was awarded for a second time with the [Google Open Source Peer Bonus Award](https://opensource.googleblog.com/2021/04/announcing-first-group-of-google-open-source-peer-bonus-winners.html) for my contribution to open source world with raylib and it seems the library is getting some traction, what a better moment for a new release? Let's see what can be found in this new version:

Let's start with some numbers:

 - **+100** closed issues (for a TOTAL of **+900**!)
 - **+400** commits since previous RELEASE
 - **+50** functions ADDED (**+30** of them to rlgl API)
 - **+30** functions REVIEWED/REDESIGNED
 - **+40** new contributors (for a TOTAL of **+210**!)

Highlights for `raylib 3.7`:

 - **REDESIGNED: `rlgl` module for greater abstraction level**. This suppose an **important change in raylib architecture**, now `rlgl` functionality is self-contained in the module and used by higher-level layers (specially by `core` module), those upper layers are the ones that expose functionality to the main API when required, for example the `Shaders`, `Mesh` and `Materials` functionality. Multiple `rlgl` functions have been renamed for consistency, in this case, following the `rl*()` prefix convention. Functions have also been reorganized internally by categories and `GenTexture*()` functions have been removed from the library and moved to [`models_material_pbr`](https://github.com/raysan5/raylib/blob/master/examples/models/models_material_pbr.c) example.

 - **REDESIGNED: VR simulator and stereo rendering mechanism**. A **brand new API** has been added, more comprehensive and better integrated with raylib, the **new stereo rendering** can be combined with `RenderTexture` and `Shader` API allowing the user to **manage fbo and distortion shader directly**. Also, the new rendering mechanism supports **instancing on stereo rendering**! Check the updated [`core_vr_simulator`](https://github.com/raysan5/raylib/blob/master/examples/core/core_vr_simulator.c) example for reference!

 - **ADDED: New file access callbacks system**. Several new callback functions have been added to the API to allow custom file loaders. A [nice example](https://github.com/RobLoach/raylib-physfs) it's the **raylib integration with a virtual file system** [PhysFS](https://icculus.org/physfs/).

 - **ADDED: glTF animations support**. glTF is the preferred models file format to be used with raylib and along the addition of a models animation API on latest raylib versions, now animations support for glTF format has come to raylib, thanks for this great contribution to [Hristo Stamenov](@object71)

 - **ADDED: Music streaming support from memory**. raylib has been adding the `Load*FromMemory()` option to all its supported file formats but **music streaming** was not supported yet... until now. Thanks to this great contribution by [Agnis "NeZvērs" Aldiņš](@nezvers), now raylib supports music streaming from memory data for all supported file formats: WAV, OGG, MP3, FLAC, XM and MOD.

 - **RENAMED: enums values for consistency**. Most raylib enums names and values names have been renamed for consistency, now all value names start with the type of data they represent. It increases clarity and readability when using those values and also **improves overall library consistency**.

Besides those key changes, many functions have been reviewed with improvements and bug fixes, many of them contributed by the community! Thanks! And again, this release sets a **new milestone for raylib library**. Make sure to check [CHANGELOG](CHANGELOG) for detailed list of changes! Hope you enjoy this new raylib installment!

Happy **gamedev/tools/graphics** programming! :)

notes on raylib 4.0 - 8th Anniversary Edition
---------------------------------------------

It's been about 6 months since last raylib release and it's been **8 years since I started with this project**, what an adventure! It's time for a new release: `raylib 4.0`, **the biggest release ever** and an inflection point for the library. Many hours have been put in this release to make it special, **many library details have been polished**: syntax, naming conventions, code comments, functions descriptions, log outputs... Almost all the issues have been closed (only 3 remain open at the moment of this writing) and some amazing new features have been added. I expect this **`raylib 4.0`** to be a long-term version (LTS), stable and complete enough for any new graphic/game/tool application development.

Let's start with some numbers:

 - **+130** closed issues (for a TOTAL of **+1030**!)
 - **+550** commits since previous RELEASE
 - **+20** functions ADDED to raylib API
 - **+60** functions ADDED to rlgl API
 - **+40** functions RENAMED/REVIEWED/REDESIGNED
 - **+60** new contributors (for a TOTAL of **+275**!)

Highlights for `raylib 4.0`:

 - **Naming consistency and coherency**: `raylib` API has been completely reviewed to be consistent on naming conventions for data structures and functions, comments and descriptions have been reviewed, also the syntax of many symbols for consistency; some functions and structs have been renamed (i.e. `struct CharInfo` to `struct GlyphInfo`). Output log messages have been also improved to show more info to the users. Several articles have been written in this process: [raylib_syntax analysis](https://github.com/raysan5/raylib/wiki/raylib-syntax-analysis) and [raylib API usage analysis](https://gist.github.com/raysan5/7c0c9fff1b6c19af24bb4a51b7383f1e). In general, a big polishment of the library to make it more consistent and coherent.

 - **Event Automation System**: This new _experimental_ feature has been added for future usage, it allows to **record input events and re-play them automatically**. This feature could be very useful to automatize examples testing but also for tutorials with assisted game playing, in-game cinematics, speedruns, AI playing and more! Note this feature is still experimental.

 - **Custom game-loop control**: As requested by some advanced users, **the game-loop control can be exposed** compiling raylib with the config flag: `SUPPORT_CUSTOM_FRAME_CONTROL`. It's intended for advanced users that want to control the events polling and also the timing mechanisms of their games.

 - [**`rlgl 4.0`**](https://github.com/raysan5/raylib/blob/master/src/rlgl.h): This module has been completely **decoupled from platform layer** and raylib, now `rlgl` single-file header-only library only depends on the multiple OpenGL backends supported, even the dependency on `raymath` has been removed. Additionally, **support for OpenGL 4.3** has been added, supporting compute shaders and Shader Storage Buffer Objects (SSBO). Now `rlgl` can be used as a complete standalone portable library to wrap several OpenGL version and providing **a simple and easy-to-use pseudo-OpenGL immediate-mode API**.

 - [**`raymath 1.5`**](https://github.com/raysan5/raylib/blob/master/src/raymath.h): This module has been reviewed and some new conventions have been adopted to make it **more portable and self-contained**:
   - Functions are self-contained, no function use other raymath function inside, required code is directly re-implemented
   - Functions input parameters are always received by value
   - Functions use always a "result" variable for return
   - Angles are always in radians (`DEG2RAD`/`RAD2DEG` macros provided for convenience)

 - [**`raygui 3.0`**](https://github.com/raysan5/raygui): The **official raylib immediate-mode gui library** (included in `raylib/src/extras`) has been updated to a new version, embedding the icons collection and adding mulstiple improvements. It has been simplified and constrained for a better focus on its task: provide a simple and easy-to-use immediate-mode-gui library for small tools development.

 - [**`raylib_parser`**](https://github.com/raysan5/raylib/tree/master/parser): Added **new tool to parse `raylib.h`** and tokenize its enums, structs and functions, extracting all required info (name, params, descriptions...) into custom output formats (TXT, XML, JSON...) for further processing. This tool is specially useful to **automatize bindings generation**. Hopefully, this tool will make life easier to binding creators to update their bindings for raylib 4.0 or adding new ones!

 - **Zig and Odin official support for raylib**: Those two new amazing programming languages are officially supporting raylib, `Zig` lists raylib as an [official example for C interoperatibility](https://ziglang.org/learn/samples/#c-interoperability) and Odin [officially supports raylib as a vendor library](https://github.com/odin-lang/Odin/tree/master/vendor/raylib). Both languages also have several bingings to raylib. Additionally, Zig build system supported has been added to compile raylib library and examples.

Those are some of the key features for this new release but actually there is way more! **Support for `VOX` ([MagikaVoxel](https://ephtracy.github.io/)) 3d model format** has been added, **new [raylib_game_template](https://github.com/raysan5/raylib-game-template)** repo shared, **new `EncodeDataBase64()` and `DecodeDataBase64()` functions** added, **improved HiDPI support**, new `DrawTextPro()` with support for text rotations, completely **reviewed `glTF` models loading**, added **`SeekMusicStream()` for music seeking**, many new examples and +20 examples reviewed... **hundreds of improvements and bug fixes**! Make sure to check [CHANGELOG](CHANGELOG) for a detailed list of changes!

Undoubtedly, **this is the best raylib ever**. Enjoy gamedev/tools/graphics programming! :)

notes on raylib 4.2
-------------------

**New raylib release!** Nine months after latest raylib, here is a new version. It was supposed to be just a small update but, actually, it's a huge update with lots of changes a improvements. It has been possible thanks to the many contributors that has helped with issues and improvements, it's the **update with more contributors to date** and that's amazing!

Some numbers to start with:

 - **+200** closed issues (for a TOTAL of **1230**!)
 - **+540** commits since previous RELEASE (for a TOTAL of **+6000**!)
 - **+20** functions ADDED to raylib API (for a TOTAL of **502**!)
 - **+60** functions REVIEWED/REDESIGNED
 - **+70** new contributors (for a TOTAL of **+360**!)

Highlights for `raylib 4.2`:

 - **raylib extra libraries cleanup**: raylib has been on diet and all the _extra_ libraries included on previous releases have been removed from raylib. Now raylib only includes the original **7** raylib modules: `rcore`, `rlgl`, `rshapes`, `rtextures`, `rtext`, `rmodels` and `raudio`. But no worries, _extra_ libraries have not been deleted, they have been moved to their own repos for better maintainability and more focus on its functionality. The libraries moved out from raylib repo are: [`raygui`](https://github.com/raysan5/raygui), [`physac`](https://github.com/raysan5/physac), [`rmem`](https://github.com/raylib-extras/rmem), [`reasings`](https://github.com/raylib-extras/reasings) and [`raudio`](https://github.com/raysan5/raudio) (standalone mode). On that same line, a new **amazing GitHub group:** [`raylib-extras`](https://github.com/raylib-extras) has been created by @JeffM2501 to contain raylib extra libraries as well as other raylib add-ons provided by the community. Jeff has done an amazing work on that line, providing multiple libraries and examples for raylib, like [custom first-person and third person camera systems](https://github.com/raylib-extras/extras-c/tree/main/cameras), [Dear ImGui raylib integration](https://github.com/raylib-extras/rlImGui), [multiple specific examples](https://github.com/raylib-extras/examples-c) and even a complete [RPG Game Example](https://github.com/raylib-extras/RPGExample)! Great work Jeff! :D

 - **raylib examples review**: The +120 raylib examples have been reviewed to add clearer information about when the were first created (raylib version used) and when they were updated for the last time. But the greatest improvement for users has been the **addition of an estimated difficulty level** for every example, [web has been updated accordingly](https://www.raylib.com/examples.html) to reflect those difficulty levels. Now examples are classified with **1 to 4 stars** depending on difficulty to help users with their learning process. Personally, I think this "small" addition could be a game-changer to better guide new users on the library adoption! Additionally, this new raylib release includes 7 new examples; the most interesting one: [`text_codepoints_loading`](https://www.raylib.com/examples/text/loader.html?name=text_codepoints_loading) that illustrates how to load and draw custom codepoints from a font file, very useful for Asian languages.

 - [**`rres 1.0`**](https://github.com/raysan5/rres): New `rres` **resources packaging file-format**, including a [`rres-raylib`](https://github.com/raysan5/rres/blob/master/src/rres-raylib.h) library implementation and [`rrespacker`](https://raylibtech.itch.io/rrespacker) tool. `rres` file format has been [under development for +8 years](https://github.com/raysan5/rres#design-history) and it was originally created to be part of raylib. It was highly inspired by _XNA XNB_ resources file format but design has changed a lot along the years. This first release of the format specs is engine-agnostic and has been designed to be portable to any engine, including lots of professional features like data processing, compression and encryption.

 - [**`raygui 3.2`**](https://github.com/raysan5/raygui): The **official raylib immediate-mode gui library** designed for tools development has been updated to a new version aligned with raylib 4.2. Multiple controls have been reviewed for library consistency, now all controls follow a similar function signature. It has been battle-tested with the development of +8 published tools in the last months. The tools can be seen and used for free in the [raylib technologies tools page](https://raylibtech.itch.io/). Worth mentioning that several of those **tools have been open sourced** for anyone to use, compile, contribute or learn how the code works.

 - [**`raylib_parser`**](https://github.com/raysan5/raylib/tree/master/parser): Multiple contributors **using the tool to automatize bindings creation** have contributed with improvements of this **tool to parse `raylib.h`** (and other raylib-style headers) to tokenize its enums, structs and functions. Processed data can be exported to custom file formats (i.e XML, JSON, LUA) for bindings generation or even docs generation if required.

 - **New file system API**: Current API has been redesigned to be more comprehensive and better aligned with raylib naming conventions, two new functions are provided `LoadDirectoryFiles()`/`LoadDirectoryFilesEx()` to load a `FilePathList` for provided path, supporting extension filtering and recursive directory scan. `LoadDroppedFiles()` has been renamed to better reflect its internal functionality. Now, all raylib functions that start with `Load*()` allocate memory internally and a equivalent `Unload*()` function is defined to take care of that memory internally when not required any more!

 - **New audio stream processors API** (_experimental_): Now real-time audio stream data processors can be added using callbacks to played Music. It allows users to create custom effects for audio like delays of low-pass-filtering (example provided). The new API uses a callback system and it's still _ highly experimental_, it differs from the usual level of complexity that provides raylib and it is intended for advanced users. It could change in the future but, actually, `raudio` module is in the spotlight for future updates; [miniaudio](https://github.com/mackron/miniaudio) implements a new higher-level API that can be useful in the future for raylib.

As always, there are more improvements than the key features listed, make sure to check raylib [CHANGELOG](CHANGELOG) for the detailed list of changes; for this release a `WARNING` flag has been added to all the changes that could affect bindings or productivity code. **raylib keeps improving one more version** and a special focus on maintainability has been put on the library for the future. Specific/advance functionality will be provided through **raylib-extras** repos and raylib main repo devlelopment will be focused on what made raylib popular: being a simple and easy-to-use library to **enjoy videogames programming**.

**Enjoy gamedev/tools/graphics programming!** :)

notes on raylib 4.5
-------------------

It's been **7 months** since latest raylib release. As usual, **many parts of the library have been reviewed and improved** along those months. Many issues have been closed, staying under 10 open issues at the moment of this writting and also many PRs from contributors have been received, reviewed and merged into raylib library. Some new functions have been added and some others have been removed to improve library coherence and avoid moving too high level, giving the users the tools to implement advance functionality themselfs over raylib. Again, this is a big release with a considerable amount of changes and improvements. Here is a small summary highlighting this new **rayib 4.5**.

Some numbers for this release:

 - **+100** closed issues (for a TOTAL of **+1340**!)
 - **+350** commits since previous RELEASE (for a TOTAL of **+6350**!)
 - **+25** functions ADDED to raylib API (for a TOTAL of **516**!)
 - **+40** functions REVIEWED/REDESIGNED
 - **+40** new contributors (for a TOTAL of **405**!)

Highlights for `raylib 4.5`:

 - **`NEW` Improved ANGLE support on Desktop platforms**: Support for OpenGL ES 2.0 on Desktop platforms (Windows, Linux, macOS) has been reviewed by @wtnbgo GitHub user. Now raylib can be compiled on desktop for OpenGL ES 2.0 and linked against [`ANGLE`](https://github.com/google/angle). This _small_ addition open the door to building raylib for all **ANGLE supported backends: Direct3D 11, Vulkan and Metal**. Please note that this new feature is still experimental and requires further testing!

 - **`NEW` Camera module**: A brand new implementation from scratch for `rcamera` module, contributed by @Crydsch GitHub user! **New camera system is simpler, more flexible, more granular and more extendable**. Specific camera math transformations (movement/rotation) have been moved to individual functions, exposing them to users if required. Global state has been removed from the module and standalone usage has been greatly improved; now `rcamera.h` single-file header-only library can be used externally, independently of raylib. A new `UpdateCameraPro()` function has been added to address input-dependency of `UpdateCamera()`, now advanced users have **full control over camera inputs and movement/rotation speeds**!

 - **`NEW` Support for M3D models and M3D/GLTF animations**: 3d models animations support has been a limited aspect of raylib for long time, some versions ago IQM animations were supported but raylib 4.5 also adds support for the brand new [M3D file format](https://bztsrc.gitlab.io/model3d/), including animations and the long expected support for **GLTF animations**! The new M3D file format is **simple, portable, feature complete, extensible and open source**. It also provides a complete set of tools to export/visualize M3D models from/to Blender! Now raylib supports up to **3 model file-formats with animations**: `IQM`, `GLTF` and `M3D`.

 - **`NEW` Support QOA audio format (import/export)**: Just a couple of months ago the new [QOA file format](https://qoaformat.org/) was published, a very simple, portable and open source quite-ok-audio file format. raylib already supports it, added to `raudio` module and including audio loading from file, loading from memory, streaming from file, streaming from memory and **exporting to QOA** audio format. **Because simplicity really matters to raylib!**

 - **`NEW` Module for compressed textures loading**: [`rl_gputex`](https://github.com/raysan5/raylib/blob/master/src/external/rl_gputex.h), a portable single-file header-only small library to load compressed texture file-formats (DDS, PKM, KTX, PVR, ASTC). Provided functionality is not new to raylib but it was part of the raylib `rtextures` module, now it has been moved into a separate self-contained library, **improving portability**. Note that this module is only intended to **load compressed data from files, ready to be uploaded to GPU**, no compression/decompression functionality is provided. This change is a first step towards a better modularization of raylib library.

 - **Reviewed `rlgl` module for automatic limits checking**: Again, [`rlgl`](https://github.com/raysan5/raylib/blob/master/src/rlgl.h) has been reviewed to simplify usage. Now users do not need to worry about reaching the internal render-batch limits when they send their triangles to draw 2d/3d, `rlgl` manages it automatically! This change allows a **great simplification for other modules** like `rshapes`, `rtextures` and `rmodels` that do not need to worry about bufffer overflows and can just define as many vertex as desired!

 - **Reviewed `rshapes` module to minimize the rlgl dependency**: Now `rshapes` 2d shapes drawing functions **only depend on 6 low-level functions**: `rlBegin()`, `rlEnd()`, `rlVertex3f()`, `rlTexCoord2f()`, `rlNormal3f()`, `rlSetTexture()`. With only those pseudo-OpenGl 1.1 minimal functionality, everything can be drawn! This improvement converts `rshapes` module in a **self-contained, portable shapes-drawing library that can be used independently of raylib**, as far as entry points for those 6 functions are provided by the user. It even allows to be used for software rendering, with the proper backend!

 - **Added data structures validation functions**: Multiple functions have been added by @RobLoach GitHub user to ease the validation of raylib data structures: `IsImageReady()`, `IsTextureReady()`, `IsSoundReady()`... Now users have a simple mechanism to **make sure data has been correctly loaded**, instead of checking internal structure values by themselves.

As usual, those are only some highlights but there is much more! New image generators, new color transformation functionality, improved blending support for color/alpha, etc... Make sure to check raylib [CHANGELOG]([CHANGELOG](https://github.com/raysan5/raylib/blob/master/CHANGELOG)) for a detailed list of changes! Please, note that all breaking changes have been flagged with a `WARNING` in the CHANGELOG, specially useful for binding creators!

**raylib keeps improving one more version** with a special focus on maintainability and sustainability. Always working towards making the library more **simple and easy-to-use**.

Let's keep **enjoying games/tools/graphics programming!** :)

notes on raylib 5.0
-------------------

It's been **7 months** since latest raylib release and **10 years** since raylib 1.0 was officially released... what an adventure! In the last 10 years raylib has improved a lot, new functions have been added, many new features and improvements implemented, up to **500 contributors** have helped to shape the library as it is today. `raylib 5.0` is the final result of all this incredible amount of work and dedication. Here is the summary with the key features and additions of this NEW major version of raylib.

Some numbers for this release:

 - **+200** closed issues (for a TOTAL of **+1540**!)
 - **+550** commits since previous RELEASE (for a TOTAL of **+6950**!)
 - **+35** functions ADDED to raylib API (for a TOTAL of **552**!)
 - **+60** functions REVIEWED/REDESIGNED
 - **+80** new contributors (for a TOTAL of **+500**!)

Highlights for `raylib 5.0`:

 - **`rcore` module platform-split**: Probably the biggest raylib redesign in the last 10 years. raylib started as a library targeting 3 desktop platforms: `Windows`, `Linux` and `macOS` (thanks to `GLFW` underlying library) but with the years support for several new platforms has been added (`Android`, `Web`, `Rapsberry Pi`, `RPI native`...); lot of the platform code was shared so the logic was all together on `rcore.c` module, separated by compilation flags. This approach was very handy but also made it very difficult to support new platforms and specially painful for contributors not familiar with the module, navigating +8000 lines of code in a single file. A big redesign was really needed but the amount of work required was humungous and quite scary for a solo-developer like me, moreover considering that everything was working and the chances to break things were really high. Fortunately, some contributors were ready for the task (@ubkp, @michaelfiber, @Bigfoot71) and thanks to their initiative and super-hard work, the `rcore` [platform split](https://github.com/raysan5/raylib/blob/master/src/platforms) has been possible! This new raylib architecture greatly improves the platforms maintenance but also greatly simplifies the addition of new platforms. A [`platforms/rcore_template.c`](https://github.com/raysan5/raylib/blob/master/src/platforms/rcore_template.c) file is provided with the required structure and functions to be filled for the addition of new platforms, actually it has been simplified to mostly filling some pre-defined functions: `InitPlatform()`, `ClosePlatform`, `PollInputEvents`... Undoubtedly, **this redesign opens the doors to a new era for raylib**, letting the users to plug new platforms as desired.
 
 - **`NEW` Platform backend supported: SDL**: Thanks to the new `rcore` platform-split, the addition of new platforms/backends to raylib has been greatly simplified. As a proof of concept, [`SDL2`](https://libsdl.org/) platform backend has been added to raylib as an alternative for `GLFW` library for desktop builds: [`platforms/rcore_desktop_sdl`](https://github.com/raysan5/raylib/blob/master/src/platforms/rcore_desktop_sdl.c). Lot of work has been put to provide exactly the same features as the other platforms and carefully test the new implementation. Now `SDL2` fans can use this new backend, just providing the required include libraries on compilation and linkage (not included in raylib, like `GLFW`). `SDL` backend support also **eases the process of supporting a wider range of platforms** that already support `SDL`.

 - **`NEW` Platform backend supported: Nintendo Switch (closed source)**: The addition of the `SDL` backend was quite a challenge but to really verify the robustness and ease of the new platform plugin system, adding support for a console was a more demanding adventure. Surprisingly, only two days of work were required to add support for `Nintendo Switch` to raylib! Implementation result showed an outstanding level of simplicity, with a **self-contained module** (`rcore_swith.cpp`) supporting graphics and inputs. Unfortunately this module can not be open-sourced due to licensing restrictions.

 - **`NEW` Splines drawing and evaluation API**: A complete set of functions has been added to [draw](https://github.com/raysan5/raylib/blob/master/src/raylib.h#L1258) and [evaluate](https://github.com/raysan5/raylib/blob/master/src/raylib.h#L1270) different types of splines: `Linear`, `Basis`, `Catmull-Rom`, `Quadratic Bezier` and `Cubic Bezier`. Splines are extremely useful for game development (describe paths, control NPC movement...) but they can also be very useful on tools development (node-conections, elements-movement, 3d modelling, animations...). This was the missing feature on the raylib [`rshapes`](https://github.com/raysan5/raylib/blob/master/src/rshapes.h) module to make it complete! Note that `rshapes` module can also be used independently of raylib just providing the **only 6 functions required for vertex definition and drawing**.
 
 - **`NEW` Pseudo-random numbers generator: rprand**: After several years of users asking for this missing piece, a brand new pseudo-random generator module has been added to raylib. [`rprand`](https://github.com/raysan5/raylib/blob/master/src/external/rprand.h) implements the `Xoshiro128**` algorithm combined with `SplitMix64`, specially suited for **fast software pseudo-random numbers generation**. The module also implies some useful functions to generate non-repetitive random numbers sequences, functionality exposed by raylib. usage of this module can be controlled by a compilation flag, in case the default libc `rand()` function was preferred.

 - **`NEW` Automation Events System API**: This new system was first added in `raylib 4.0` as an experimental feature but it was a bit clumsy and there was no API exposed to users. For the new `raylib 5.0` the system has been redesigned and [proper API](https://github.com/raysan5/raylib/blob/master/src/raylib.h#L1135) added for the users. With this new events automation system, users can **record input events for later replay**, very useful feature for testing automation, tutorials generation, assisted game playing, in-game cinematics, speedruns saving or even AI assited game playing!

 - **`NEW` [`raygui 4.0`](https://github.com/raysan5/raygui)**: The **official raylib immediate-mode gui library** designed for tools development has been updated to a new version, aligned with raylib 5.0. This new version is a complete redesign of raygui to unify all controls structure and usage, now all controls have the same function signature!. `raygui` has been battle-tested with the development of +12 published tools in the last few years. The tools can be seen and used for free in the [raylib technologies tools page](https://raylibtech.itch.io/). Worth mentioning that several of those **tools have been open sourced** for anyone to use, compile, contribute or learn how the code works.

 - **`NEW` raylib web examples functionality**: Beside the addition of several new examples, the web examples functionality has been improved. Examples have been organized by [complexity level](https://www.raylib.com/examples.html), marked with one star for simple examples and up to 4 stars for more complex ones. A new option has been added to web to allow to **filter examples by function-name** usage, to ease the learning process when looking for an usage example of some function. Finally, **open-graph metadata** information has been added to all examples individual webpages, improving a the visuals and information when sharing those webpages on social networks, sharing the example screenshot and details.

As always, those are only some highlights of the new `raylib 5.0` but there is many more improvements! Support for 16-bit HDR images/textures, SVG loading and scaling support, new OpenGL ES 3.0 graphic backend, new image gradient generators, sound alias loading, improved 3d models loading, multiple optimizations, new bindings, CodeQL integration and much more! 
 
Make sure to check raylib [CHANGELOG]([CHANGELOG](https://github.com/raysan5/raylib/blob/master/CHANGELOG)) for a detailed list of changes!

Undoubtedly, this is the **biggest raylib update in 10 years**. Many new features and improvements with a special focus on maintainability and long-term sustainability. **Undoubtedly, this is the raylib of the future**.

**Enjoy programming!** :)

notes on raylib 5.5
-------------------

One year after raylib 5.0 release, arribes `raylib 5.5`, the next big revision of the library. It's been **11 years** since raylib 1.0 release and in all this time it has never stopped growing and improving. With an outstanding number of new contributors and improvements, it's, again, the biggest raylib release to date.

Some numbers for this release:

 - **+270** closed issues (for a TOTAL of **+1810**!)
 - **+800** commits since previous RELEASE (for a TOTAL of **+7770**!)
 - **+30** functions ADDED to raylib API (for a TOTAL of **580**!)
 - **+110** functions REVIEWED with fixes and improvements
 - **+140** new contributors (for a TOTAL of **+640**!)

Highlights for `raylib 5.5`:

 - **`NEW` raylib pre-configured Windows package**: The new raylib **portable and self-contained Windows package** for `raylib 5.5`, intended for nobel devs that start in programming world, comes with one big addition: support for **C code building for Web platform with one-single-mouse-click!** For the last 10 years, the pre-configured raylib Windows package allowed to edit simple C projects on Notepad++ and easely compile Windows executables with an automatic script; this new release adds the possibility to compile the same C projects for Web platform with a simple mouse click. This new addition **greatly simplifies C to WebAssembly project building for new users**. The `raylib Windows Installer` package can be downloaded for free from [raylib on itch.io](https://raysan5.itch.io/raylib).

 - **`NEW` raylib project creator tool**: A brand new tool developed to help raylib users to **setup new projects in a professional way**. `raylib project creator` generates a complete project structure with **multiple build systems ready-to-use** and **GitHub CI/CD actions pre-configured**. It only requires providing some C files and basic project parameters! The tools is [free and open-source](https://raysan5.itch.io/raylib-project-creator), and [it can be used online](https://raysan5.itch.io/raylib-project-creator)!.

 - **`NEW` Platform backend supported: RGFW**: Thanks to the `rcore` platform-split implemented in `raylib 5.0`, **adding new platforms backends has been greatly simplified**, new backends can be added using provided template, self-contained in a single C module, completely portable. A new platform backend has been added: [`RGFW`](https://github.com/raysan5/raylib/blob/master/src/platforms/rcore_desktop_rgfw.c). `RGFW` is a **new single-file header-only portable library** ([`RGFW.h`](https://github.com/ColleagueRiley/RGFW)) intended for platform-functionality management (windowing and inputs); in this case for **desktop platforms** (Windows, Linux, macOS) but also for **Web platform**. It adds a new alternative to the already existing `GLFW` and `SDL` platform backends.
 
 - **`NEW` Platform backend version supported: SDL3**: Previous `raylib 5.0` added support for `SDL2` library, and `raylib 5.5` not only improves SDL2 functionality, with several issues reviewed, but also adds support for the recently released big SDL update in years: [`SDL3`](https://wiki.libsdl.org/SDL3/FrontPage). Now users can **select at compile time the desired SDL version to use**, increasing the number of potential platforms supported in the future!
 
 - **`NEW` Retro-console platforms supported: Dreamcast, N64, PSP, PSVita, PS4**: Thanks to the platform-split on `raylib 5.0`, **supporting new platform backends is easier than ever!** Along the raylib `rlgl` module support for the  `OpenGL 1.1` graphics API, it opened the door to [**multiple homebrew retro-consoles backend implementations!**](https://github.com/raylib4Consoles) It's amazing to see raylib running on +20 year old consoles like [Dreamcast](https://github.com/raylib4Consoles/raylib4Dreamcast), [PSP](https://github.com/raylib4Consoles/raylib4Psp) or [PSVita](https://github.com/psp2dev/raylib4Vita), considering the hardware constraints of those platforms and proves **raylib outstanding versability!** Those additional platforms can be found in separate repositories and have been created by the amazing programmer Antonio Jose Ramos Marquez (@psxdev).
 
 - **`NEW` GPU Skinning support**: After lots of requests for this feature, it has been finally added to raylib thanks to the contributor Daniel Holden (@orangeduck), probably the developer that has further pushed models animations with raylib, developing two amazing tools to visualize and test animations: [GenoView](https://github.com/orangeduck/GenoView) and [BVHView](https://github.com/orangeduck/BVHView). Adding GPU skinning was a tricky feature, considering it had to be **available for all raylib supported platforms**, including limited ones like Raspberry Pi with OpenGL ES 2.0, where some advance OpenGL features are not available (UBO, SSBO, Transform Feedback) but a multi-platform solution was found to make it possible. A new example, [`models_gpu_skinning`](https://github.com/raysan5/raylib/blob/master/examples/models/models_gpu_skinning.c) has been added to illustrate this new functionality. As an extra, previous existing CPU animation system has been greatly improved, multiplying performance by a factor (simplifiying required maths).
 
 - **`NEW` [`raymath`](https://github.com/raysan5/raylib/blob/master/src/raymath.h) C++ operators**: After several requested for this feature, C++ math operators for `Vector2`, `Vector3`, `Vector4`, `Quaternion` and `Matrix` has been added to `raymath` as an extension to current implementation. Despite being only available for C++ because C does not support it, these operators **simplify C++ code when doing math operations**.

Beside those new big features, `raylib 5.5` comes with MANY other improvements: 

- Normals support on batching system
- Clipboard images reading support
- CRC32/MD5/SHA1 hash computation
- Gamepad vibration support
- Improved font loading (no GPU required) with BDF fonts support
- Time-based camera movement
- Improved GLTF animations loading

...and [much much more](https://github.com/raysan5/raylib/blob/master/CHANGELOG), including **many functions reviews and new functions added!**
 
Make sure to check raylib [CHANGELOG](https://github.com/raysan5/raylib/blob/master/CHANGELOG) for a detailed list of changes!

To end with, I want to **thank all the contributors (+640!**) that along the years have **greatly improved raylib** and pushed it further and better day after day. Thanks to all of them, raylib is the amazing library it is today.

Last but not least, I want to thank **raylib sponsors and all the raylib community** for their support and continuous engagement with the library, creating and sharing amazing raylib projects on a daily basis. **Thanks for making raylib a great platform to enjoy games/tools/graphic programming!**

**After 11 years of development, `raylib 5.5` is the best raylib ever.**

**Enjoy programming with raylib!** :)

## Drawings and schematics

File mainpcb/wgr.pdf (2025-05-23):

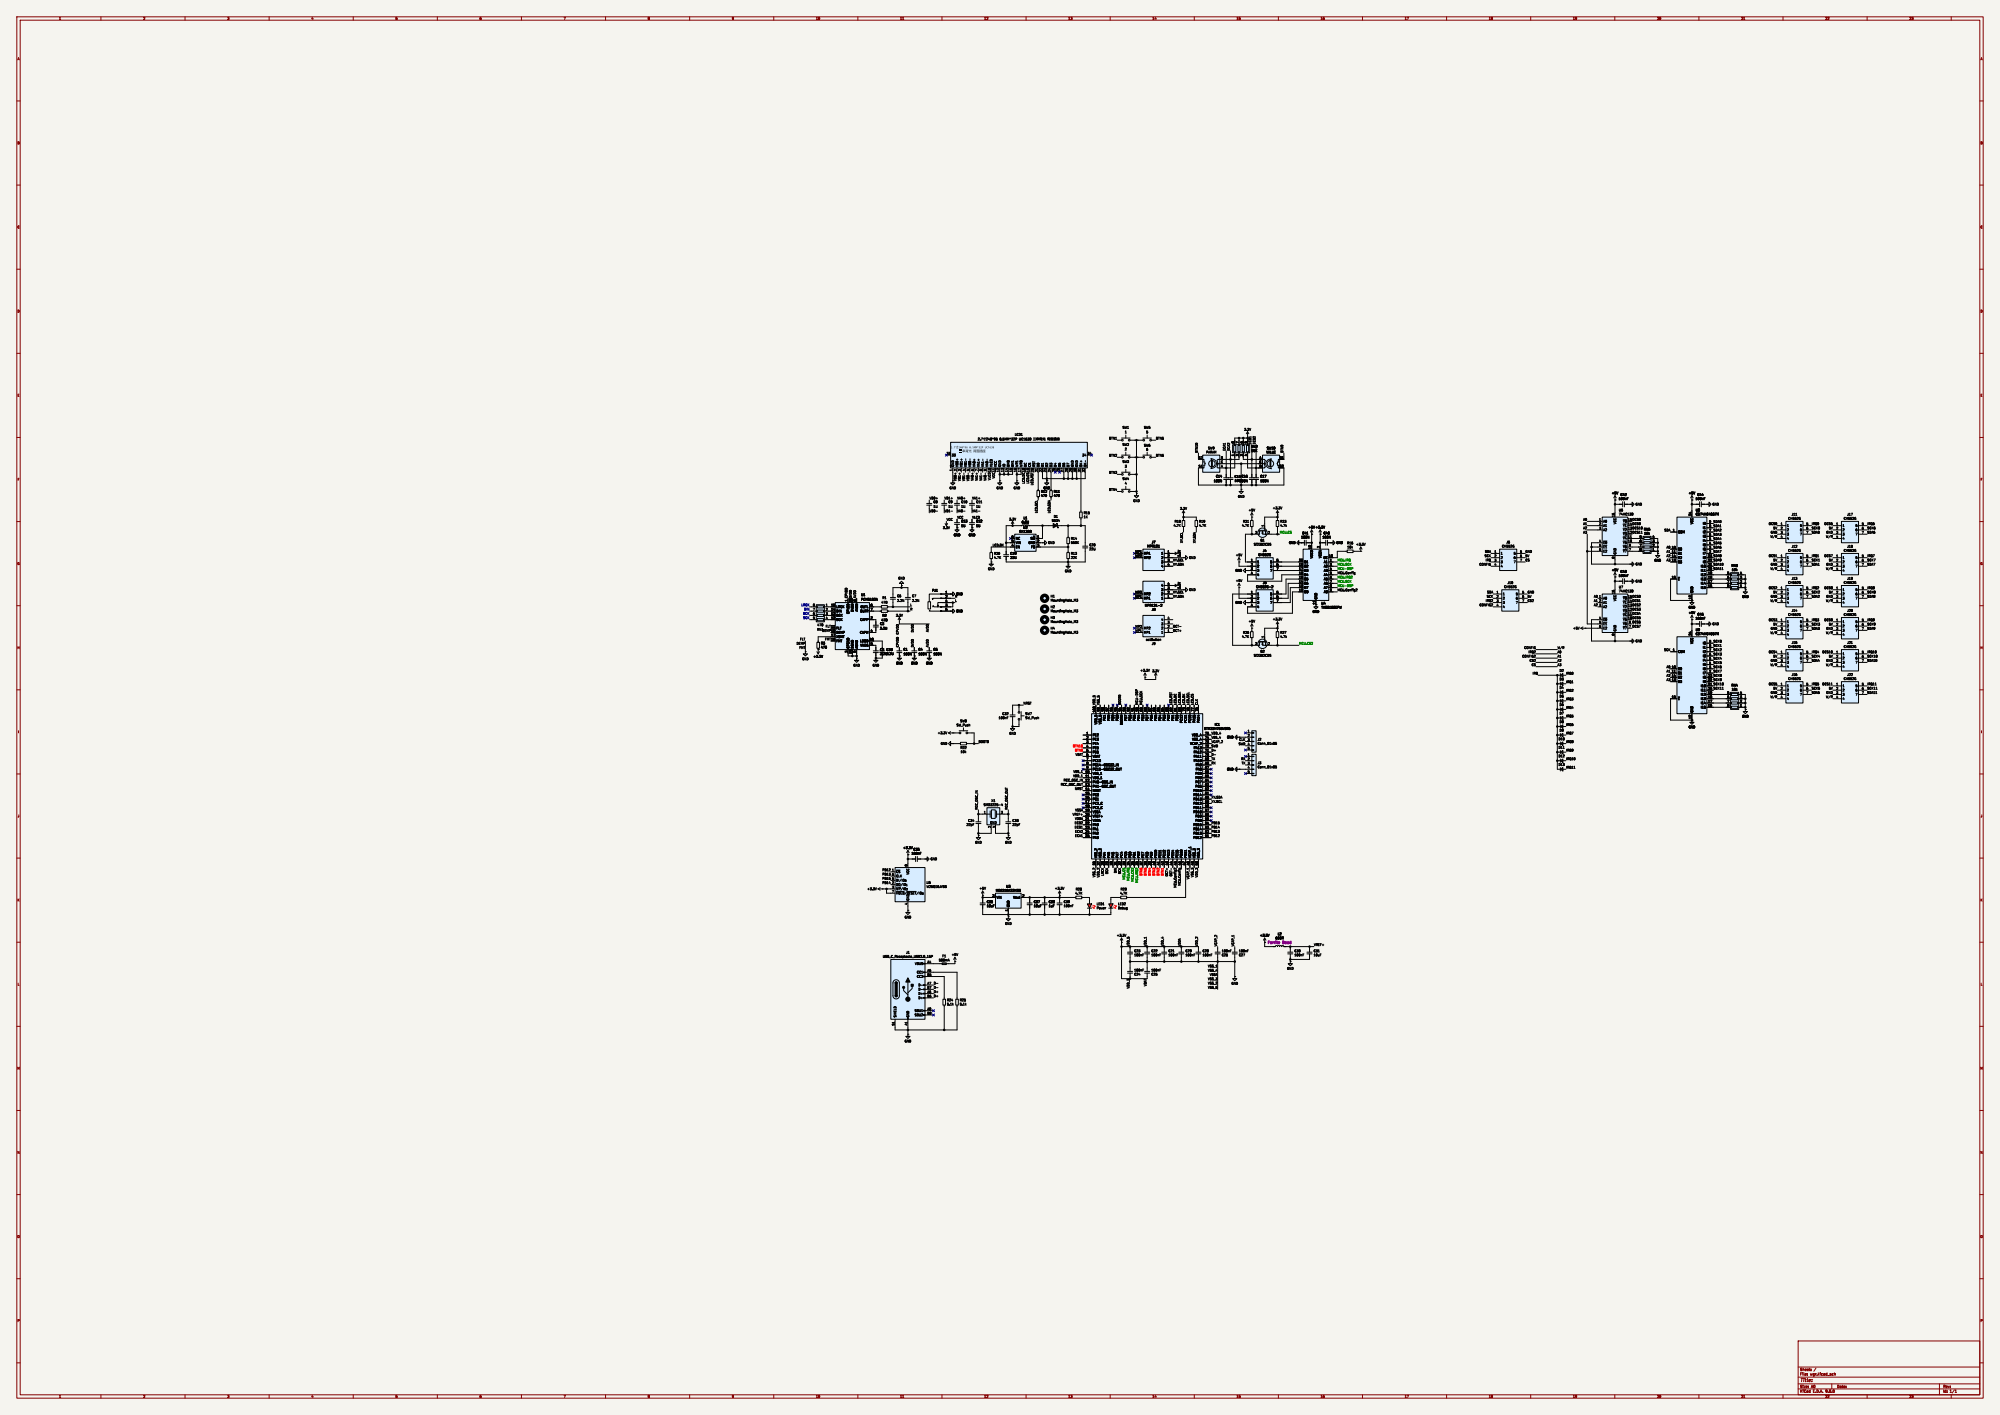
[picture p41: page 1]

7 VA1- 8 VA0- 9 VLCD 10 VCC 11 GND 12 ID 13 BM0 14 BM1 15 WR1 16 WR0 17 DC 18 CS 19 RST 20 D0 21 D1 22 D2 23 D3 24 D4 25 D5 26 D6 27 D7 28 GND 29 GND 30 BK+ 31 BK- 32

SDA CPVDD DVDD AVDD

Id: 1/1 Title: File: wgr.kicad_sch Sheet: /

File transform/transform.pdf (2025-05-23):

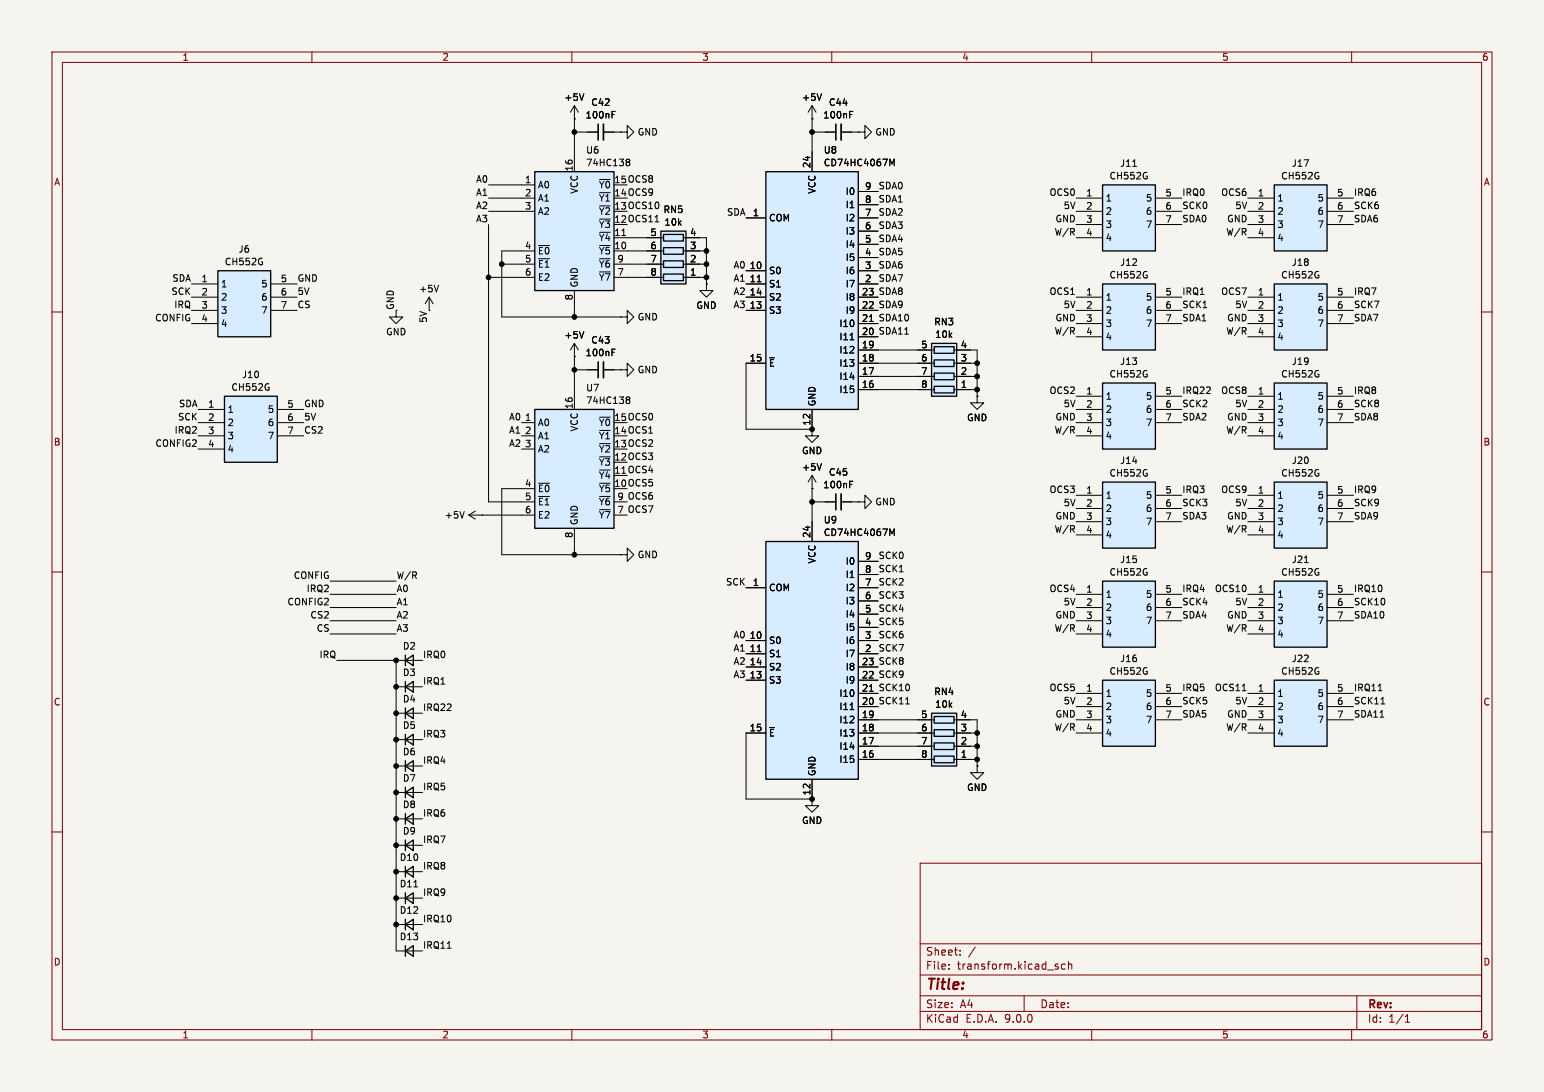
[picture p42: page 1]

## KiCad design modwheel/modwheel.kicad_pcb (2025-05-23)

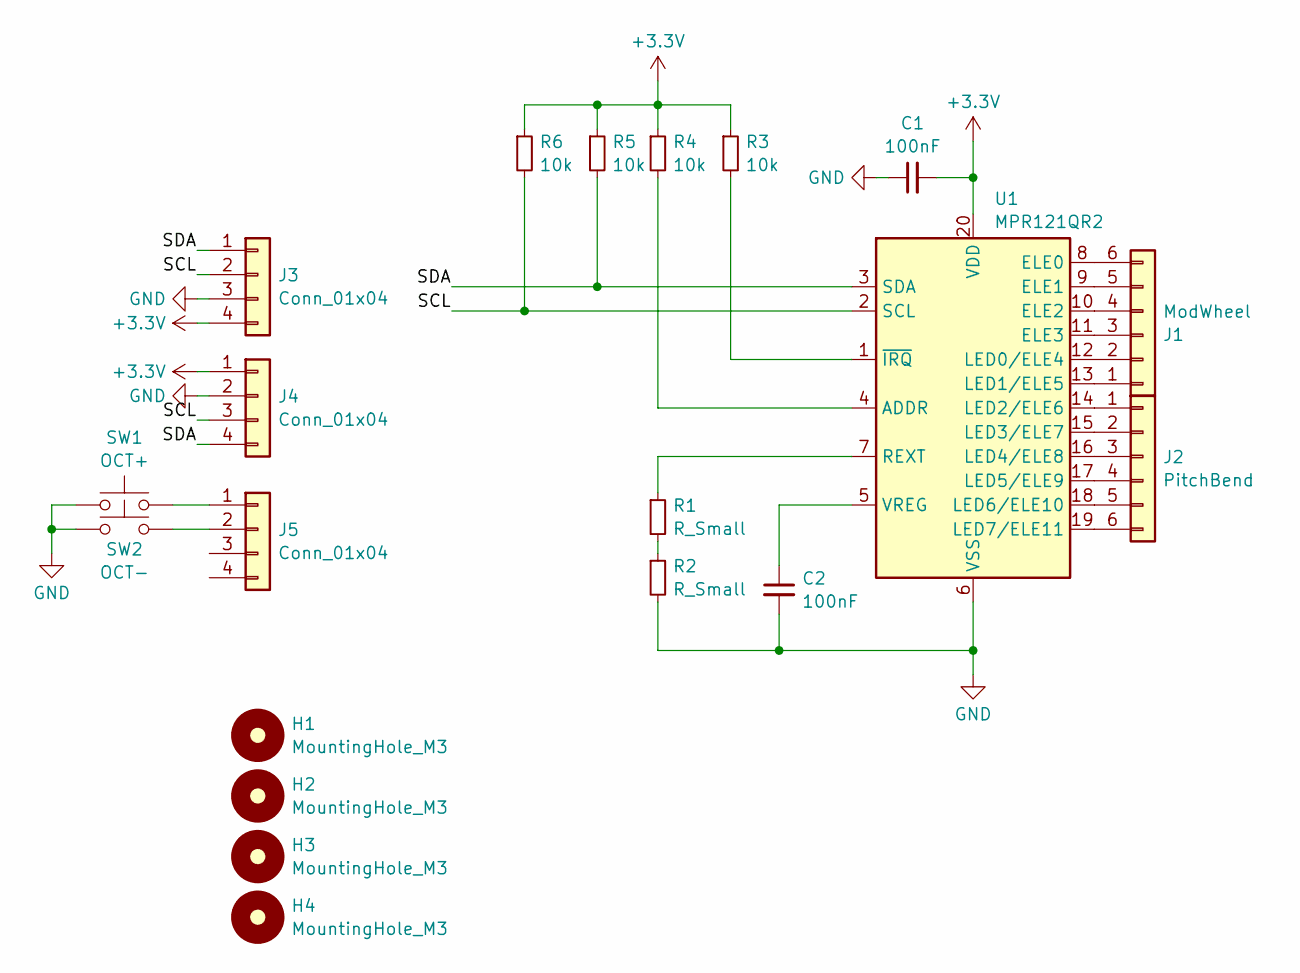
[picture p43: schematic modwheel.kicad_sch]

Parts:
C1, C2: 100nF; C_0603_1608Metric
H1, H2, H3, H4: MountingHole_M3; MountingHole_3.2mm_M3
J1: ModWheel; TouchSlider-6_50x10mm
J2: PitchBend; TouchSlider-6_50x10mm
J3, J4, J5: Conn_01x04; SM04BSRSSTB
R1, R2: R_Small; R_0603_1608Metric
R3, R4, R5, R6: 10k; R_0603_1608Metric
SW1: OCT+; KEY-SMD_2P-L6.0-W6.0-P6.00
SW2: OCT-; KEY-SMD_2P-L6.0-W6.0-P6.00
U1: MPR121QR2; UQFN-20_3x3mm_P0.4mm

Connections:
+3.3V: C1.2, J3.4, J4.1, R3.1, R4.1, R5.1, R6.1, U1.20 (VDD)
/SCL: J3.2, J4.3, R6.2, U1.2 (SCL)
/SDA: J3.1, J4.4, R5.2, U1.3 (SDA)
GND: C1.1, C2.2, J3.3, J4.2, R2.2, SW1.1, SW2.1, U1.6 (VSS)
unnamed: J1.1, U1.13 (LED1/ELE5)
unnamed: J1.2, U1.12 (LED0/ELE4)
unnamed: J1.3, U1.11 (ELE3)
unnamed: J1.4, U1.10 (ELE2)
unnamed: J1.5, U1.9 (ELE1)
unnamed: J1.6, U1.8 (ELE0)
unnamed: J2.1, U1.14 (LED2/ELE6)
unnamed: J2.2, U1.15 (LED3/ELE7)
unnamed: J2.3, U1.16 (LED4/ELE8)
unnamed: J2.4, U1.17 (LED5/ELE9)
unnamed: J2.5, U1.18 (LED6/ELE10)
unnamed: J2.6, U1.19 (LED7/ELE11)
unnamed: J5.1, SW1.2
unnamed: J5.2, SW2.2
unnamed: R1.2, R2.1
unnamed: R4.2, U1.4 (ADDR)
unnamed: R1.1, U1.7 (REXT)
unnamed: C2.1, U1.5 (VREG)
unnamed: R3.2, U1.1 (~IRQ)

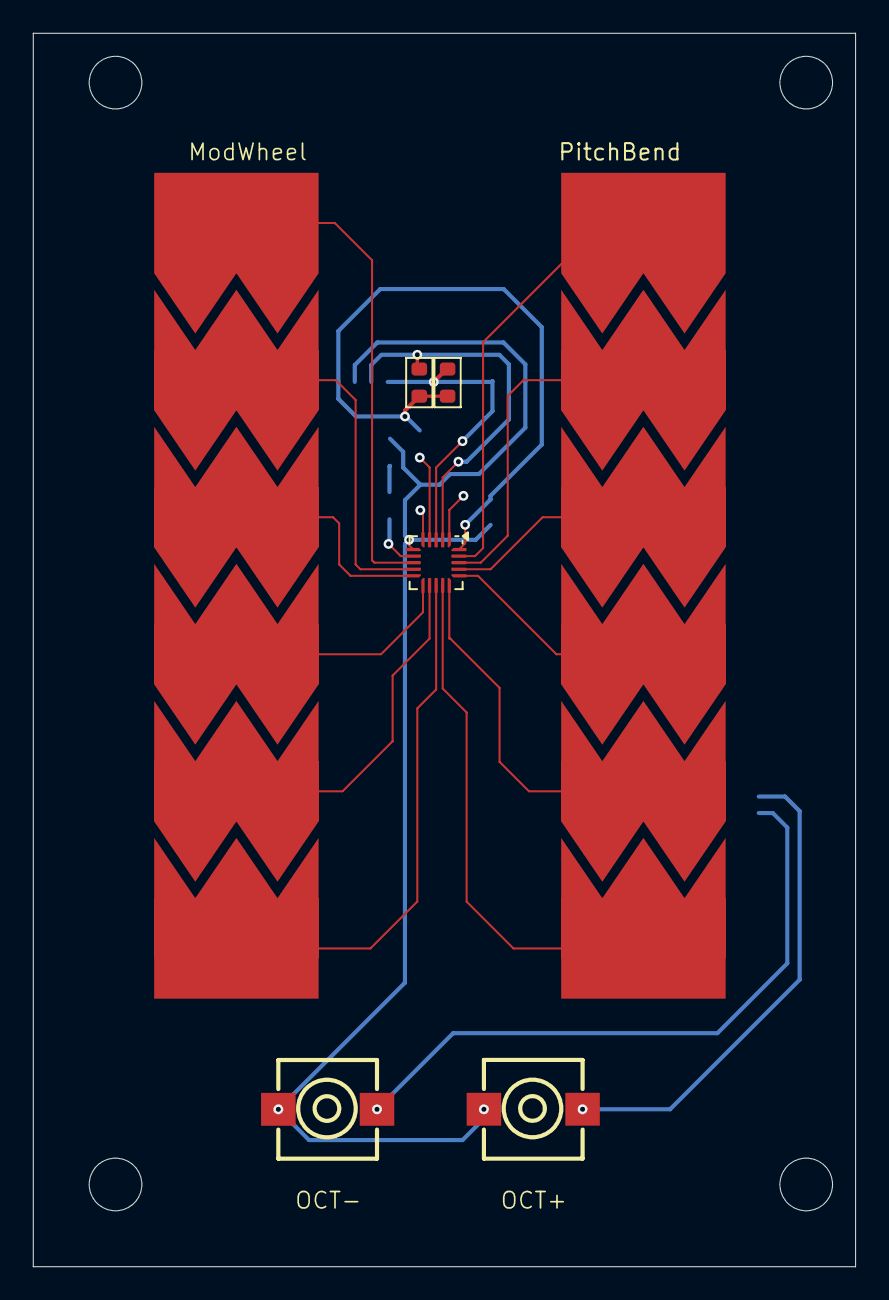
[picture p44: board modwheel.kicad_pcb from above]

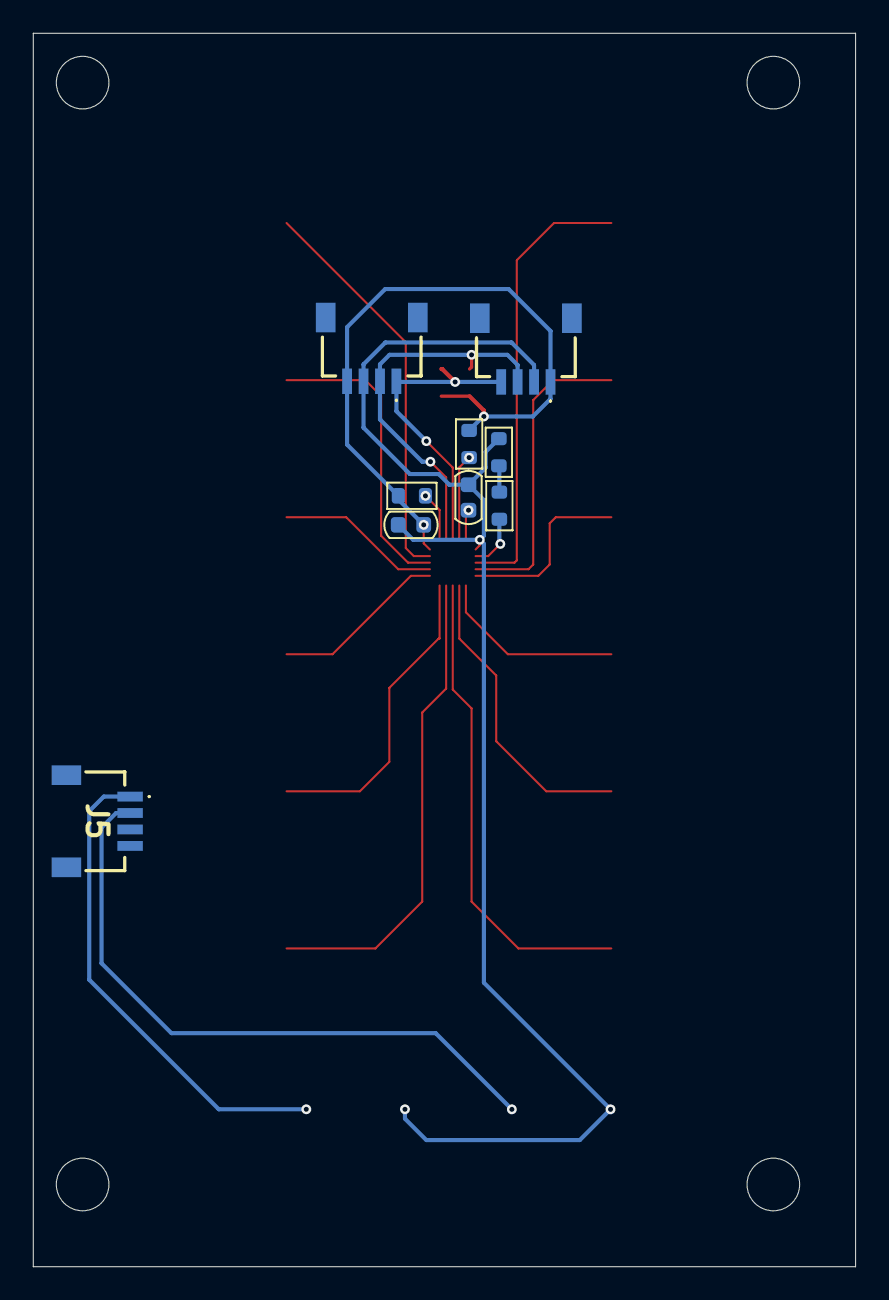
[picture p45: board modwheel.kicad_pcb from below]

Board: 2 copper layers, 50.0 x 75.0 mm, 20 parts (9 on the bottom side), 23 nets.

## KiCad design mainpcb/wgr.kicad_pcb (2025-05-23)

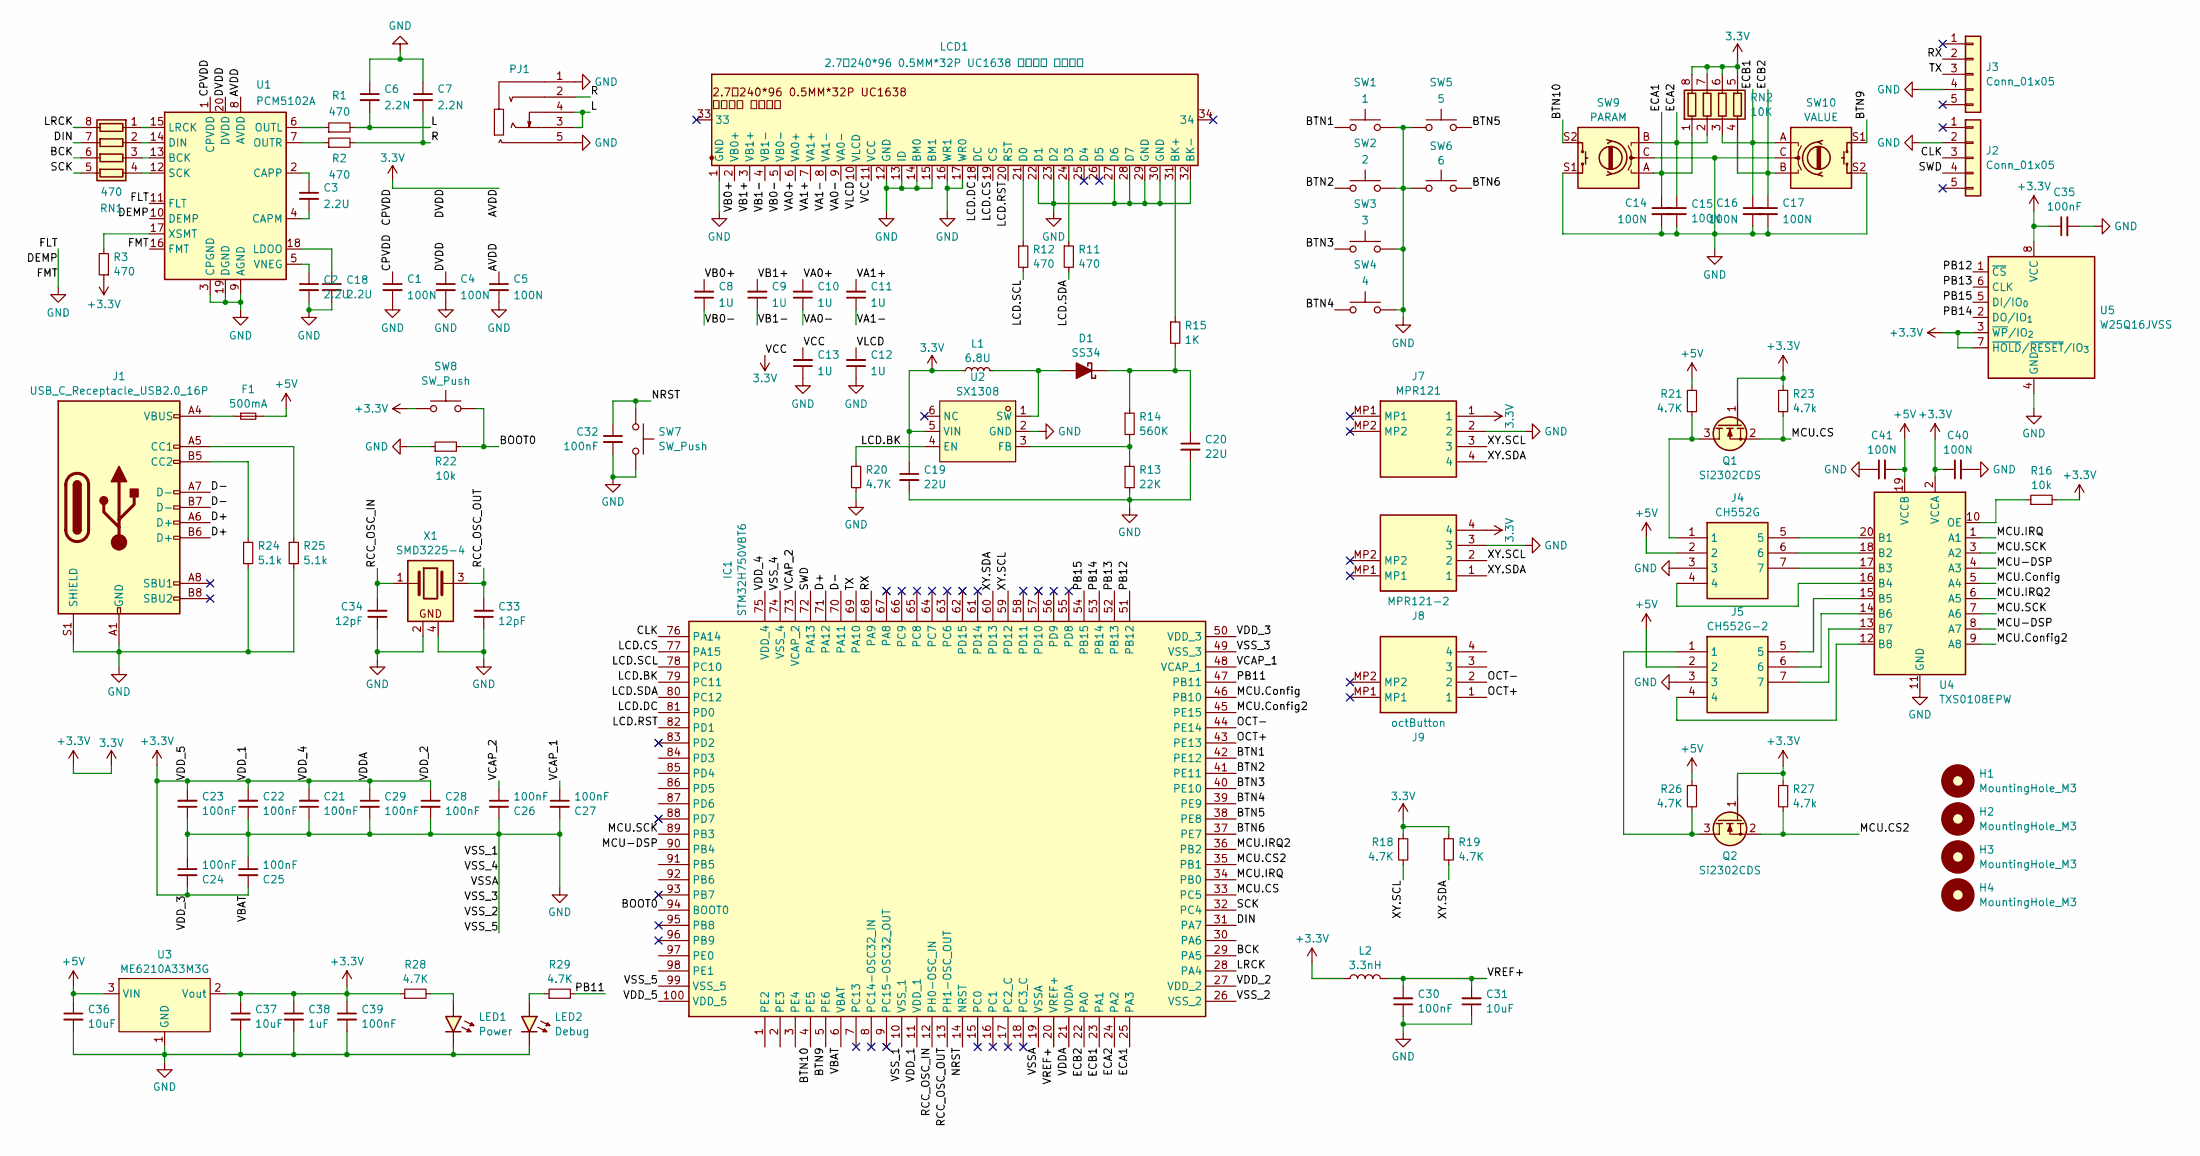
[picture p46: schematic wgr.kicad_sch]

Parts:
C1, C4, C5, C14, C15, C16, C17: 100N; C_0805_2012Metric
C2, C3, C18: 2.2U; C_0805_2012Metric
C6, C7: 2.2N; C_0805_2012Metric
C8, C9, C10, C11, C12, C13: 1U; C_0805_2012Metric
C19, C20: 22U; C_1206_3216Metric
C21, C22, C23, C24, C25, C26, C27, C28, C29, C30, C32, C35, C39: 100nF; C_0603_1608Metric
C31: 10uF; C_0603_1608Metric
C33, C34: 12pF; C_0603_1608Metric
C36, C37: 10uF; C_0805_2012Metric
C38: 1uF; C_0805_2012Metric
C40, C41: 100N; C_0603_1608Metric
D1: SS34; D_SMA
F1: 500mA; Fuse_0603_1608Metric
H1, H2, H3, H4: MountingHole_M3; MountingHole_3.2mm_M3
IC1: STM32H750VBT6; QFP50P1600X1600X160-100N; Manufacturer_Part_Number STM32H750VBT6; Mouser Part Number 511-STM32H750VBT6
J1: USB_C_Receptacle_USB2.0_16P; USB_C_Receptacle_G-Switch_GT-USB-7010ASV
J2, J3: Conn_01x05; Harwin_M20-89005xx_1x05_P2.54mm_Horizontal
J4: CH552G; SM07B-SRSS-TB; Manufacturer_Part_Number SM07B-SRSS-TB (LF)(SN)
J5: CH552G-2; SM07B-SRSS-TB; Manufacturer_Part_Number SM07B-SRSS-TB (LF)(SN)
J7: MPR121; SM04BSRSSTB; Manufacturer_Part_Number SM04B-SRSS-TB
J8: MPR121-2; SM04BSRSSTB; Manufacturer_Part_Number SM04B-SRSS-TB
J9: octButton; SM04BSRSSTB; Manufacturer_Part_Number SM04B-SRSS-TB
L1: 6.8U; L_APV_APH0420
L2: 3.3nH; L_0603_1608Metric; Part Number MI0603K300R-10
LCD1: 2.7寸240*96 0.5MM*32P UC1638 三串背光 背面插座; Hirose_FH12-32S-0.5SH_1x32-1MP_P0.50mm_Horizontal
LED1: Power; LED_0805_2012Metric
LED2: Debug; LED_0805_2012Metric
PJ1: AUDIO-IN-SMD_PJ-327A_C22355751; Manufacturer Part PJ-327A; LCSC Part Name PJ-327A
Q1, Q2: Si2302CDS; SOT-23
R1, R2, R3, R11, R12: 470; R_0805_2012Metric
R13: 22K; R_0603_1608Metric
R14: 560K; R_0603_1608Metric
R15: 1K; R_0805_2012Metric
R16: 10k; R_0603_1608Metric
R18, R19, R20, R21, R26, R28, R29: 4.7K; R_0805_2012Metric
R22: 10k; R_0603_1608Metric_Pad0.98x0.95mm
R23, R27: 4.7k; R_0805_2012Metric
R24, R25: 5.1k; R_0603_1608Metric_Pad0.98x0.95mm
RN1: 470; R_Array_Convex_4x0603
RN2: 10K; R_Array_Convex_4x0603
SW1: 1; KEY-SMD_2P-L6.0-W6.0-P6.00
SW2: 2; KEY-SMD_2P-L6.0-W6.0-P6.00
SW3: 3; KEY-SMD_2P-L6.0-W6.0-P6.00
SW4: 4; KEY-SMD_2P-L6.0-W6.0-P6.00
SW5: 5; KEY-SMD_2P-L6.0-W6.0-P6.00
SW6: 6; KEY-SMD_2P-L6.0-W6.0-P6.00
SW7, SW8: SW_Push; SW-SMD_4P-L4.5-W4.5-P3.00-LS7.0_TS-1009S-03826
SW9: PARAM; SW-TH_EC11XXXXXXXX
SW10: VALUE; SW-TH_EC11XXXXXXXX
U1: PCM5102A; TSSOP-20_4.4x6.5mm_P0.65mm
U2: SX1308; SOT-23-6_L2.9-W1.6-P0.95-LS2.8-BL; Manufacturer Part SX1308; LCSC Part Name 高效1.2MHz 2A升压转换器
U3: ME6210A33M3G; SOT-23
U4: TXS0108EPW; TSSOP-20_4.4x6.5mm_P0.65mm
U5: W25Q16JVSS; SOIC-8_5.3x5.3mm_P1.27mm
X1: SMD3225-4; Crystal_SMD_3225-4Pin_3.2x2.5mm

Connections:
+3.3V: C1.1, C4.1, C5.1, C13.2, C19.1, C21.2, C22.2, C23.2, C24.2, C25.2, C28.1, C29.1, C35.1, C37.1, C38.1, C39.1, C40.1, IC1.6 (VBAT), IC1.11 (VDD_1), IC1.21 (VDDA), IC1.27 (VDD_2), IC1.50 (VDD_3), IC1.75 (VDD_4), IC1.100 (VDD_5), J7.1, J8.4, L1.1, L2.1, LCD1.11 (VCC), Q1.1 (G), Q2.1 (G), R3.1, R16.2, R18.1, R19.1, R23.1, R27.1, R28.1, RN2.5 (R4.2), RN2.6 (R3.2), RN2.7 (R2.2), RN2.8 (R1.2), SW8.1, U1.1 (CPVDD), U1.8 (AVDD), U1.20 (DVDD), U2.5 (VIN), U3.2 (Vout), U4.2 (VCCA), U5.3 (~WP/IO_{2}), U5.7 (~HOLD/~RESET/IO_{3}), U5.8 (VCC)
+5V: C36.1, C41.2, F1.2, J4.2, J5.2, R21.1, R26.1, U3.3 (VIN), U4.19 (VCCB)
/BCK: IC1.29 (PA5), RN1.6 (R3.2)
/BOOT0: IC1.94 (BOOT0), R22.2, SW8.2
/BTN1: IC1.42 (PE12), SW1.1
/BTN2: IC1.41 (PE11), SW2.1
/BTN3: IC1.40 (PE10), SW3.1
/BTN4: IC1.39 (PE9), SW4.1
/BTN5: IC1.38 (PE8), SW5.2
/BTN6: IC1.37 (PE7), SW6.2
/BTN9: IC1.5 (PE6), SW10.S1
/BTN10: IC1.4 (PE5), SW9.S2
/CLK: IC1.76 (PA14), J2.3
/D+: IC1.71 (PA12), J1.A6 (D+), J1.B6 (D+)
/D-: IC1.70 (PA11), J1.A7 (D-), J1.B7 (D-)
/DIN: IC1.31 (PA7), RN1.7 (R2.2)
/ECA1: C14.1, IC1.25 (PA3), RN2.1 (R1.1), SW9.A
/ECA2: C15.1, IC1.24 (PA2), RN2.2 (R2.1), SW9.B
/ECB1: C16.1, IC1.23 (PA1), RN2.3 (R3.1), SW10.A
/ECB2: C17.1, IC1.22 (PA0), RN2.4 (R4.1), SW10.B
/L: C6.2, PJ1.3, PJ1.4, R1.2
/LCD.BK: IC1.79 (PC11), R20.1, U2.4 (EN)
/LCD.CS: IC1.77 (PA15), LCD1.19 (CS)
/LCD.DC: IC1.81 (PD0), LCD1.18 (DC)
/LCD.RST: IC1.82 (PD1), LCD1.20 (RST)
/LCD.SCL: IC1.78 (PC10), R12.2
/LCD.SDA: IC1.80 (PC12), R11.2
/LRCK: IC1.28 (PA4), RN1.8 (R1.2)
/MCU-DSP: IC1.90 (PB4), U4.4 (A3), U4.8 (A7)
/MCU.CS: IC1.33 (PC5), Q1.2 (S), R23.2
/MCU.CS2: IC1.35 (PB1), Q2.2 (S), R27.2
/MCU.Config: IC1.46 (PB10), U4.5 (A4)
/MCU.Config2: IC1.45 (PE15), U4.9 (A8)
/MCU.IRQ: IC1.34 (PB0), U4.1 (A1)
/MCU.IRQ2: IC1.36 (PB2), U4.6 (A5)
/MCU.SCK: IC1.89 (PB3), U4.3 (A2), U4.7 (A6)
/NRST: C32.1, IC1.14 (NRST), SW7.1
/OCT+: IC1.43 (PE13), J9.1
/OCT-: IC1.44 (PE14), J9.2
/PB12: IC1.51 (PB12), U5.1 (~CS)
/PB13: IC1.52 (PB13), U5.6 (CLK)
/PB14: IC1.53 (PB14), U5.2 (DO/IO_{1})
/PB15: IC1.54 (PB15), U5.5 (DI/IO_{0})
/R: C7.2, PJ1.2, R2.2
/RCC_OSC_IN: C34.2, IC1.12 (PH0-OSC_IN), X1.1
/RCC_OSC_OUT: C33.2, IC1.13 (PH1-OSC_OUT), X1.3
/RX: IC1.68 (PA9), J3.2
/SCK: IC1.32 (PC4), RN1.5 (R4.2)
/SWD: IC1.72 (PA13), J2.4
/TX: IC1.69 (PA10), J3.3
/VA0+: C10.2, LCD1.6 (VA0+)
/VA0-: C10.1, LCD1.9 (VA0-)
/VA1+: C11.2, LCD1.7 (VA1+)
/VA1-: C11.1, LCD1.8 (VA1-)
/VB0+: C8.2, LCD1.2 (VB0+)
/VB0-: C8.1, LCD1.5 (VB0-)
/VB1+: C9.2, LCD1.3 (VB1+)
/VB1-: C9.1, LCD1.4 (VB1-)
/VCAP_1: C27.1, IC1.48 (VCAP_1)
/VCAP_2: C26.1, IC1.73 (VCAP_2)
/VLCD: C12.2, LCD1.10 (VLCD)
/VREF+: C30.2, C31.2, IC1.20 (VREF+), L2.2
/XY.SCL: IC1.59 (PD12), J7.3, J8.2, R18.2
/XY.SDA: IC1.60 (PD13), J7.4, J8.1, R19.2
GND: C1.2, C2.2, C4.2, C5.2, C6.1, C7.1, C12.1, C13.1, C14.2, C15.2, C16.2, C17.2, C18.2, C19.2, C20.2, C21.1, C22.1, C23.1, C24.1, C25.1, C26.2, C27.2, C28.2, C29.2, C30.1, C31.1, C32.2, C33.1, C34.1, C35.2, C36.2, C37.2, C38.2, C39.2, C40.2, C41.1, IC1.10 (VSS_1), IC1.19 (VSSA), IC1.26 (VSS_2), IC1.49 (VSS_3), IC1.74 (VSS_4), IC1.99 (VSS_5), J1.A1 (GND), J1.A12 (GND), J1.B1 (GND), J1.B12 (GND), J1.S1 (SHIELD), J2.2, J3.4, J4.3, J5.3, J7.2, J8.3, LCD1.1 (GND), LCD1.12 (GND), LCD1.13 (ID), LCD1.14 (BM0), LCD1.15 (BM1), LCD1.16 (WR1), LCD1.17 (WR0), LCD1.22 (D1), LCD1.23 (D2), LCD1.27 (D6), LCD1.28 (D7), LCD1.29 (GND), LCD1.30 (GND), LCD1.32 (BK-), LED1.1 (K), LED2.1 (K), PJ1.1, PJ1.5, R13.2, R20.2, R22.1, R24.2, R25.2, SW1.2, SW2.2, SW3.2, SW4.2, SW5.1, SW6.1, SW7.2, SW9.C, SW9.S1, SW10.C, SW10.S2, U1.3 (CPGND), U1.9 (AGND), U1.10 (DEMP), U1.11 (FLT), U1.16 (FMT), U1.19 (DGND), U2.2 (GND), U3.1 (GND), U4.11 (GND), U5.4 (GND), X1.2, X1.4
unnamed: D1.2 (A), L1.2, U2.1 (SW)
unnamed: C20.1, D1.1 (K), R14.1, R15.2
unnamed: F1.1, J1.A4 (VBUS), J1.A9 (VBUS), J1.B4 (VBUS), J1.B9 (VBUS)
unnamed: IC1.47 (PB11), R29.2
unnamed: J1.A5 (CC1), R25.1
unnamed: J1.B5 (CC2), R24.1
unnamed: LCD1.31 (BK+), R15.1
unnamed: LCD1.21 (D0), R12.1
unnamed: LCD1.24 (D3), R11.1
unnamed: LED1.2 (A), R28.2
unnamed: LED2.2 (A), R29.1
unnamed: J4.1, Q1.3 (D), R21.2
unnamed: J5.1, Q2.3 (D), R26.2
unnamed: RN1.1 (R1.1), U1.15 (LRCK)
unnamed: RN1.2 (R2.1), U1.14 (DIN)
unnamed: RN1.3 (R3.1), U1.13 (BCK)
unnamed: RN1.4 (R4.1), U1.12 (SCK)
unnamed: C3.2, U1.4 (CAPM)
unnamed: C3.1, U1.2 (CAPP)
unnamed: C18.1, U1.18 (LDOO)
unnamed: R1.1, U1.6 (OUTL)
unnamed: R2.1, U1.7 (OUTR)
unnamed: C2.1, U1.5 (VNEG)
unnamed: R3.2, U1.17 (XSMT)
unnamed: R13.1, R14.2, U2.3 (FB)
unnamed: J4.5, U4.20 (B1)
unnamed: J4.6, U4.18 (B2)
unnamed: J4.7, U4.17 (B3)
unnamed: J4.4, U4.16 (B4)
unnamed: J5.5, U4.15 (B5)
unnamed: J5.6, U4.14 (B6)
unnamed: J5.7, U4.13 (B7)
unnamed: J5.4, U4.12 (B8)
unnamed: R16.1, U4.10 (OE)

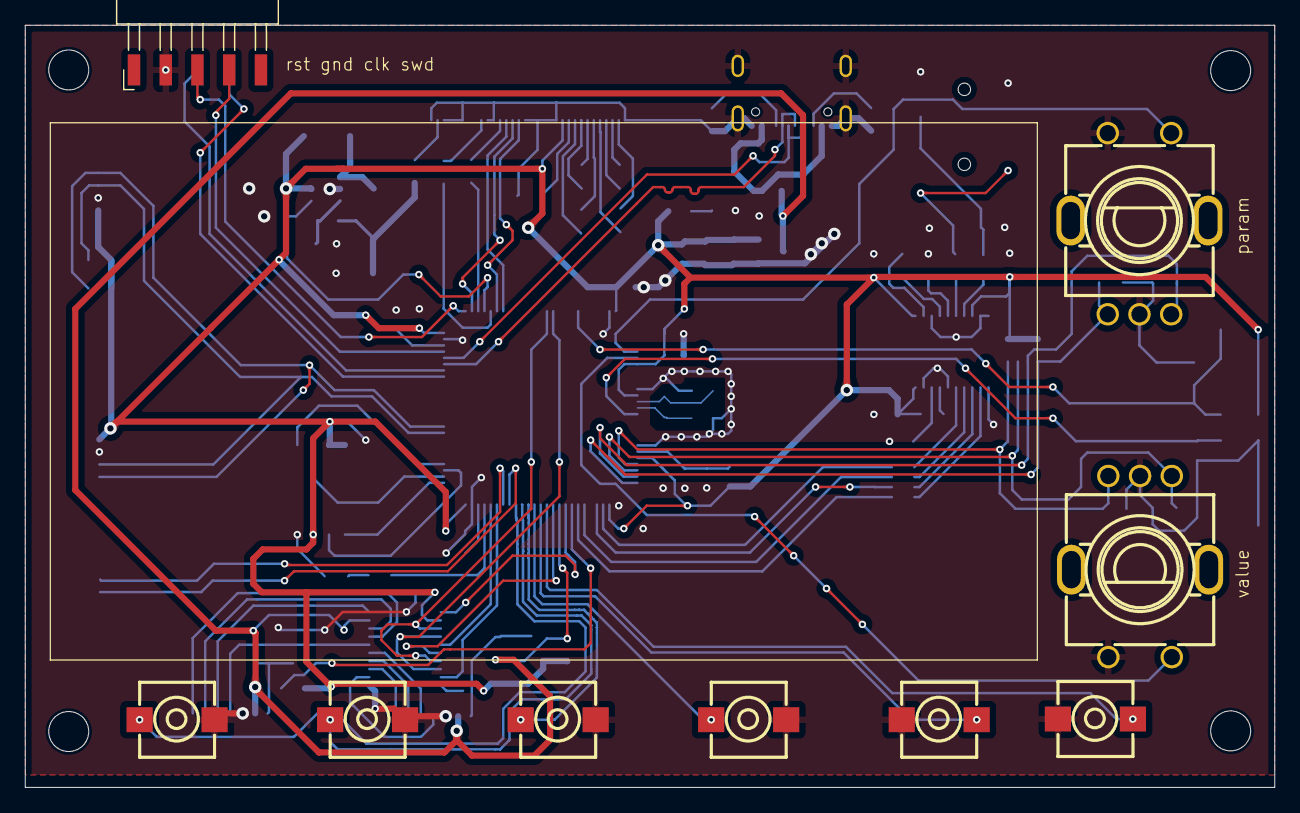
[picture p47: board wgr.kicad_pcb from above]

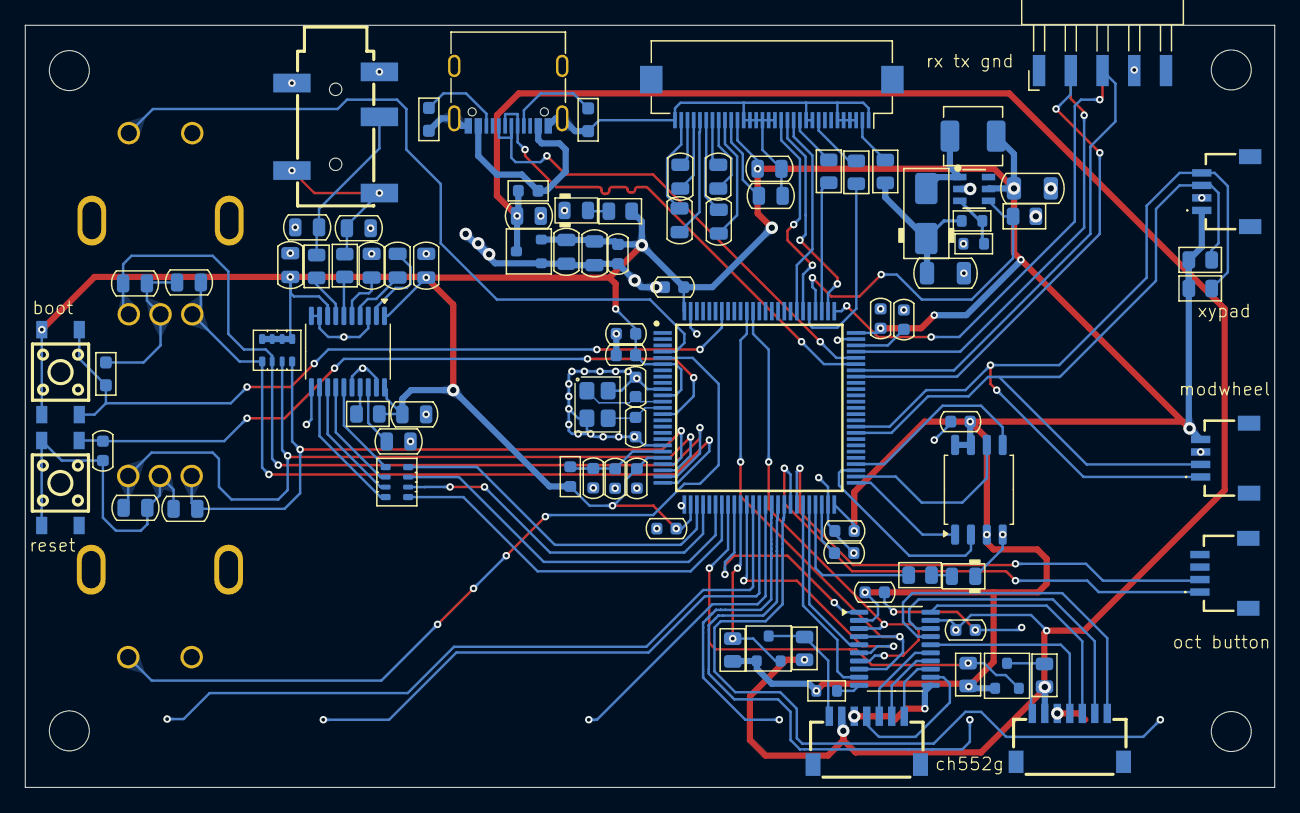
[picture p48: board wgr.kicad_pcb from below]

Board: 2 copper layers, 100.0 x 61.0 mm, 103 parts (90 on the bottom side), 99 nets.

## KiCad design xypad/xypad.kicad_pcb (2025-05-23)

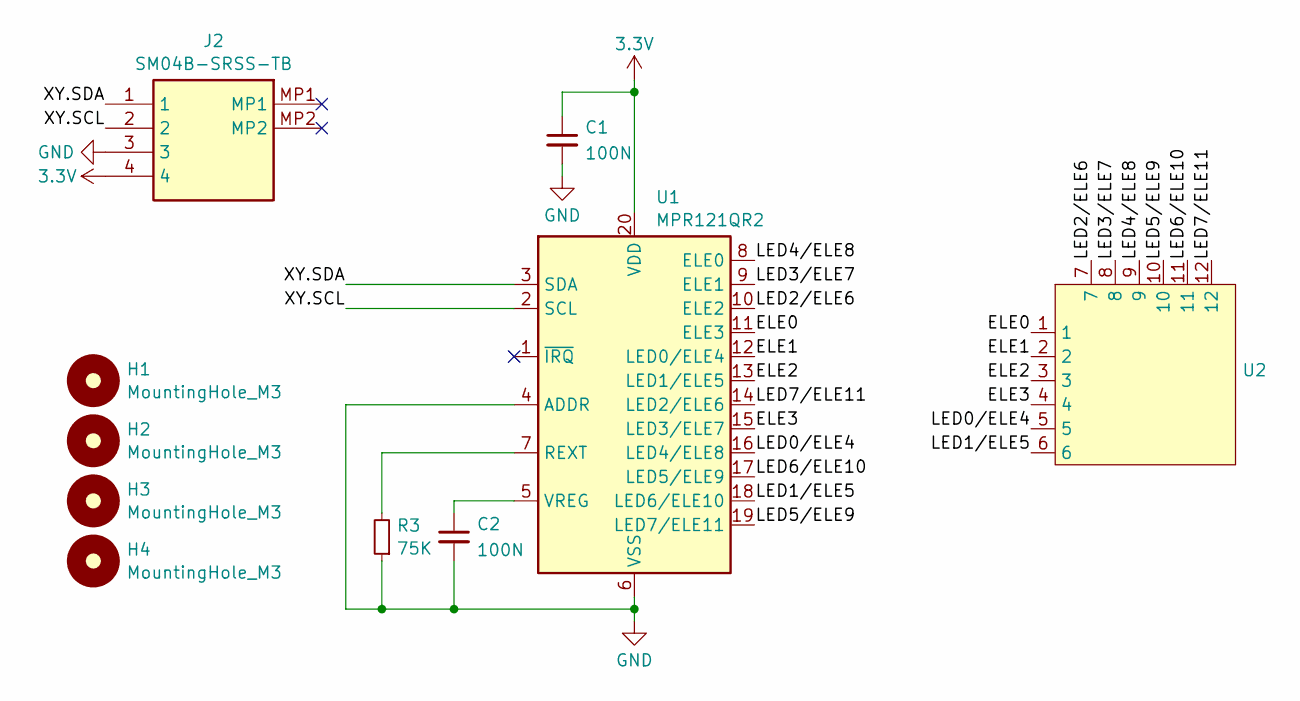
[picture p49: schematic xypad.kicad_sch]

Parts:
C1, C2: 100N; C_0805_2012Metric
H1, H2, H3, H4: MountingHole_M3; MountingHole_3.2mm_M3
J2: SM04B-SRSS-TB; SM04BSRSSTB; Manufacturer_Part_Number SM04B-SRSS-TB
R3: 75K; R_0805_2012Metric
U1: MPR121QR2; UQFN-20_3x3mm_P0.4mm
U2: touchpad6x6

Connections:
3.3V: C1.1, J2.4, U1.20 (VDD)
/ELE0: U1.11 (ELE3), U2.1
/ELE1: U1.12 (LED0/ELE4), U2.2
/ELE2: U1.13 (LED1/ELE5), U2.3
/ELE3: U1.15 (LED3/ELE7), U2.4
/LED0/ELE4: U1.16 (LED4/ELE8), U2.5
/LED1/ELE5: U1.18 (LED6/ELE10), U2.6
/LED2/ELE6: U1.10 (ELE2), U2.7
/LED3/ELE7: U1.9 (ELE1), U2.8
/LED4/ELE8: U1.8 (ELE0), U2.9
/LED5/ELE9: U1.19 (LED7/ELE11), U2.10
/LED6/ELE10: U1.17 (LED5/ELE9), U2.11
/LED7/ELE11: U1.14 (LED2/ELE6), U2.12
/XY.SCL: J2.2, U1.2 (SCL)
/XY.SDA: J2.1, U1.3 (SDA)
GND: C1.2, C2.2, J2.3, R3.1, U1.4 (ADDR), U1.6 (VSS)
unnamed: R3.2, U1.7 (REXT)
unnamed: C2.1, U1.5 (VREG)

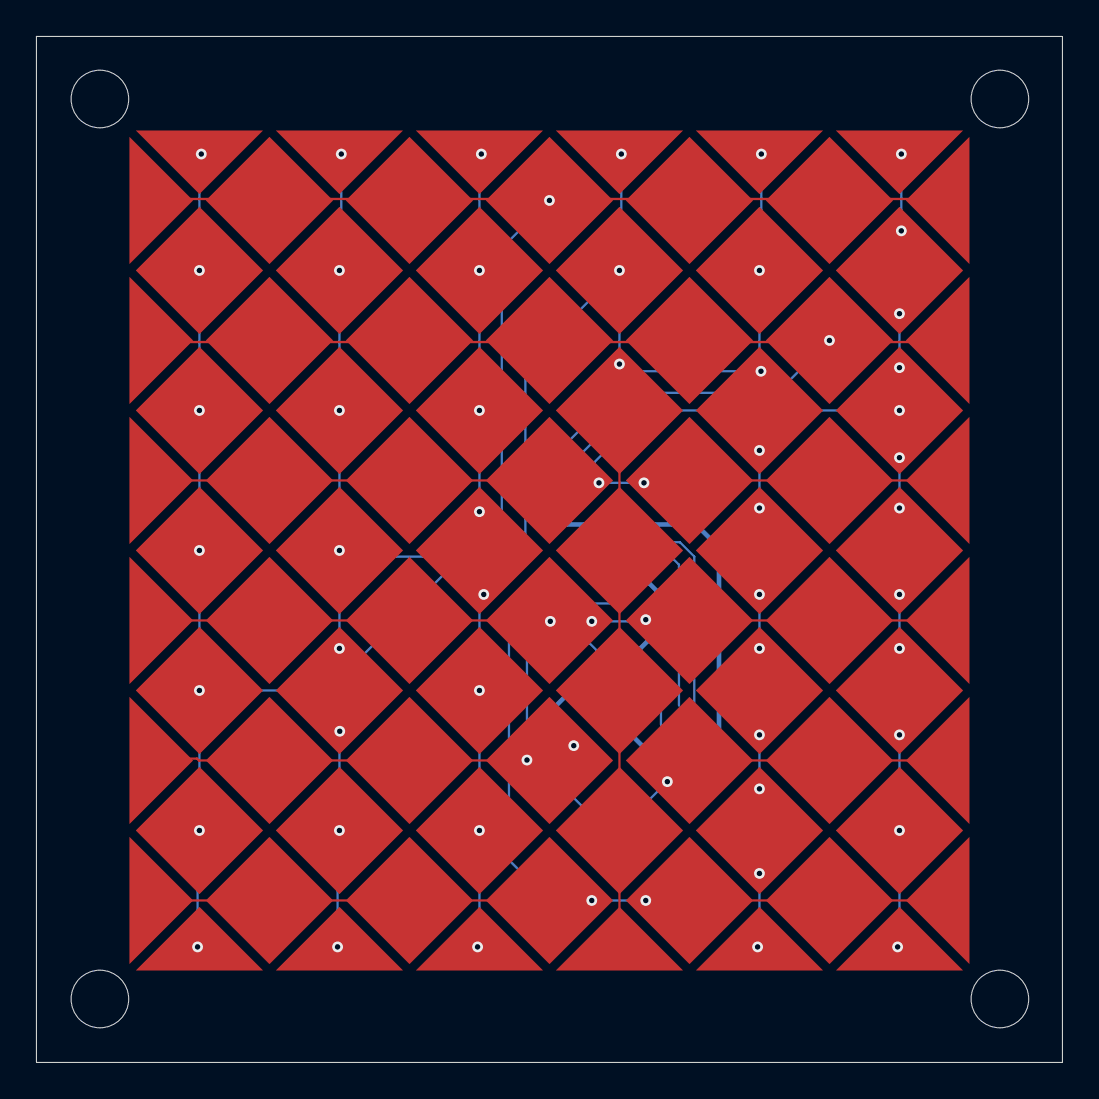
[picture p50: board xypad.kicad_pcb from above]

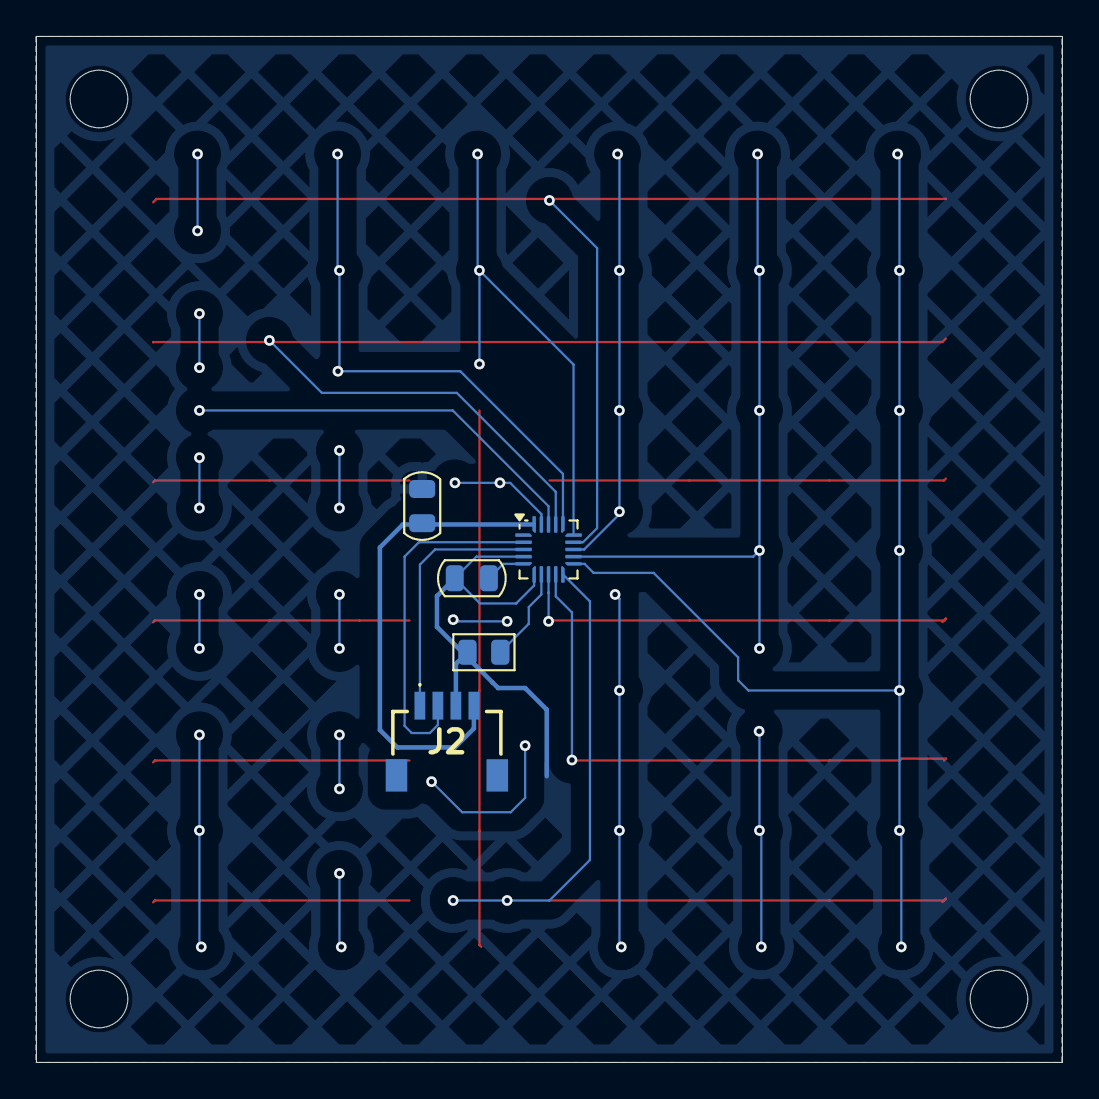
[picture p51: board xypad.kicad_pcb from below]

Board: 2 copper layers, 57.0 x 57.0 mm, 10 parts (5 on the bottom side), 18 nets.

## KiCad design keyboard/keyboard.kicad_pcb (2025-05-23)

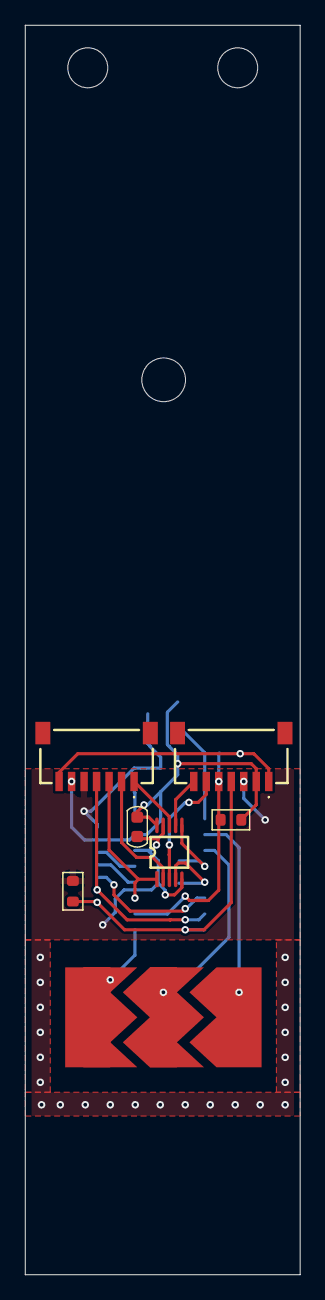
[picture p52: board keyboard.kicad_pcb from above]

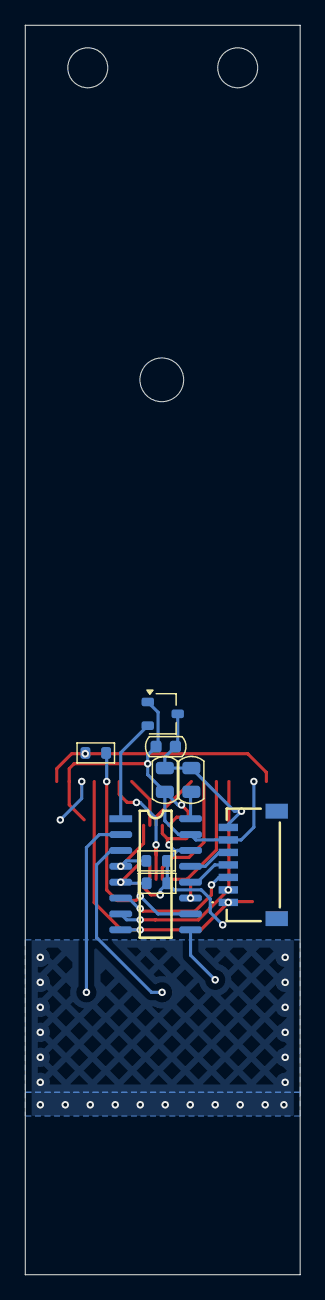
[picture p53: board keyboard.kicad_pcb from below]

Board: 2 copper layers, 22.0 x 100.0 mm, 19 parts (9 on the bottom side), 21 nets.

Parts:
C1, C2: 1U; C_0805_2012Metric
C3, C4: 100N; C_0603_1608Metric
H1, H2: FIXED; MountingHole_3.2mm_M3
H3: SPRING; MountingHole_3.2mm_M3
J1: PROGRAM; SM07BSRSSTBLFSN
J2: NEXT; SM07BSRSSTBLFSN
J3: PREV; SM07BSRSSTBLFSN
R1, R2, R3, R4: 4.7K; R_0603_1608Metric
R5: 0; R_0603_1608Metric
U1: OH49E; SOT-23W
U2: TouchSlider-3_16x8mm
U3: CH442E; MSOP10
U4: CH552G; SOP16

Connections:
5V: C2.1, C3.1, C4.1, J1.6, J2.6, J3.2, R1.1, U1.1 (VCC), U3.10 (VCC), U4.15 (VCC/VDD)
/AIN: U1.2 (VOUT), U4.1 (P3.2/TXD1_/INT0/VBUS1/AIN3)
/CS_NEXT: J2.3, U3.1 (IN), U4.11 (P3.4/PWM2/RXD1_/T0)
/CS_PREV: J3.5, R1.2, R5.2, U4.10 (P3.3/INT1)
/DM: J1.5, U4.13 (P3.7/UDM)
/DP: J1.4, U4.12 (P3.6/UDP)
/MCS: J2.7, J3.1, R5.1
/OK_NEXT: J1.2, J2.4, U4.7 (P3.1/PWM2_/TXD)
/OK_PREV: J1.1, J3.4, R2.1, U4.8 (P3.0/PWM1_/RXD)
/RESET: J1.3, U4.6 (RST/T2EX_/CAP2_)
/SCK: R4.1, U3.4 (DB), U4.5 (P1.7/SCK/TXD1/TIN5)
/SCK_NEXT: J2.2, U3.2 (S1B)
/SCK_PREV: J3.6, U3.3 (S2B)
/SDA: R3.1, U3.6 (DC), U4.4 (P1.6/MISO/RXD1/TIN4)
/SDA_NEXT: J2.1, U3.8 (S1C)
/SDA_PREV: J3.7, U3.7 (S2C)
/TIN0: U2.1, U4.9 (P1.1/T2EX/CAP2/TIN1/VBUS2/AIN0)
/TIN1: U2.3, U4.2 (P1.4/T2_/CAP1_/SCS/TIN2/UCC1/AIN1)
/TIN2: U2.2, U4.3 (P1.5/MOSI/PWM1/TIN3/UCC2/AIN2)
GND: C1.2, C2.2, C3.2, C4.2, J1.7, J2.5, J3.3, R2.2, R3.2, R4.2, U1.3 (GND), U3.5 (GND), U3.9 (EN#), U4.14 (GND/VSS)
unnamed: C1.1, U4.16 (V33)

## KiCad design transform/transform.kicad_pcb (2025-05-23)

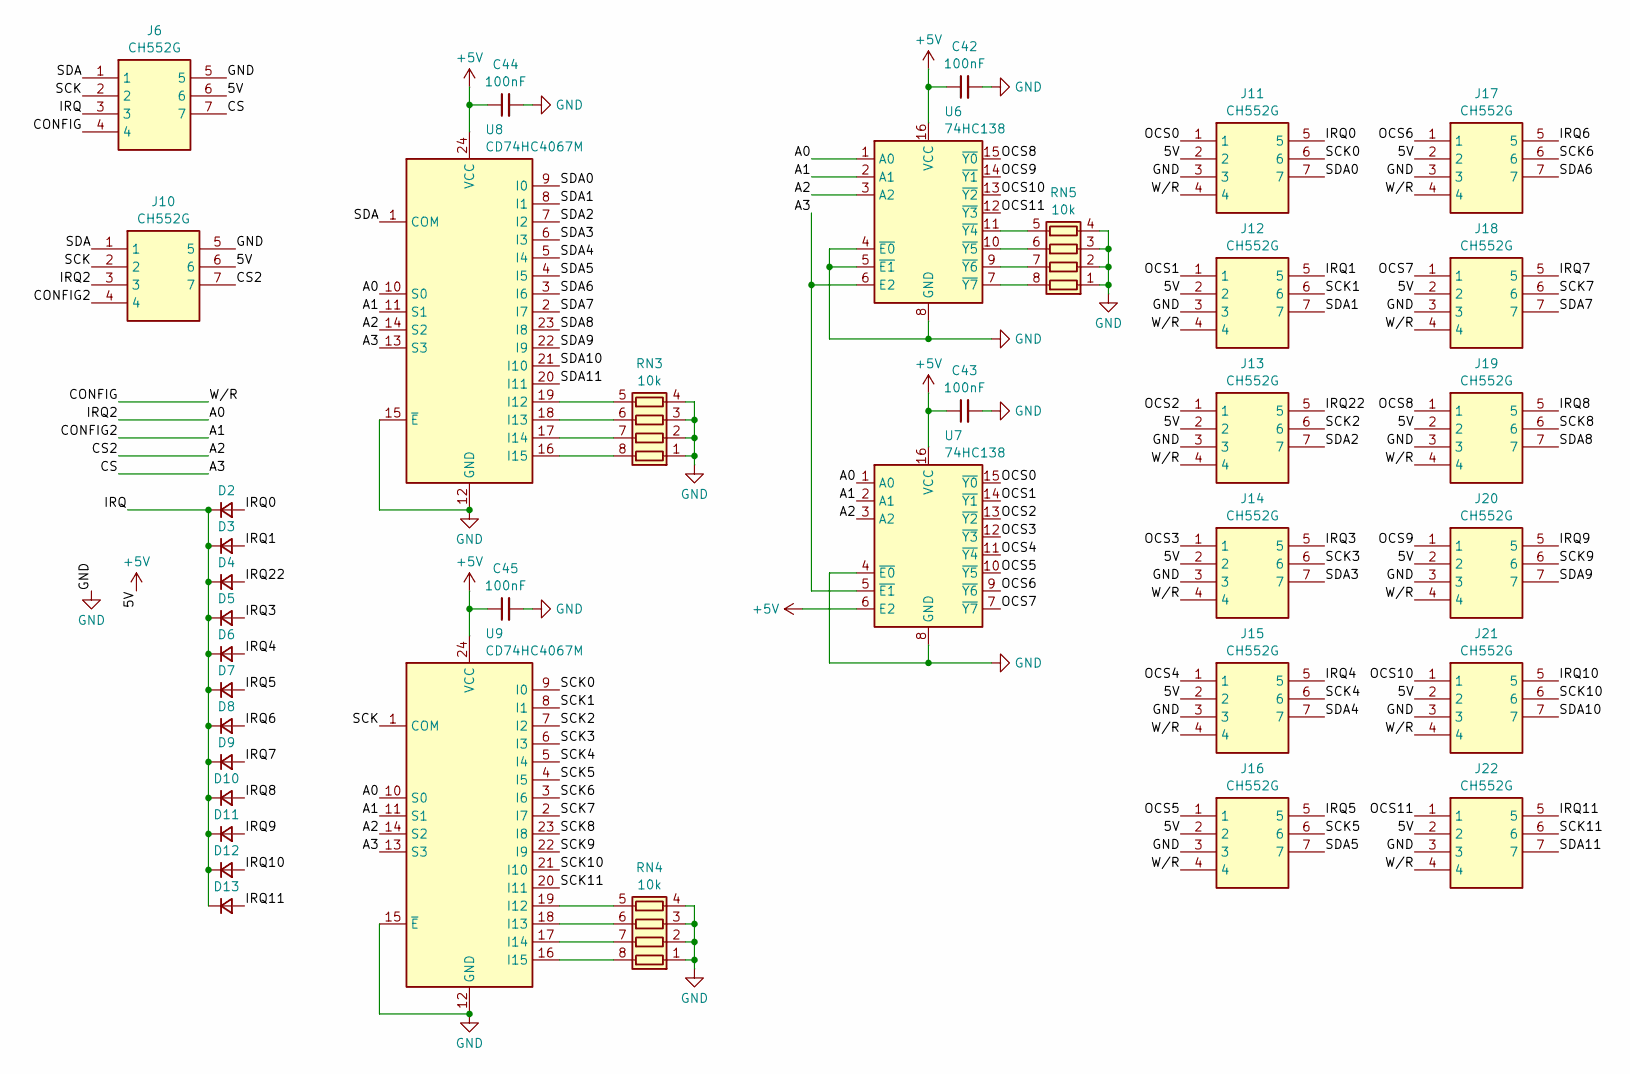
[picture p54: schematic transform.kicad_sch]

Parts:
C42, C43, C44, C45: 100nF; C_0603_1608Metric
D2, D3, D4, D5, D6, D7, D8, D9, D10, D11, D12, D13: D_Small; D_1206_3216Metric
J6, J10, J11, J12, J13, J14, J15, J16, J17, J18, J19, J20, J21, J22: CH552G; SM07B-SRSS-TB; Manufacturer_Part_Number SM07B-SRSS-TB (LF)(SN)
RN3, RN4, RN5: 10k; R_Array_Convex_4x0603
U6, U7: 74HC138; SOIC-16_3.9x9.9mm_P1.27mm
U8, U9: CD74HC4067M; SOIC-24W_7.5x15.4mm_P1.27mm

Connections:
+5V: C42.1, C43.1, C44.1, C45.1, J6.6, J10.6, J11.2, J12.2, J13.2, J14.2, J15.2, J16.2, J17.2, J18.2, J19.2, J20.2, J21.2, J22.2, U6.16 (VCC), U7.6 (E2), U7.16 (VCC), U8.24 (VCC), U9.24 (VCC)
/A0: J10.3, U6.1 (A0), U7.1 (A0), U8.10 (S0), U9.10 (S0)
/A1: J10.4, U6.2 (A1), U7.2 (A1), U8.11 (S1), U9.11 (S1)
/A2: J10.7, U6.3 (A2), U7.3 (A2), U8.14 (S2), U9.14 (S2)
/A3: J6.7, U6.6 (E2), U7.5 (~E1), U8.13 (S3), U9.13 (S3)
/CONFIG: J6.4, J11.4, J12.4, J13.4, J14.4, J15.4, J16.4, J17.4, J18.4, J19.4, J20.4, J21.4, J22.4
/IRQ: D2.1 (K), D3.1 (K), D4.1 (K), D5.1 (K), D6.1 (K), D7.1 (K), D8.1 (K), D9.1 (K), D10.1 (K), D11.1 (K), D12.1 (K), D13.1 (K), J6.3
/IRQ0: D2.2 (A), J11.5
/IRQ1: D3.2 (A), J12.5
/IRQ3: D5.2 (A), J14.5
/IRQ4: D6.2 (A), J15.5
/IRQ5: D7.2 (A), J16.5
/IRQ6: D8.2 (A), J17.5
/IRQ7: D9.2 (A), J18.5
/IRQ8: D10.2 (A), J19.5
/IRQ9: D11.2 (A), J20.5
/IRQ10: D12.2 (A), J21.5
/IRQ11: D13.2 (A), J22.5
/IRQ22: D4.2 (A), J13.5
/OCS0: J11.1, U7.15 (~Y0)
/OCS1: J12.1, U7.14 (~Y1)
/OCS2: J13.1, U7.13 (~Y2)
/OCS3: J14.1, U7.12 (~Y3)
/OCS4: J15.1, U7.11 (~Y4)
/OCS5: J16.1, U7.10 (~Y5)
/OCS6: J17.1, U7.9 (~Y6)
/OCS7: J18.1, U7.7 (~Y7)
/OCS8: J19.1, U6.15 (~Y0)
/OCS9: J20.1, U6.14 (~Y1)
/OCS10: J21.1, U6.13 (~Y2)
/OCS11: J22.1, U6.12 (~Y3)
/SCK: J6.2, J10.2, U9.1 (COM)
/SCK0: J11.6, U9.9 (I0)
/SCK1: J12.6, U9.8 (I1)
/SCK2: J13.6, U9.7 (I2)
/SCK3: J14.6, U9.6 (I3)
/SCK4: J15.6, U9.5 (I4)
/SCK5: J16.6, U9.4 (I5)
/SCK6: J17.6, U9.3 (I6)
/SCK7: J18.6, U9.2 (I7)
/SCK8: J19.6, U9.23 (I8)
/SCK9: J20.6, U9.22 (I9)
/SCK10: J21.6, U9.21 (I10)
/SCK11: J22.6, U9.20 (I11)
/SDA: J6.1, J10.1, U8.1 (COM)
/SDA0: J11.7, U8.9 (I0)
/SDA1: J12.7, U8.8 (I1)
/SDA2: J13.7, U8.7 (I2)
/SDA3: J14.7, U8.6 (I3)
/SDA4: J15.7, U8.5 (I4)
/SDA5: J16.7, U8.4 (I5)
/SDA6: J17.7, U8.3 (I6)
/SDA7: J18.7, U8.2 (I7)
/SDA8: J19.7, U8.23 (I8)
/SDA9: J20.7, U8.22 (I9)
/SDA10: J21.7, U8.21 (I10)
/SDA11: J22.7, U8.20 (I11)
GND: C42.2, C43.2, C44.2, C45.2, J6.5, J10.5, J11.3, J12.3, J13.3, J14.3, J15.3, J16.3, J17.3, J18.3, J19.3, J20.3, J21.3, J22.3, RN3.1 (R1.1), RN3.2 (R2.1), RN3.3 (R3.1), RN3.4 (R4.1), RN4.1 (R1.1), RN4.2 (R2.1), RN4.3 (R3.1), RN4.4 (R4.1), RN5.1 (R1.1), RN5.2 (R2.1), RN5.3 (R3.1), RN5.4 (R4.1), U6.4 (~E0), U6.5 (~E1), U6.8 (GND), U7.4 (~E0), U7.8 (GND), U8.12 (GND), U8.15 (~E), U9.12 (GND), U9.15 (~E)
unnamed: RN3.8 (R1.2), U8.16 (I15)
unnamed: RN3.7 (R2.2), U8.17 (I14)
unnamed: RN3.6 (R3.2), U8.18 (I13)
unnamed: RN3.5 (R4.2), U8.19 (I12)
unnamed: RN4.8 (R1.2), U9.16 (I15)
unnamed: RN4.7 (R2.2), U9.17 (I14)
unnamed: RN4.6 (R3.2), U9.18 (I13)
unnamed: RN4.5 (R4.2), U9.19 (I12)
unnamed: RN5.8 (R1.2), U6.7 (~Y7)
unnamed: RN5.7 (R2.2), U6.9 (~Y6)
unnamed: RN5.6 (R3.2), U6.10 (~Y5)
unnamed: RN5.5 (R4.2), U6.11 (~Y4)

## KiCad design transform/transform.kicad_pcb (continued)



Board: 2 copper layers, 43.6 x 60.6 mm, 37 parts (19 on the bottom side), 70 nets.

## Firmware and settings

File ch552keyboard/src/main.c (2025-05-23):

#include "system.h"
#include "gpio.h"
#include "delay.h"
#include "uart.h"
#include "touchkey.h"
#include "pwm.h"

#include <stdint.h>
#include <stdio.h>
#include <string.h>
#include "ch554.h"
#include "ch554_usb.h"

// --------------------------------------------------------------------------------
// timer
// --------------------------------------------------------------------------------
static void Timer_Init(void);
static void Timer_Interrupt(void) __interrupt(INT_NO_TMR2);
static uint16_t Timer_GetTime(void);
static volatile uint16_t timerTick_ = 0;
#define SPI_TIMEOUT_MS 5

// --------------------------------------------------------------------------------
// Touchkey Slider
// --------------------------------------------------------------------------------
#define TIN0_PIN P11
#define TIN1_PIN P14
#define TIN2_PIN P15
#define TKEY_DOWN_THRESHOLD 2000
#define TKEY_UP_THRESHOLD 500
#define TKEY_POS_SCALE 0x7f
static const __code enum TouchKeyChannel tkeyChannelTable[] = {
    TK_P11, TK_P15, TK_P14
};
#define TKEY_NUM (sizeof(tkeyChannelTable) / sizeof(enum TouchKeyChannel))

static void TouchKey_Init(void);
static uint8_t currentTkey = 0;
static volatile int8_t tkeyFingerPosition = 0;
uint16_t touchkeyFreeValues[TKEY_NUM];
uint16_t absValues[TKEY_NUM];
uint8_t pressFlag = 0;

// --------------------------------------------------------------------------------
// OH49E HALL ADC
// --------------------------------------------------------------------------------
#define ADC_PIN P32
static void HallADC_Init(void);
static volatile uint8_t hallAdcValue = 0;
static uint8_t lowAdcThreadhold = 0;
static uint8_t highAdcThreadhold = 0;

// --------------------------------------------------------------------------------
// Key SPI Commuunication
// --------------------------------------------------------------------------------
#define SPI_SCK_PIN P17
#define SPI_MISO_PIN P16
#define SPI_CS_PIN P33
#define SPI_SLAVE_SCS_PIN P14
#define SPI_WR_PIN P31
#define SPI_IRQ_ENABLE_PIN P34 // 下降沿产生IRQ
// TODO: 焊接所有的MCS和CS_PREV

static void KeyCommunication_Init(void);
static void KeyCommunication_Send(void);
static void KeyCommunication_Receive(void);

inline uint16_t Abs(uint16_t a, uint16_t b) {
    if (a > b) {
        return a - b;
    }
    else {
        return 0;
    }
}

void main(void) {
    CLK_config();
    DLY_ms(5);

    HallADC_Init();
    TouchKey_Init();
    KeyCommunication_Init();
    Timer_Init();
    EA = 1;

    for (;;) {
        if (PIN_read(SPI_CS_PIN) == 0 && currentTkey != 2) {
            if (PIN_read(SPI_WR_PIN) == 0) {
                KeyCommunication_Send();
            }
            else {
                KeyCommunication_Receive();
            }
        }

        if (ADC_START == 0) {
            hallAdcValue = ADC_DATA;
            ADC_START = 1;
        }

        if (TouchKey_Ready() == 1) {
            uint16_t keyData = TKEY_DAT;

            // uint16_t diff = Abs(touchkeyFreeValues[currentTkey], keyData);
            uint16_t diff = 0;
            if (touchkeyFreeValues[currentTkey] > keyData) {
                diff = touchkeyFreeValues[currentTkey] - keyData;
            }
            uint8_t mask = 1 << currentTkey;
            if (diff < TKEY_UP_THRESHOLD) {
                if (pressFlag & mask) {
                    pressFlag &= ~mask;
                }
            }
            else if (diff > TKEY_DOWN_THRESHOLD) {
                if (!(pressFlag & mask)) {
                    pressFlag |= mask;
                }
            }

            absValues[currentTkey] = diff;
            ++currentTkey;
            if (currentTkey >= TKEY_NUM) {
                currentTkey = 0;

                if (pressFlag) {
                    int16_t denominator = (absValues[0] + absValues[1] + absValues[2]) / TKEY_POS_SCALE;
                    if (denominator != 0) {
                        int16_t nominator = absValues[2] - absValues[0];
                        int16_t div = nominator / denominator;
                        if (div < -TKEY_POS_SCALE) tkeyFingerPosition = -TKEY_POS_SCALE;
                        else if (div > TKEY_POS_SCALE) tkeyFingerPosition = TKEY_POS_SCALE;
                        else tkeyFingerPosition = div;
                    }
                }
                else {
                    tkeyFingerPosition = 0;
                }
            }

            TouchKey_Channel(tkeyChannelTable[currentTkey]);
        }
    }
}

#define TIMER2_FREQ (F_CPU / 12)
#define TIMER2_MS 1
#define TIMER2_RELOAD (0xffff - TIMER2_FREQ * TIMER2_MS / 1000 + 1)
void Timer_Init(void) {
    T2MOD &= ~(bTMR_CLK | bT2_CLK); // Fsys/12
    RCAP2 = TIMER2_RELOAD;
    T2COUNT = TIMER2_RELOAD;
    TR2 = 1;
    ET2 = 1;
    TF2 = 0; // !need manual clear
}

void Timer_Interrupt(void) __interrupt(INT_NO_TMR2) {
    TF2 = 0;
    ++timerTick_;
}

uint16_t Timer_GetTime(void) {
    return timerTick_;
}

// ---------------------------------------------------------------------------------
static void TouchKey_Init(void) {
    PIN_input(TIN0_PIN);
    PIN_input(TIN1_PIN);
    PIN_input(TIN2_PIN);
    TouchKey_Fast();
    for (uint8_t i = 0; i < TKEY_NUM; i++) {
        touchkeyFreeValues[i] = TouchKey_PollRead(tkeyChannelTable[i]);
    }
    
    TouchKey_Channel(tkeyChannelTable[0]);
}                

void HallADC_Init(void) {
    PIN_input(ADC_PIN);
    ADC_enable();
    ADC_fast();
    ADC_input(ADC_PIN);
    ADC_START = 1;
}

void KeyCommunication_Init(void) {
    PIN_input(SPI_CS_PIN);
    PIN_input(SPI_WR_PIN);
    PIN_output(SPI_IRQ_ENABLE_PIN);
    PIN_low(SPI_IRQ_ENABLE_PIN);
    IT1 = 1;
    IE1 = 0;
}

void KeyCommunication_Send(void) {
    // SPI设置
    PIN_high(SPI_IRQ_ENABLE_PIN);
    DLY_us(20);
    PIN_output(SPI_SLAVE_SCS_PIN);
    SCS = 1;
    SPI0_SETUP = bS0_MODE_SLV;
    SPI0_CTRL = bS0_2_WIRE | bS0_CLR_ALL | bS0_AUTO_IF | bS0_MISO_OE;
    SPI0_CTRL &= ~bS0_CLR_ALL;
    PIN_output(SPI_MISO_PIN);
    PIN_input(SPI_SCK_PIN);

    SPI0_S_PRE = 0b11011000;
    SCS = 0;
    PIN_low(SPI_IRQ_ENABLE_PIN);// 请求以及CH442E转发送
    while (S0_IF_BYTE == 0 && PIN_read(SPI_CS_PIN) == 0) {}
    S0_IF_BYTE  = 0;
    SPI0_DATA = 0b10101010;
    while (S0_IF_BYTE  == 0 && PIN_read(SPI_CS_PIN) == 0) {}
    S0_IF_BYTE  = 0;
    SPI0_DATA = hallAdcValue;
    while (S0_IF_BYTE  == 0 && PIN_read(SPI_CS_PIN) == 0) {}
    S0_IF_BYTE  = 0;
    SPI0_DATA = tkeyFingerPosition;
    while (S0_IF_BYTE  == 0 && PIN_read(SPI_CS_PIN) == 0) {}
    S0_IF_BYTE  = 0;

    PIN_input(SPI_SLAVE_SCS_PIN);
}

void KeyCommunication_Receive(void) {
    // SPI设置
    PIN_high(SPI_IRQ_ENABLE_PIN);
    DLY_us(20);
    PIN_output(SPI_SLAVE_SCS_PIN);
    SCS = 1;
    SPI0_SETUP = bS0_MODE_SLV;
    SPI0_CTRL = bS0_DATA_DIR | bS0_2_WIRE | bS0_AUTO_IF | bS0_CLR_ALL;
    SPI0_CTRL &= ~bS0_CLR_ALL;
    PIN_input(SPI_MISO_PIN);
    PIN_input(SPI_SCK_PIN);

    SCS = 0;
    PIN_low(SPI_IRQ_ENABLE_PIN);// 请求以及CH442E转发送
    while (S0_IF_BYTE == 0 && PIN_read(SPI_CS_PIN) == 0) {}
    S0_IF_BYTE  = 0;
    highAdcThreadhold = SPI0_DATA;
    while (S0_IF_BYTE  == 0 && PIN_read(SPI_CS_PIN) == 0) {}
    S0_IF_BYTE  = 0;
    lowAdcThreadhold = SPI0_DATA;
    SCS = 1;

    PIN_input(SPI_SLAVE_SCS_PIN);
}

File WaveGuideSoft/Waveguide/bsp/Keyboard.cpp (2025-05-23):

#include "Keyboard.hpp"
#include "stm32h7xx_hal.h"
#include "stm32h7xx_ll_gpio.h"
#include "stm32h7xx_ll_exti.h"
#include "MemAttributes.hpp"
#include "bsp/DebugIO.hpp"

#include "FreeRTOS.h"
#include "semphr.h"
#include "task.h"

#include "utli/Clamp.hpp"
#include "utli/Map.hpp"

#define CS_GPIO GPIOC
#define CS_PIN GPIO_PIN_5
#define CS2_GPIO GPIOB
#define CS2_PIN GPIO_PIN_1
#define IRQ_GPIO GPIOB
#define IRQ_PIN GPIO_PIN_0
#define IRQ_IRQn EXTI0_IRQn
#define IRQ2_GPIO GPIOB
#define IRQ2_PIN GPIO_PIN_2
#define CONFIG_GPIO GPIOB
#define CONFIG_PIN GPIO_PIN_10
#define CONFIG2_GPIO GPIOE
#define CONFIG2_PIN GPIO_PIN_15

#define WRITE_READ_GPIO CONFIG_GPIO
#define WRITE_READ_PIN CONFIG_PIN
#define A0_GPIO IRQ2_GPIO
#define A0_PIN IRQ2_PIN
#define A1_GPIO CONFIG2_GPIO
#define A1_PIN CONFIG2_PIN
#define A2_GPIO CS2_GPIO
#define A2_PIN CS2_PIN
#define A3_GPIO CS_GPIO
#define A3_PIN CS_PIN

namespace bsp {

struct TransferData {
    uint8_t checkCode;
    uint8_t checkCode2;
    uint8_t adc;
    int8_t pos;

    bool IsValid() const {
        return checkCode == 0b11011000 && checkCode2 == 0b10101010 && adc > 30;
    }
};

static constexpr uint8_t kKeyboardMap[] {
    8, 10, 9, 11, 7, 6, 0, 2, 5, 4, 3, 1
};

static CKeyboard::KeyTransferData keyData_[CKeyboard::kNumKeys];
MEM_DMA_SRAMD3 static TransferData transferBuffer_;
static SPI_HandleTypeDef hspi_;
static DMA_HandleTypeDef hdma_;
static SemaphoreHandle_t spiSemHandle_ = nullptr;
static StaticSemaphore_t spiSem_;
static bool transferRequesing_ = false;
static bool writeRead_ = false;

void CKeyboard::Init(uint32_t dataRate) {
    dataRate_ = dataRate;
    
    // spi init
    __HAL_RCC_SPI6_CLK_ENABLE();
    hspi_.Instance = SPI6;
    HAL_SPI_DeInit(&hspi_);

    hspi_.Init.Mode = SPI_MODE_MASTER;
    hspi_.Init.Direction = SPI_DIRECTION_1LINE;
    hspi_.Init.DataSize = SPI_DATASIZE_8BIT;
    hspi_.Init.CLKPolarity = SPI_POLARITY_LOW;
    hspi_.Init.CLKPhase = SPI_PHASE_1EDGE;
    hspi_.Init.NSS = SPI_NSS_SOFT;
    hspi_.Init.BaudRatePrescaler = SPI_BAUDRATEPRESCALER_128;
    hspi_.Init.FirstBit = SPI_FIRSTBIT_MSB;
    hspi_.Init.TIMode = SPI_TIMODE_DISABLE;
    hspi_.Init.CRCCalculation = SPI_CRCCALCULATION_DISABLE;
    hspi_.Init.CRCPolynomial = 10;
    hspi_.Init.MasterKeepIOState = SPI_MASTER_KEEP_IO_STATE_ENABLE;
    hspi_.Init.MasterInterDataIdleness = SPI_MASTER_INTERDATA_IDLENESS_03CYCLE;
    hspi_.Init.IOSwap = SPI_IO_SWAP_ENABLE;
    HAL_SPI_Init(&hspi_);

    HAL_NVIC_EnableIRQ(SPI6_IRQn);
    HAL_NVIC_SetPriority(SPI6_IRQn, 10, 0);

    // spi gpio init
    // PB4 -> MISO
    // PB3 -> SCK
    // PD3 -> CS
    // PD1 -> IRQ
    __HAL_RCC_GPIOB_CLK_ENABLE();
    GPIO_InitTypeDef gpioInit{};
    gpioInit.Mode = GPIO_MODE_AF_PP;
    gpioInit.Pull = GPIO_NOPULL;
    gpioInit.Pin = GPIO_PIN_3;
    gpioInit.Alternate = GPIO_AF8_SPI6;
    gpioInit.Speed = GPIO_SPEED_FREQ_HIGH;
    HAL_GPIO_Init(GPIOB, &gpioInit);

    gpioInit.Mode = GPIO_MODE_AF_PP;
    gpioInit.Pin = GPIO_PIN_4;
    gpioInit.Pull = GPIO_NOPULL;
    gpioInit.Speed = GPIO_SPEED_FREQ_HIGH;
    gpioInit.Alternate = GPIO_AF8_SPI6;
    HAL_GPIO_Init(GPIOB, &gpioInit);

    // pins config
    __HAL_RCC_GPIOC_CLK_ENABLE();
    __HAL_RCC_GPIOB_CLK_ENABLE();
    __HAL_RCC_GPIOE_CLK_ENABLE();

    // address pins
    gpioInit.Alternate = 0;
    gpioInit.Mode = GPIO_MODE_OUTPUT_PP;
    gpioInit.Pull = GPIO_NOPULL;
    gpioInit.Speed = GPIO_SPEED_FREQ_HIGH;
    gpioInit.Pin = A0_PIN;
    HAL_GPIO_Init(A0_GPIO, &gpioInit);
    gpioInit.Pin = A1_PIN;
    HAL_GPIO_Init(A1_GPIO, &gpioInit);
    gpioInit.Pin = A2_PIN;
    HAL_GPIO_Init(A2_GPIO, &gpioInit);
    gpioInit.Pin = A3_PIN;
    HAL_GPIO_Init(A3_GPIO, &gpioInit);
    // set to channel 12
    HAL_GPIO_WritePin(A0_GPIO, A0_PIN, GPIO_PIN_RESET);
    HAL_GPIO_WritePin(A1_GPIO, A1_PIN, GPIO_PIN_RESET);
    HAL_GPIO_WritePin(A2_GPIO, A2_PIN, GPIO_PIN_SET);
    HAL_GPIO_WritePin(A3_GPIO, A3_PIN, GPIO_PIN_SET);
    // read write pin
    gpioInit.Pin = WRITE_READ_PIN;
    HAL_GPIO_Init(WRITE_READ_GPIO, &gpioInit);
    
    // irq
    gpioInit.Alternate = 0;
    gpioInit.Pin = IRQ_PIN;
    gpioInit.Pull = GPIO_PULLDOWN;
    gpioInit.Mode = GPIO_MODE_IT_FALLING;
    gpioInit.Speed = GPIO_SPEED_FREQ_HIGH;
    HAL_GPIO_Init(IRQ_GPIO, &gpioInit);
    HAL_NVIC_EnableIRQ(IRQ_IRQn);
    HAL_NVIC_SetPriority(IRQ_IRQn, 10, 0);

    // spi dma init
    __HAL_RCC_BDMA_CLK_ENABLE();
    hdma_.Instance = BDMA_Channel0;
    hdma_.Init.Request = BDMA_REQUEST_SPI6_RX;
    hdma_.Init.Direction = DMA_PERIPH_TO_MEMORY;
    hdma_.Init.PeriphInc = DMA_PINC_DISABLE;
    hdma_.Init.MemInc = DMA_MINC_ENABLE;
    hdma_.Init.PeriphDataAlignment = DMA_PDATAALIGN_BYTE;
    hdma_.Init.MemDataAlignment = DMA_MDATAALIGN_BYTE;
    hdma_.Init.Mode = DMA_NORMAL;
    hdma_.Init.Priority = DMA_PRIORITY_VERY_HIGH;
    hdma_.Init.FIFOMode = DMA_FIFOMODE_DISABLE;
    HAL_DMA_Init(&hdma_);

    hspi_.hdmarx = &hdma_;
    hdma_.Parent = &hspi_;
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

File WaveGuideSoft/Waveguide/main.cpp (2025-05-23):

#include "bsp/MCU.hpp"
#include "bsp/DebugIO.hpp"
#include "bsp/UC1638.hpp"
#include "bsp/PCM5102.hpp"
#include "bsp/USBMidi.hpp"
#include "bsp/ControlIO.hpp"
#include "bsp/MPR121.hpp"
#include "bsp/Keyboard.hpp"

#include "gui/GuiDispatch.hpp"
#include "gui/obj/Main.hpp"
#include "gui/obj/Scope.hpp"

#include "dsp/Synth.hpp"
#include "utli/Clamp.hpp"
#include "utli/Map.hpp"

#include "FreeRTOS.h"
#include "task.h"
#include "semphr.h"

#include "MemAttributes.hpp"
#include "SystemHook.hpp"
#include "MidiManager.hpp"
#include <cmath>

using bsp::Debug;

// --------------------------------------------------------------------------------
// DAC
// --------------------------------------------------------------------------------
static StaticTask_t dacTaskBuffer;
MEM_NOINIT_SRAMD1 static StackType_t dacTaskStack[8192];
static float synthBuffer[bsp::CPCM5102::kBlockSize];
static float auxSynthBuffer[bsp::CPCM5102::kBlockSize];
static float volume_ = 1.0f;
static void DACTaskInit() {
    APP_LOG("main", "start dac");
    dsp::SynthParams.volume.SetCallback([] {
        auto db = dsp::SynthParams.volume.Get();
        volume_ = std::pow(10.0f, db / 20.0f);
    });
    xTaskCreateStatic(
        [](void*) {
            using bsp::PCM5102;
            PCM5102.Init();
            dsp::Synth.Init(PCM5102.kSampleRate);
            MidiManager.Init(PCM5102.kSampleRate / PCM5102.kBlockSize);
            dsp::gSafeCallback.MarkAll();
            PCM5102.Start();
            for (;;) {
                auto block = PCM5102.GetNextBlock();
                TickType_t tickBegin = xTaskGetTickCount();

                // handle datas
                MidiManager.Lock();
                MidiManager.BackupState();
                MidiManager.Unlock();
                
                { // handle notes
                    auto diff = MidiManager.GetDiff0();
                    while (diff) {
                        auto idx = __builtin_ctzl(diff);
                        if (MidiManager.GetVelocity(idx) > 0) {
                            dsp::Synth.NoteOn(MidiManager.GetChannelOfNote(idx), idx, MidiManager.GetVelocity(idx));
                        }
                        else {
                            dsp::Synth.NoteOff(idx);
                        }
                        diff &= ~(MidiManager.kOne << idx);
                    }
                    diff = MidiManager.GetDiff1();
                    while (diff) {
                        auto idx = __builtin_ctzl(diff);
                        auto note = idx + 32;
                        if (MidiManager.GetVelocity(note) > 0) {
                            dsp::Synth.NoteOn(MidiManager.GetChannelOfNote(note), note, MidiManager.GetVelocity(note));
                        }
                        else {
                            dsp::Synth.NoteOff(note);
                        }
                        diff &= ~(MidiManager.kOne << idx);
                    }
                    diff = MidiManager.GetDiff2();
                    while (diff) {
                        auto idx = __builtin_ctzl(diff);
                        auto note = idx + 64;
                        if (MidiManager.GetVelocity(note) > 0) {
                            dsp::Synth.NoteOn(MidiManager.GetChannelOfNote(note), note, MidiManager.GetVelocity(note));
                        }
                        else {
                            dsp::Synth.NoteOff(note);
                        }
                        diff &= ~(MidiManager.kOne << idx);
                    }
                    diff = MidiManager.GetDiff3();
                    while (diff) {
                        auto idx = __builtin_ctzl(diff);
                        auto note = idx + 96;
                        if (MidiManager.GetVelocity(note) > 0) {
                            dsp::Synth.NoteOn(MidiManager.GetChannelOfNote(note), note, MidiManager.GetVelocity(note));
                        }
                        else {
                            dsp::Synth.NoteOff(note);
                        }
                        diff &= ~(MidiManager.kOne << idx);
                    }
                }

                // handle parameter changes
                dsp::gSafeCallback.HandleDirtyCallbacks();

                // process audio
                dsp::Synth.Process(synthBuffer, auxSynthBuffer);

                // mix in
                for (uint32_t i = 0; i < bsp::CPCM5102::kBlockSize; i++) {
                    synthBuffer[i] *= volume_;
                    auto left = synthBuffer[i] * 16384;
                    left = dsp::ClampUncheck(left, -32768, 32767);
                    auto iLeft = static_cast<int16_t>(left);
                    block[i].left = iLeft;
                    auxSynthBuffer[i] *= volume_;
                    auto right = auxSynthBuffer[i] * 16384;
                    right = dsp::ClampUncheck(right, -32768, 32767);
                    auto iRight = static_cast<int16_t>(right);
                    block[i].right = iRight;
                }
                gui::Scope.Push(std::span{synthBuffer, bsp::CPCM5102::kBlockSize});

                TickType_t tickEnd = xTaskGetTickCount();
                gui::Main.SetDacTaskMs(pdTICKS_TO_MS(tickEnd - tickBegin));
            }
        },
        "DAC",
        std::size(dacTaskStack),
        nullptr,
        3,
        dacTaskStack,
        &dacTaskBuffer
    );
}
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

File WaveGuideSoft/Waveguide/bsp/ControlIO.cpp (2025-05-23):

#include "ControlIO.hpp"

#include <array>

#include "stm32h7xx_hal.h"
#include "stm32h7xx_ll_exti.h"
#include "stm32h7xx_ll_gpio.h"

#include "FreeRTOS.h"
#include "timers.h"
#include "semphr.h"

#include "SystemHook.hpp"
#include "MemAttributes.hpp"
#include "bsp/DebugIO.hpp"

// enacoder 1
#define ECA1_GPIO GPIOA
#define ECA1_PIN GPIO_PIN_3
#define ECA2_GPIO GPIOA
#define ECA2_PIN GPIO_PIN_2
#define ECA_IRQn EXTI3_IRQn
// enacoder 2
#define ECB1_GPIO GPIOA
#define ECB1_PIN GPIO_PIN_1
#define ECB2_GPIO GPIOA
#define ECB2_PIN GPIO_PIN_0
#define ECB_IRQn EXTI1_IRQn

namespace bsp {

static int32_t encoderValues_[CControlIO::kNumEncoders]{};
static uint32_t prevButtonState_{ 0xffffffff };
static uint32_t currButtonState_{ 0xffffffff };
static uint32_t tick_{};
static CControlIO::BtnCallback btnCallbacks_[CControlIO::kNumButtons]{};
static CControlIO::EncoderCallback encoderCallbacks_[CControlIO::kNumEncoders]{};

inline static void NullBtnCallback(ButtonEventArgs) {};
inline static void NullEncoderCallback(int32_t) {};

void CControlIO::Init() {
    /* 按键初始化 */
    __HAL_RCC_GPIOE_CLK_ENABLE();
    GPIO_InitTypeDef init{};
    init.Mode = GPIO_MODE_INPUT;
    init.Pin = GPIO_PIN_5 | GPIO_PIN_6 | GPIO_PIN_7 | GPIO_PIN_8 | GPIO_PIN_9 | GPIO_PIN_10 | GPIO_PIN_11 | GPIO_PIN_12 | GPIO_PIN_13 | GPIO_PIN_14;
    init.Pull = GPIO_PULLUP;
    init.Speed = GPIO_SPEED_FREQ_HIGH;
    HAL_GPIO_Init(GPIOE, &init);

    /* 编码器初始化 */
    __HAL_RCC_GPIOA_CLK_ENABLE();
    GPIO_InitTypeDef gpioInit{};
    gpioInit.Alternate = 0;
    gpioInit.Mode = GPIO_MODE_INPUT;
    gpioInit.Pin = ECA2_PIN;
    gpioInit.Pull = GPIO_NOPULL;
    gpioInit.Speed = GPIO_SPEED_FREQ_LOW;
    HAL_GPIO_Init(ECA2_GPIO, &gpioInit);
    gpioInit.Pin = ECB2_PIN;
    HAL_GPIO_Init(ECB2_GPIO, &gpioInit);
    gpioInit.Mode = GPIO_MODE_IT_RISING_FALLING;
    gpioInit.Pin = ECA1_PIN;
    HAL_GPIO_Init(ECA1_GPIO, &gpioInit);
    gpioInit.Pin = ECB1_PIN;
    HAL_GPIO_Init(ECB1_GPIO, &gpioInit);
    HAL_NVIC_SetPriority(ECA_IRQn, 10, 0);
    HAL_NVIC_EnableIRQ(ECA_IRQn);
    HAL_NVIC_SetPriority(ECB_IRQn, 10, 0);
    HAL_NVIC_EnableIRQ(ECB_IRQn);

    // reset callbacks
    std::fill_n(btnCallbacks_, kNumButtons, NullBtnCallback);
    std::fill_n(encoderCallbacks_, kNumEncoders, NullEncoderCallback);
}

void CControlIO::WaitForNextEvent() {
    xTaskDelayUntil(&tick_, pdMS_TO_TICKS(kScanMs));
    prevButtonState_ = currButtonState_;
    currButtonState_ = LL_GPIO_ReadInputPort(GPIOE);
}

void CControlIO::ProcessButtonEvents() {
    uint32_t mask = 1 << 14;
    for (uint32_t i = 0; i < kNumButtons; ++i) {
        auto changed = currButtonState_ ^ prevButtonState_;
        auto pressed = currButtonState_ & mask;
        auto state = ButtonState::kAttack;
        if (changed & mask) {
            if (pressed) {
                state = ButtonState::kAttack;
            }
            else {
                state = ButtonState::kRelease;
            }
        }
        else {
            if (pressed) {
                state = ButtonState::kHold;
            }
            else {
                state = ButtonState::kInit;
            }
        }
        if (state != ButtonState::kInit) {
            btnCallbacks_[i](state);
        }
        mask >>= 1;
    }
}

void CControlIO::ProcessEncoderEvents() {
    for (uint32_t i = 0; i < kNumEncoders; ++i) {
        if (encoderValues_[i] != 0) {
            encoderCallbacks_[i](encoderValues_[i]);
            encoderValues_[i] = 0;
        }
    }
}

void CControlIO::SetButtonCallback(ButtonId id, BtnCallback callback) {
    btnCallbacks_[static_cast<uint32_t>(id)] = callback;
}

void CControlIO::SetEncoderCallback(EncoderId id, EncoderCallback callback) {
    encoderCallbacks_[static_cast<uint32_t>(id)] = callback;
}

void CControlIO::UnsetButtonCallback(ButtonId id) {
    btnCallbacks_[static_cast<uint32_t>(id)] = NullBtnCallback;
}

void CControlIO::UnsetEncoderCallback(EncoderId id) {
    encoderCallbacks_[static_cast<uint32_t>(id)] = NullEncoderCallback;
}

void CControlIO::ResetButtonCallbacks() {
    std::fill_n(btnCallbacks_, kNumButtons, NullBtnCallback);
}

void CControlIO::ResetEncoderCallbacks() {
    std::fill_n(encoderCallbacks_, kNumEncoders, NullEncoderCallback);
}

static struct {
    bool flag1 : 1;
    bool init_nu1 : 1;
    bool flag2 : 1;
    bool init_nu2 : 1;
    bool flag3 : 1;
    bool init_nu3 : 1;
    bool flag4 : 1;
    bool init_nu4 : 1;
} encoderIrqFlags{};

void AddEncoderValue(EncoderId id, int32_t value) {
    auto idx = static_cast<uint32_t>(id);
    encoderValues_[idx] += value;
}

extern "C" void EXTI3_IRQHandler(void) {
    LL_EXTI_ClearFlag_0_31(LL_EXTI_LINE_3);
    auto keya = LL_GPIO_ReadInputPort(ECA1_GPIO) & ECA1_PIN;
    auto keyb = LL_GPIO_ReadInputPort(ECA2_GPIO) & ECA2_PIN;
    if (!encoderIrqFlags.init_nu1 && !keya) {
        encoderIrqFlags.flag1 = false;
        if (keyb) {
            encoderIrqFlags.flag1 = true;
        }
        encoderIrqFlags.init_nu1 = true;
    }

    if (encoderIrqFlags.init_nu1 && keya) {
        if (!keyb && encoderIrqFlags.flag1) {
            AddEncoderValue(EncoderId::kParam, -1);
        }
        if (keyb && !encoderIrqFlags.flag1) {
            AddEncoderValue(EncoderId::kParam, 1);
        }
        encoderIrqFlags.init_nu1 = false;
    }
}

extern "C" void EXTI1_IRQHandler(void) {
    LL_EXTI_ClearFlag_0_31(LL_EXTI_LINE_1);
    auto keya = LL_GPIO_ReadInputPort(ECB1_GPIO) & ECB1_PIN;
    auto keyb = LL_GPIO_ReadInputPort(ECB2_GPIO) & ECB2_PIN;

    if (!encoderIrqFlags.init_nu2 && !keya) {
        encoderIrqFlags.flag2 = false;
        if (keyb) {
            encoderIrqFlags.flag2 = true;
        }
        encoderIrqFlags.init_nu2 = true;
    }

    if (encoderIrqFlags.init_nu2 && keya) {
        if (!keyb && encoderIrqFlags.flag2) {
            AddEncoderValue(EncoderId::kValue, -1);
        }
        if (keyb && !encoderIrqFlags.flag2) {
            AddEncoderValue(EncoderId::kValue, 1);
        }
        encoderIrqFlags.init_nu2 = false;
    }
}

}

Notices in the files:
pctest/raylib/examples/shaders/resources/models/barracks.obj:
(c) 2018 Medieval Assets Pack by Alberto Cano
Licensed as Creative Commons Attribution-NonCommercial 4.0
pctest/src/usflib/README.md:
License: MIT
